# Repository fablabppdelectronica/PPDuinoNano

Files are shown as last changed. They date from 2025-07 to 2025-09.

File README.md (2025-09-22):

# MÓDULO EDUCATIVO: PPDuino Nano
## Presentación
Los módulos educativos son una herramienta invaluable para los estudiantes, que les permite aprender de forma tangible y efectiva los conocimientos de cada Unidad Didáctica.

El presente proyecto es una iniciativa innovadora que busca desarrollar un **módulo educativo de codigo abierto** que permitirá realizar los laboratorios de multiples unidades d

idáctica, que lo puedan fabricar los docentes o estudiantes y que permita trabajar con:
- Electrónica Analógica
- Electrónica Digital
- Electrónica Potencia
- Programación Embebida
- Redes
- Telecomunicaciones, entre otras.

El proyecto esta desarrollado por los docentes y estudiantes del Programa de Electronica Industrial.
## Proyecto PPDuino
Para esta primera etapa e inspirados por dispositivos PLCs como el S7-1200 y Logo de Siemens, el objetivo es disenar y fabricar un módulo educativo tipo PLC.

Se trabajara en 3 areas:
- Diseño Electronico.
- Diseño 2D y 3D.
- Programación.

Mostramos el bosquejo proyectado. 
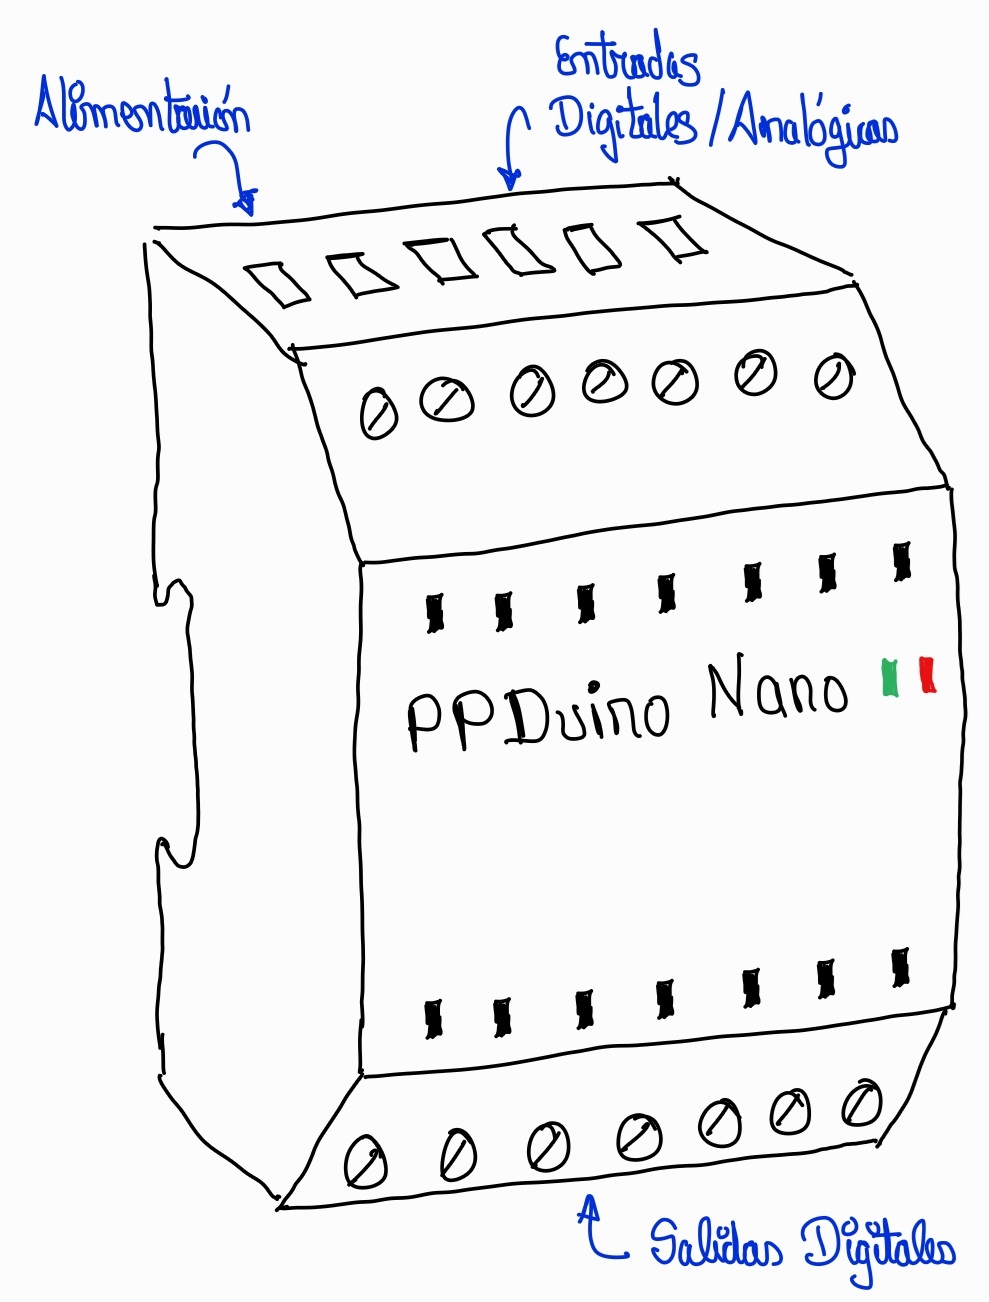
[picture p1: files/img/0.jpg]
<div></div>
Para conseguir el Producto Mínimo Viable, se siguieron la secuencia que se muestra en la imagen:
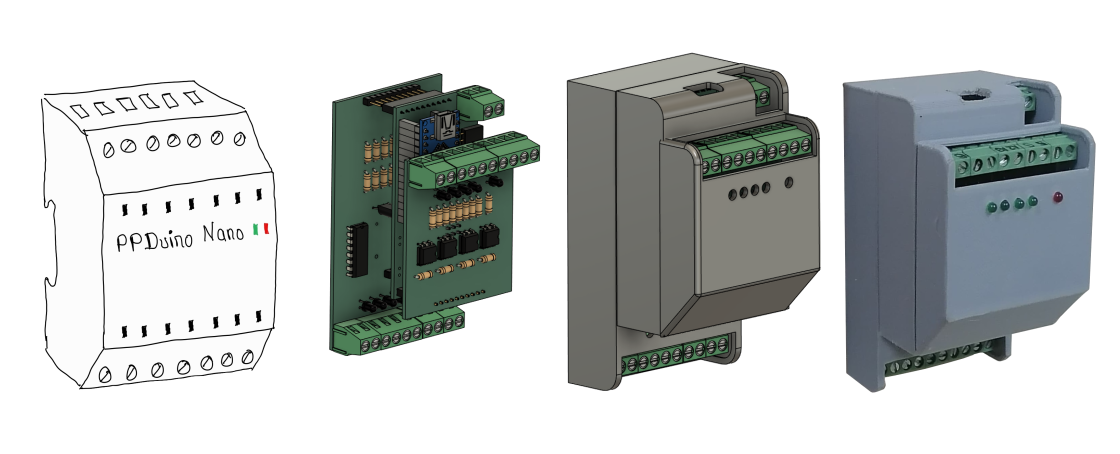
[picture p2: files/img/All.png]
<div></div>

## Diseño Electrónico
### Tarjeta de procesador
Para el desarrollo de la tarjeta del procesador, se trabajo con la tarjeta Arduino Nano por su gran comunidad, facilidad de adquisión local y costo accesible.

#### Lista de componentes
<table><tr><th>Reference</th><td>Value</td><td>Footprint</td><td>Qty</td></tr><tr><th>A1</th><td>Arduino Nano</td><td>Module:Arduino_Nano</td><td>1</td></tr><tr><th>C1</th><td>100uF</td><td>Capacitor_THT:CP_Radial_D5.0mm_P2.50mm</td><td>1</td></tr><tr><th>C2</th><td>10uF</td><td>Capacitor_THT:CP_Radial_D5.0mm_P2.50mm</td><td>1</td></tr><tr><th>J1</th><td>PWR_IN</td><td>Borneras:TerminalBlock_Altech_AK300-2_P5.00mm</td><td>1</td></tr><tr><th>J2</th><td>Conn_01x12</td><td>Connector_PinSocket_2.54mm:PinSocket_1x12_P2.54mm_Horizontal</td><td>1</td></tr><tr><th>J11</th><td>INPUTS</td><td>Connector_PinSocket_2.54mm:PinSocket_1x10_P2.54mm_Vertical</td><td>1</td></tr><tr><th>J12</th><td>OUTPUTS</td><td>Connector_PinHeader_2.54mm:PinHeader_1x10_P2.54mm_Vertical</td><td>1</td></tr><tr><th>U1</th><td>L7805</td><td>Package_TO_SOT_THT:TO-220-3_Horizontal_TabDown</td><td>1</td></tr><tr><th>U6</th><td>+5V</td><td>Codigo_lib:Mini 560 Pro</td><td>1</td></tr></table>

#### Esquematico de procesador
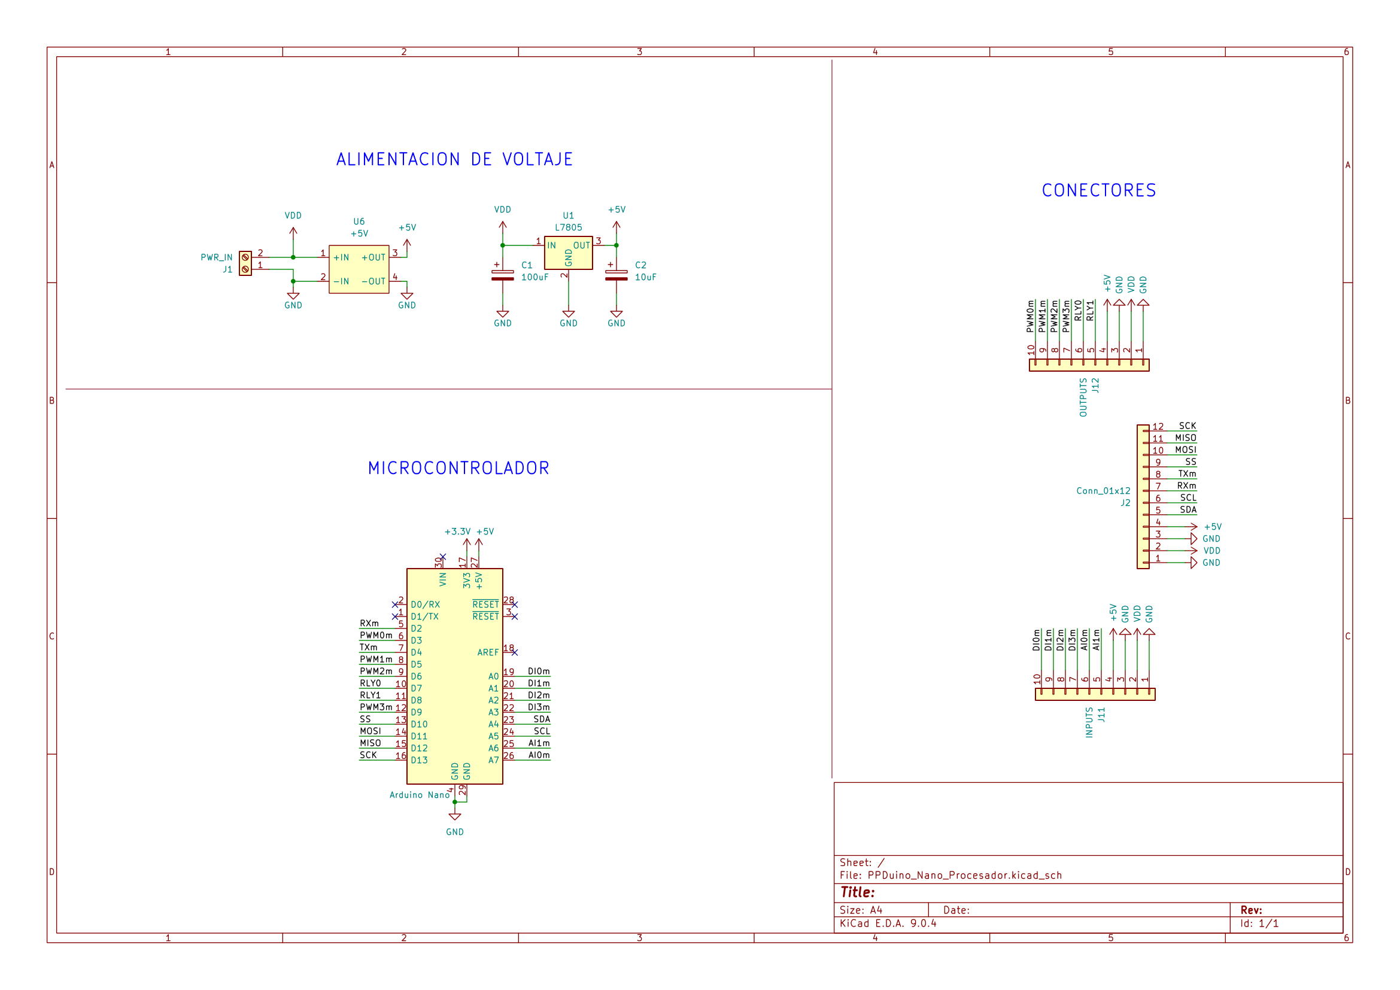
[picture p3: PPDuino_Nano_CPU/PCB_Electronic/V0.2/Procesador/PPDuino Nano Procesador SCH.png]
<div></div>

### Entradas
### Tarjeta de entradas
Para el desarrollo de la tarjeta de entradas se diseño para proporcionar:
* 4 entradas digitales desde +5V a +24V (dependera del voltaje de alimentación)
* 2 entradas analogicas de 0V a +5V epcon la tarjeta Arduino Nano por su gran comunidad, facilidad de adquisión local y costo accesible.

#### Lista de componentes
<table><tr><th>Reference</th><td>Value</td><td>Footprint</td><td>Qty</td></tr><tr><th>D1</th><td>DI0</td><td>LED_THT:LED_D3.0mm_IRBlack</td><td>1</td></tr><tr><th>D2</th><td>DI1</td><td>LED_THT:LED_D3.0mm_IRBlack</td><td>1</td></tr><tr><th>D3</th><td>DI2</td><td>LED_THT:LED_D3.0mm_IRBlack</td><td>1</td></tr><tr><th>D4,D5</th><td>DI3</td><td>LED_THT:LED_D3.0mm_IRBlack</td><td>2</td></tr><tr><th>D6,D7</th><td>Z5.1V</td><td>Diode_THT:D_DO-35_SOD27_P7.62mm_Horizontal</td><td>2</td></tr><tr><th>J2</th><td>DI</td><td>Borneras:TerminalBlock_Altech_AK300-4_P5.00mm</td><td>1</td></tr><tr><th>J3</th><td>AI</td><td>Borneras:TerminalBlock_Altech_AK300-4_P5.00mm</td><td>1</td></tr><tr><th>J10</th><td>PWR_OUT</td><td>Borneras:TerminalBlock_Altech_AK300-2_P5.00mm</td><td>1</td></tr><tr><th>J11</th><td>INPUTS</td><td>Connector_PinHeader_2.54mm:PinHeader_1x10_P2.54mm_Vertical</td><td>1</td></tr><tr><th>Q1,Q2,Q3,Q4</th><td>BC548</td><td>Package_TO_SOT_THT:TO-92L_Inline_Wide</td><td>4</td></tr><tr><th>R1,R2,R3,R4,R5,<br>R6,R7,R8,R9,R10,<br>R11,R12,R14,<br>R15,R16,R17</th><td>2.2k</td><td>Resistor_THT:R_Axial_DIN0207_L6.3mm_D2.5mm_P7.62mm_Horizontal</td><td>16</td></tr><tr><th>R13</th><td>1k</td><td>Resistor_THT:R_Axial_DIN0207_L6.3mm_D2.5mm_P7.62mm_Horizontal</td><td>1</td></tr></table>

#### Esquematico de entradas
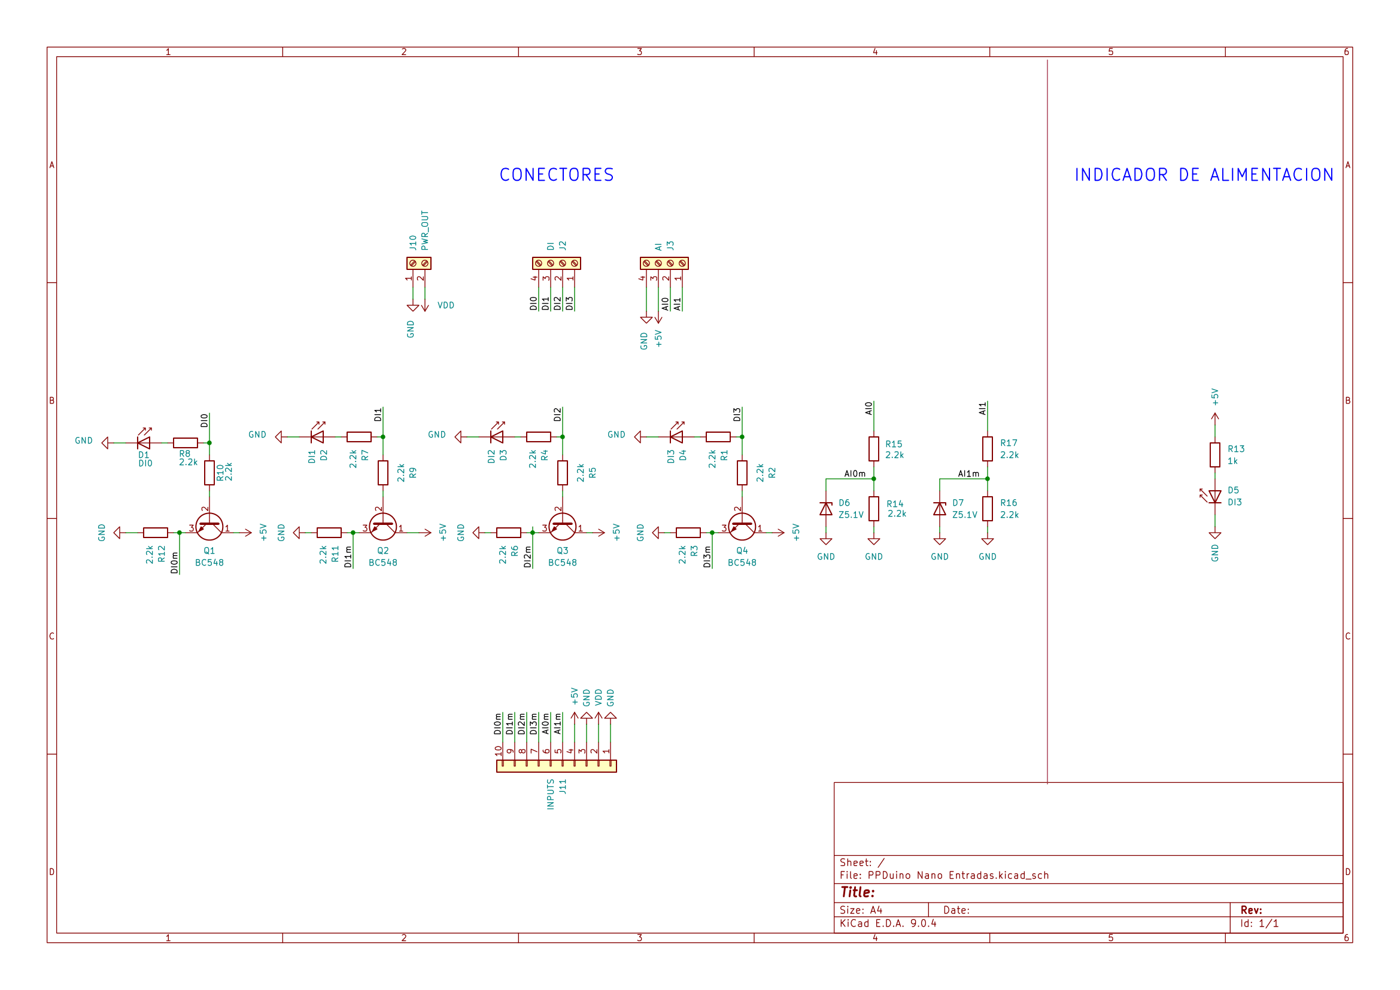
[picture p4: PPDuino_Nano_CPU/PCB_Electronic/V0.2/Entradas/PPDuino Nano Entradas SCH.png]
<div></div>

### Salidas
### Tarjeta de salidas
Para el desarrollo de la tarjeta del procesador, se tabajo con la tarjeta Arduino Nano por su gran comunidad, facilidad de adquisión local y costo accesible.

#### Lista de componentes
<table><tr><th>Reference</th><td>Value</td><td>Footprint</td><td>Qty</td></tr><tr><th>D5,J14</th><td>RLY0</td><td>Borneras:TerminalBlock_Altech_AK300-2_P5.00mm,LED_THT:LED_D3.0mm_IRBlack</td><td>2</td></tr><tr><th>D6,D8</th><td>1N4148</td><td>Diode_THT:D_DO-35_SOD27_P7.62mm_Horizontal</td><td>2</td></tr><tr><th>D7,J7</th><td>RLY1</td><td>Borneras:TerminalBlock_Altech_AK300-2_P5.00mm,LED_THT:LED_D3.0mm_IRBlack</td><td>2</td></tr><tr><th>D9</th><td>DI3</td><td>LED_THT:LED_D3.0mm_IRBlack</td><td>1</td></tr><tr><th>D10</th><td>DI2</td><td>LED_THT:LED_D3.0mm_IRBlack</td><td>1</td></tr><tr><th>D11</th><td>DI1</td><td>LED_THT:LED_D3.0mm_IRBlack</td><td>1</td></tr><tr><th>D12</th><td>DI0</td><td>LED_THT:LED_D3.0mm_IRBlack</td><td>1</td></tr><tr><th>J6</th><td>SEL0</td><td>Connector_PinHeader_2.54mm:PinHeader_1x03_P2.54mm_Vertical</td><td>1</td></tr><tr><th>J8</th><td>PWM</td><td>Borneras:TerminalBlock_Altech_AK300-4_P5.00mm</td><td>1</td></tr><tr><th>J9</th><td>PWR_OUT</td><td>Borneras:TerminalBlock_Altech_AK300-2_P5.00mm</td><td>1</td></tr><tr><th>J12</th><td>OUTPUTS</td><td>Connector_PinHeader_2.54mm:PinHeader_1x10_P2.54mm_Vertical</td><td>1</td></tr><tr><th>J13</th><td>SEL1</td><td>Connector_PinHeader_2.54mm:PinHeader_1x03_P2.54mm_Vertical</td><td>1</td></tr><tr><th>K1,K2</th><td>~</td><td>Codigo_lib:Relay</td><td>2</td></tr><tr><th>Q1,Q2</th><td>BC548</td><td>Package_TO_SOT_THT:TO-92L_Inline_Wide</td><td>2</td></tr><tr><th>R13,R14,R15,<br>R16,R17,R18,<br>R19,R20</th><td>330</td><td>Resistor_THT:R_Axial_DIN0207_L6.3mm_D2.5mm_P7.62mm_Horizontal</td><td>8</td></tr><tr><th>U5</th><td>L293D</td><td>Package_DIP:DIP-16_W7.62mm_LongPads</td><td>1</td></tr></table>

#### Esquematico de salidas
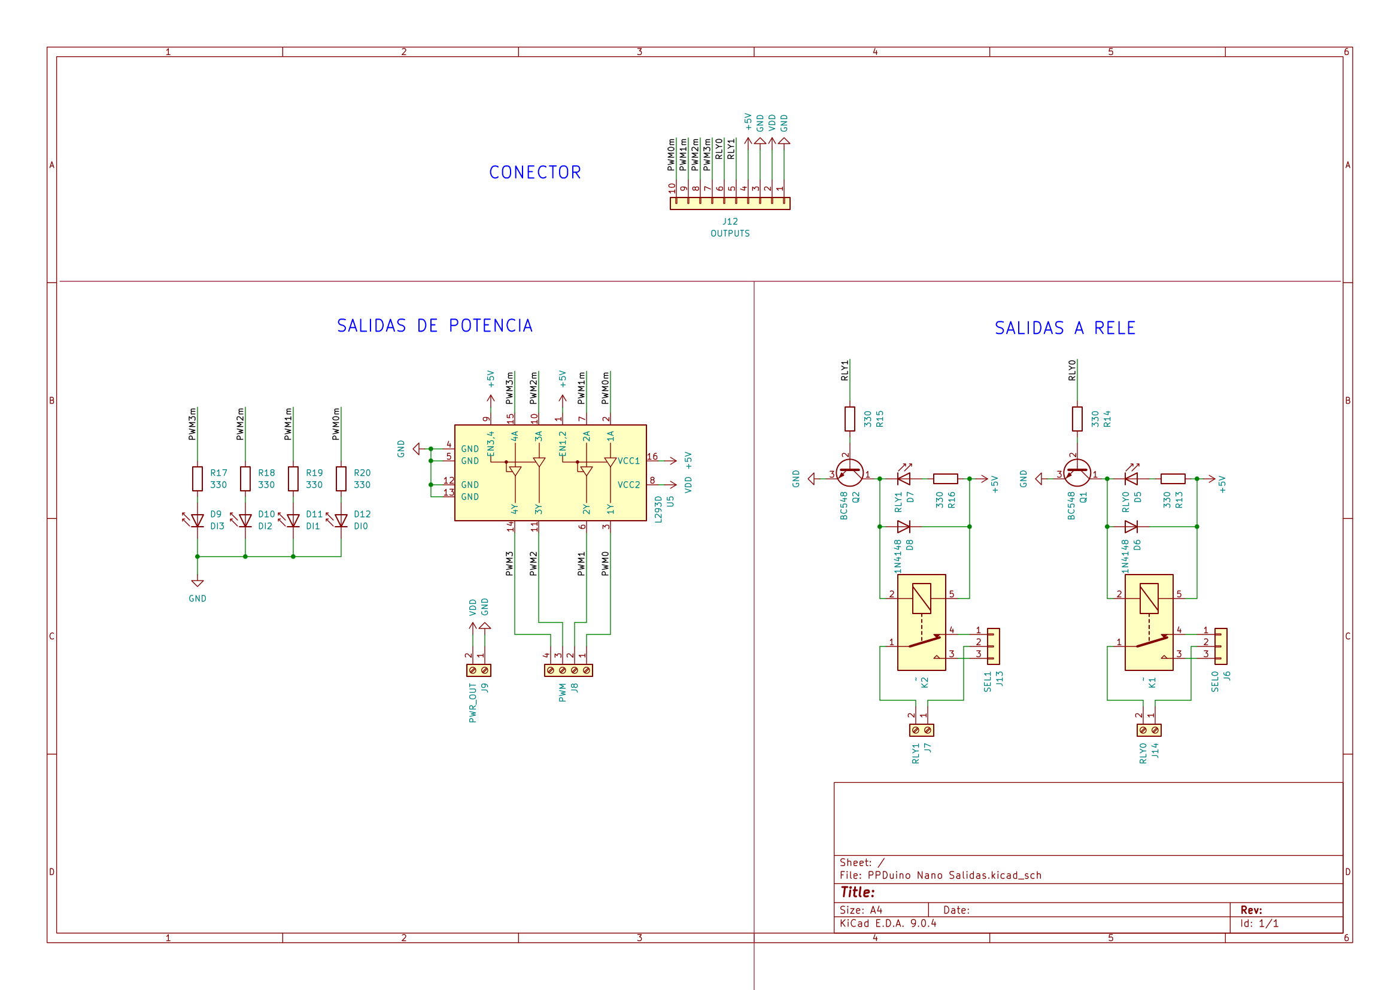
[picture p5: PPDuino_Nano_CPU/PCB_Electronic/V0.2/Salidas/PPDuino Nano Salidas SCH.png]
<div></div>

## Fabricacion
### Impresión 3D
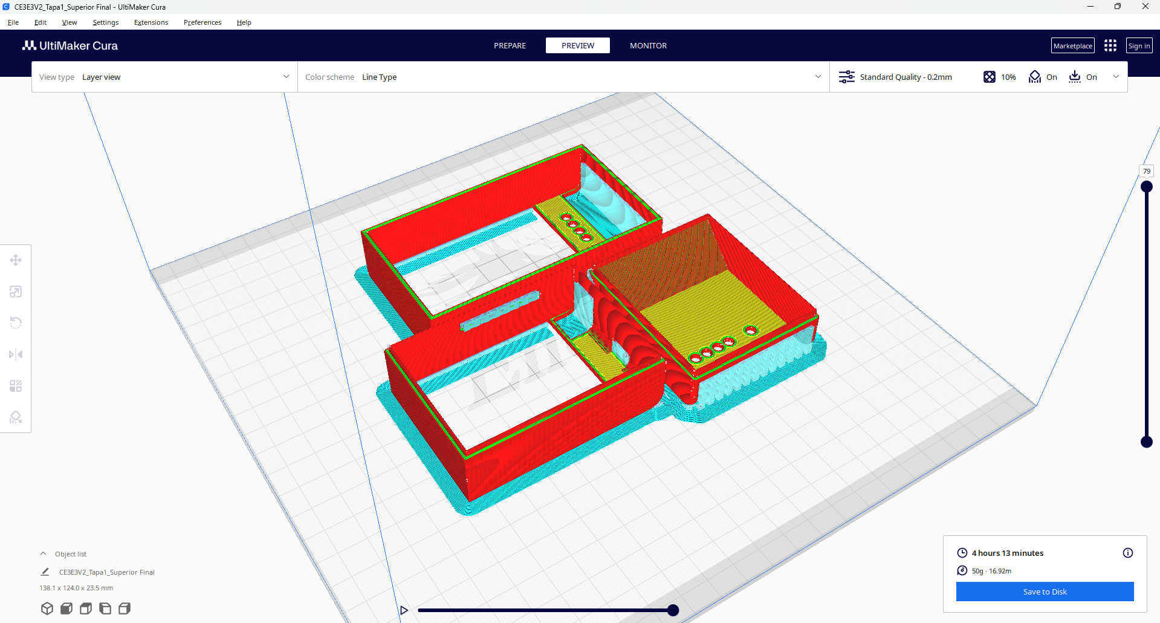
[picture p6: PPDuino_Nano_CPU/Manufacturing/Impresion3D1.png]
<div></div>

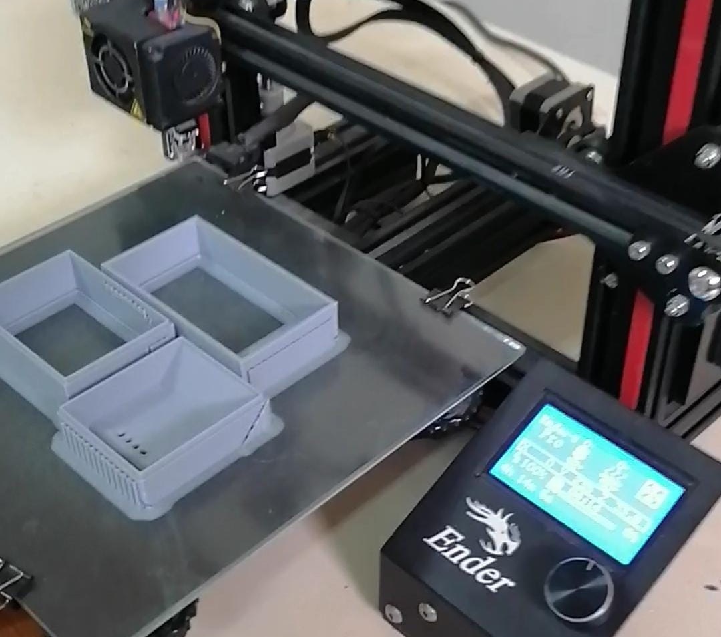
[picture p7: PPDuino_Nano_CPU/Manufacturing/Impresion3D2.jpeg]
<div></div>

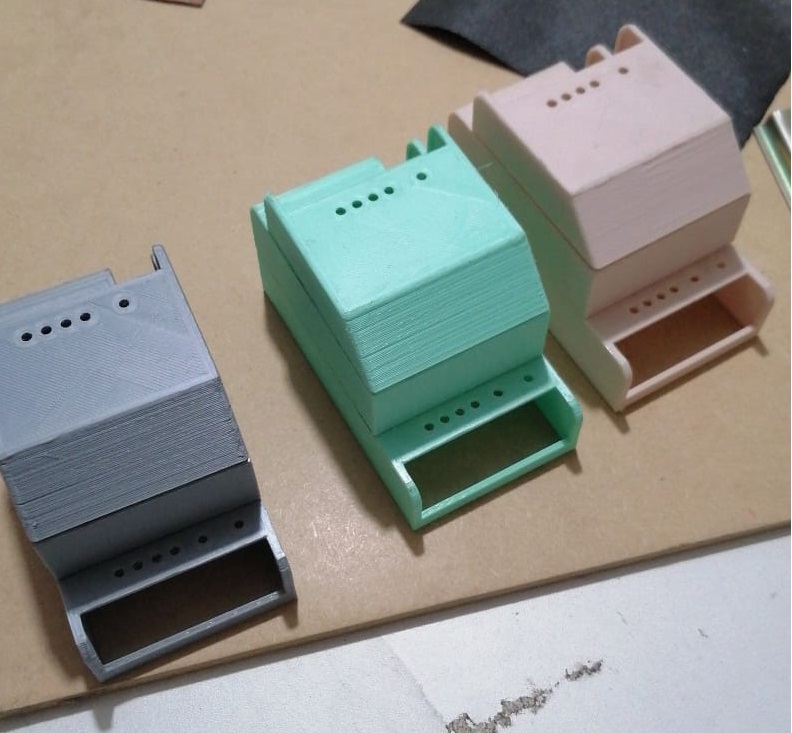
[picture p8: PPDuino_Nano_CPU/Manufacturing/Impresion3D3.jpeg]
<div></div>

### Fabricacion de PCB

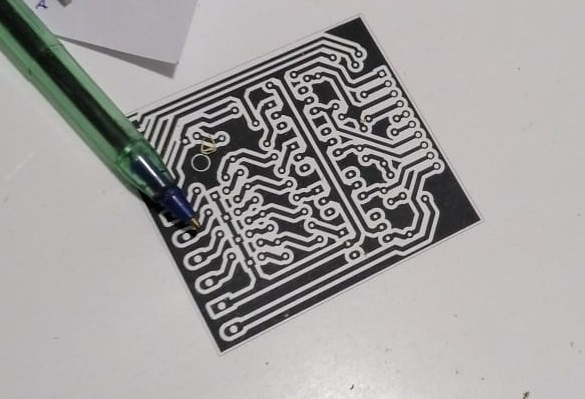
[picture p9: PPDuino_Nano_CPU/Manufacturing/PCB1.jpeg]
<div></div>

## Programación
### Programación con Arduino IDE (C++)

Descarguemos el software para programar el Arduino Nano en [Descargar Arduino IDE](https://www.arduino.cc/en/software/)

Reconoscamos las herramientas de Arduino IDE
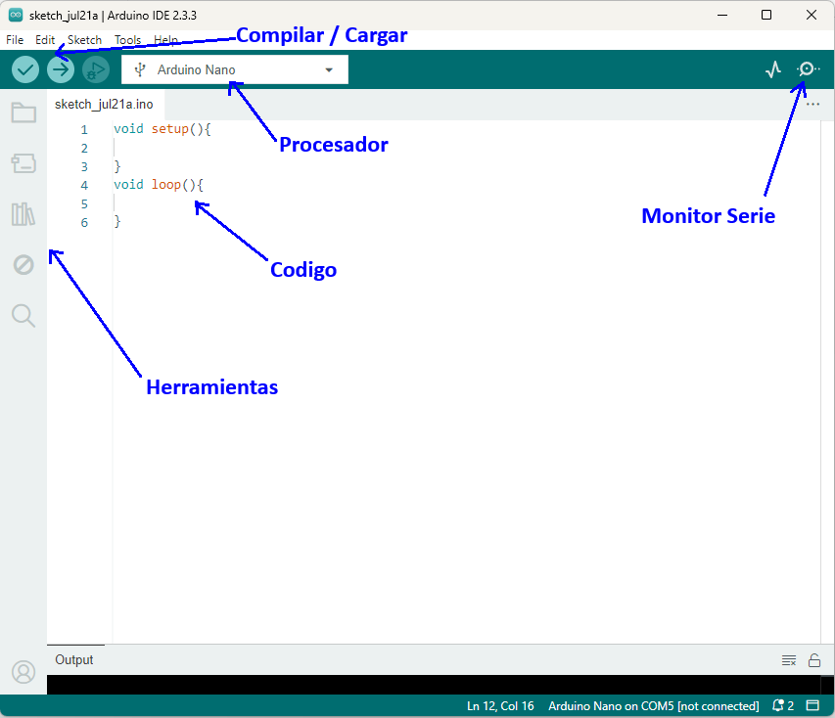
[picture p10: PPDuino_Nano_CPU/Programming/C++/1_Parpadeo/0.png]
<div></div>

Seleccionar en BOARDS: Arduino Nano
Seleccionar en PORTS: COMx (Dependera del puerto asignado desde su computadora)
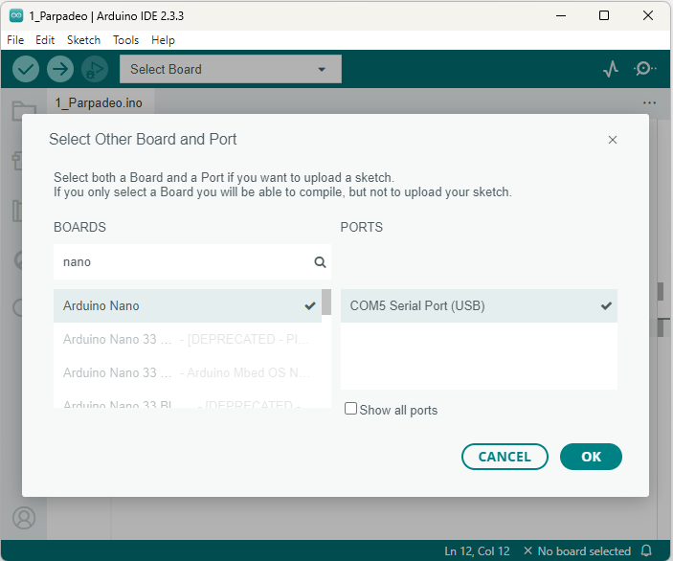
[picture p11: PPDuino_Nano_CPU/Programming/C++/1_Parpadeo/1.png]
<div></div>

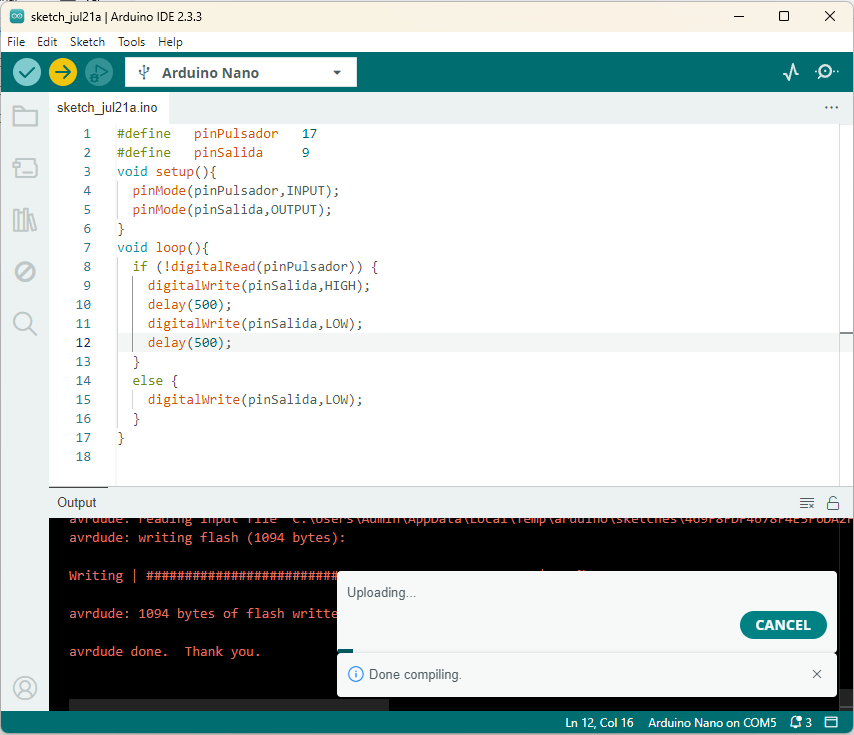
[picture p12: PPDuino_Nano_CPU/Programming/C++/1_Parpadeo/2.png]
<div></div>

### Programación con OpenPLC IDE (Ladder)

Descarguemos el software OpenPLC para programar el Arduino Nano en [Descargar OpenPLC](https://autonomylogic.com/)

Reconoscamos las herramientas de OpenPLC
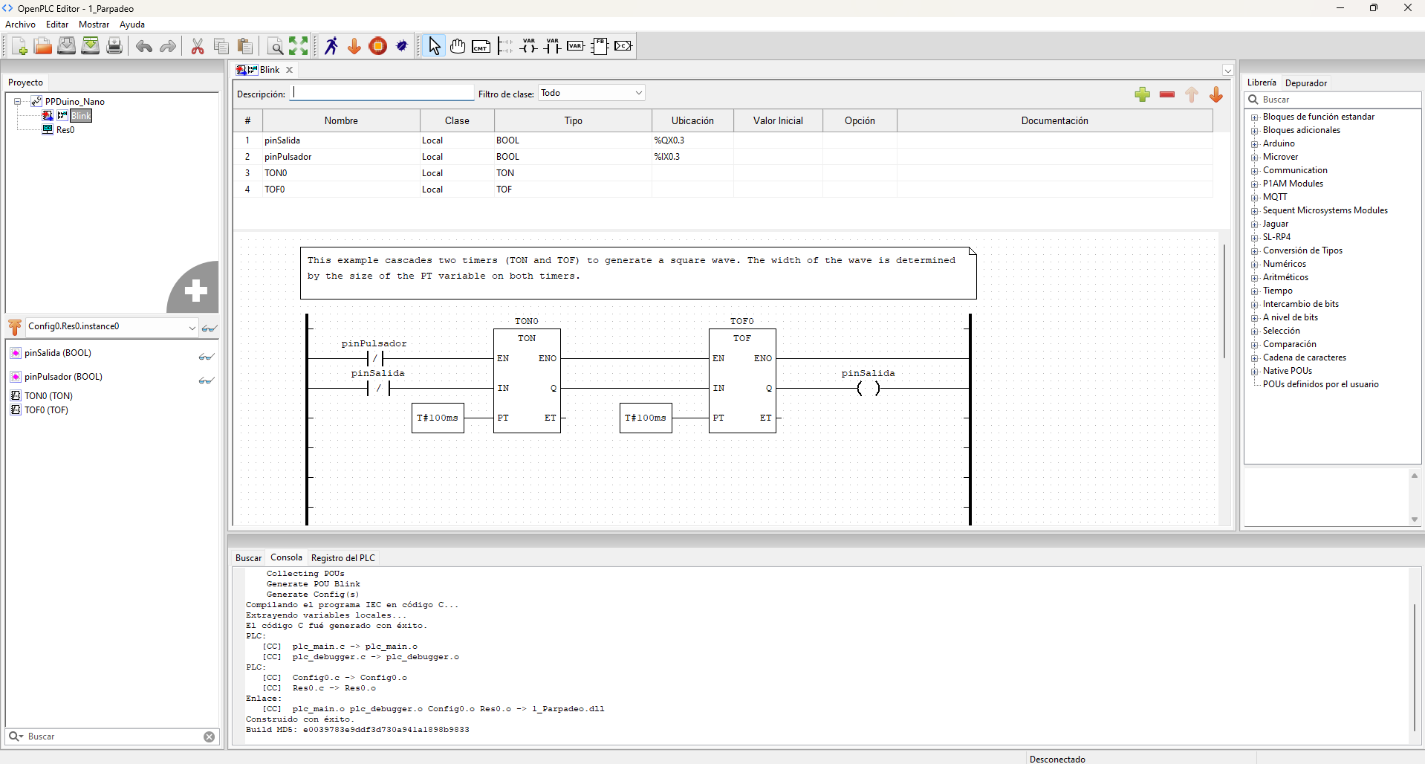
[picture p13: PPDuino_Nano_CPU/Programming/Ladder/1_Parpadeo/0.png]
<div></div>

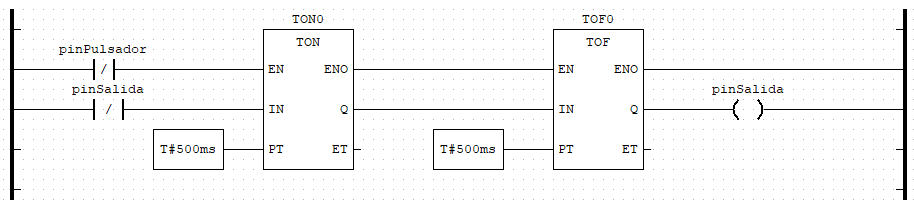
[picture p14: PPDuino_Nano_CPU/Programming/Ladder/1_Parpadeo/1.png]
<div></div>

<div><p style = 'text-align:center;'>JuveYell</p></div>

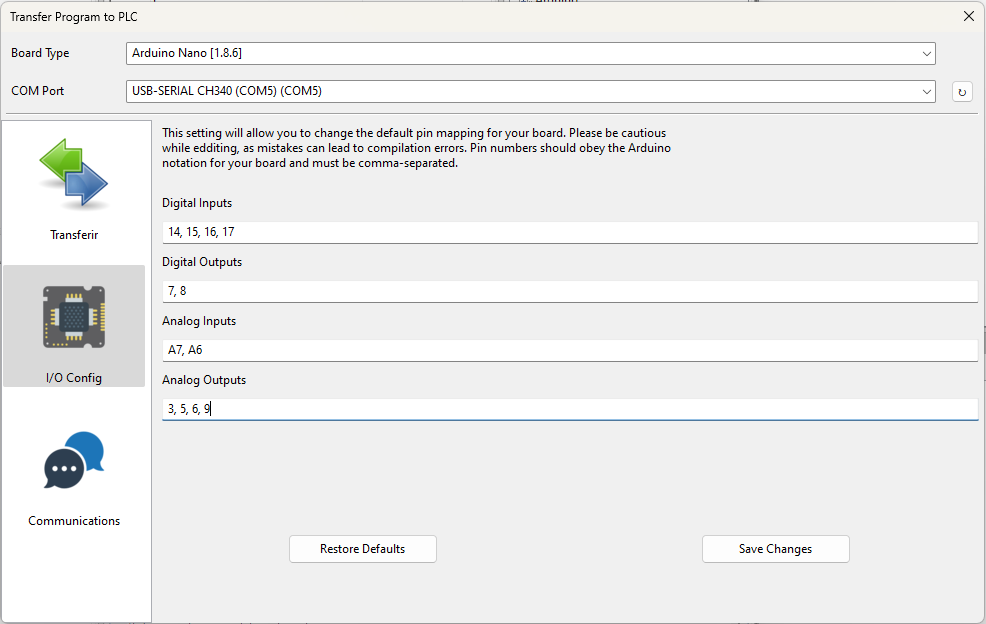
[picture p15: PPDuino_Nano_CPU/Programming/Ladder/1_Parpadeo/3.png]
<div></div>

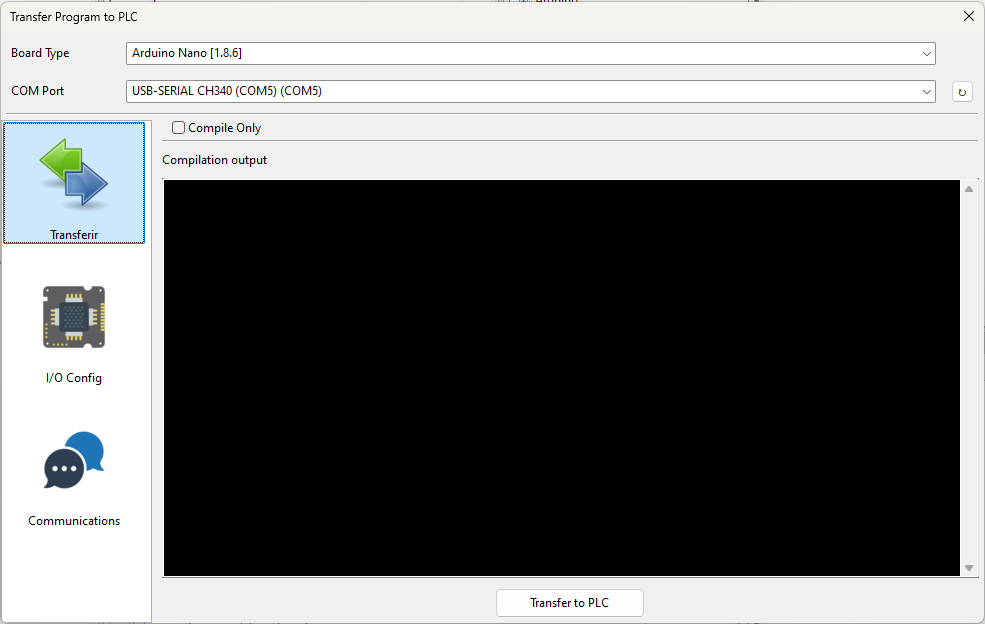
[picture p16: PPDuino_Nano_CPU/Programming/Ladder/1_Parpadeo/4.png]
<div></div>

### Programación con Fab Blocks (Bloques)

Descarguemos el software Fab Blocks IDE para programar el Arduino Nano en [Descargar Fab Blocks IDE](https://github.com/codigospace/Fab-Blocks-IDE/releases)

Reconoscamos las herramientas de Fab Blocks IDE
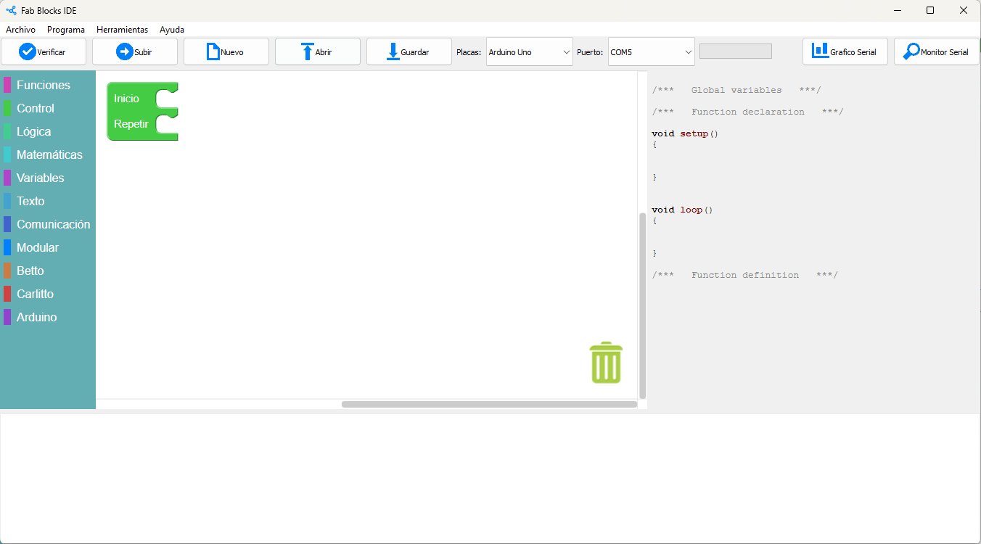
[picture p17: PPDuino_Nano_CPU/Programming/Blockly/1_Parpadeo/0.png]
<div></div>

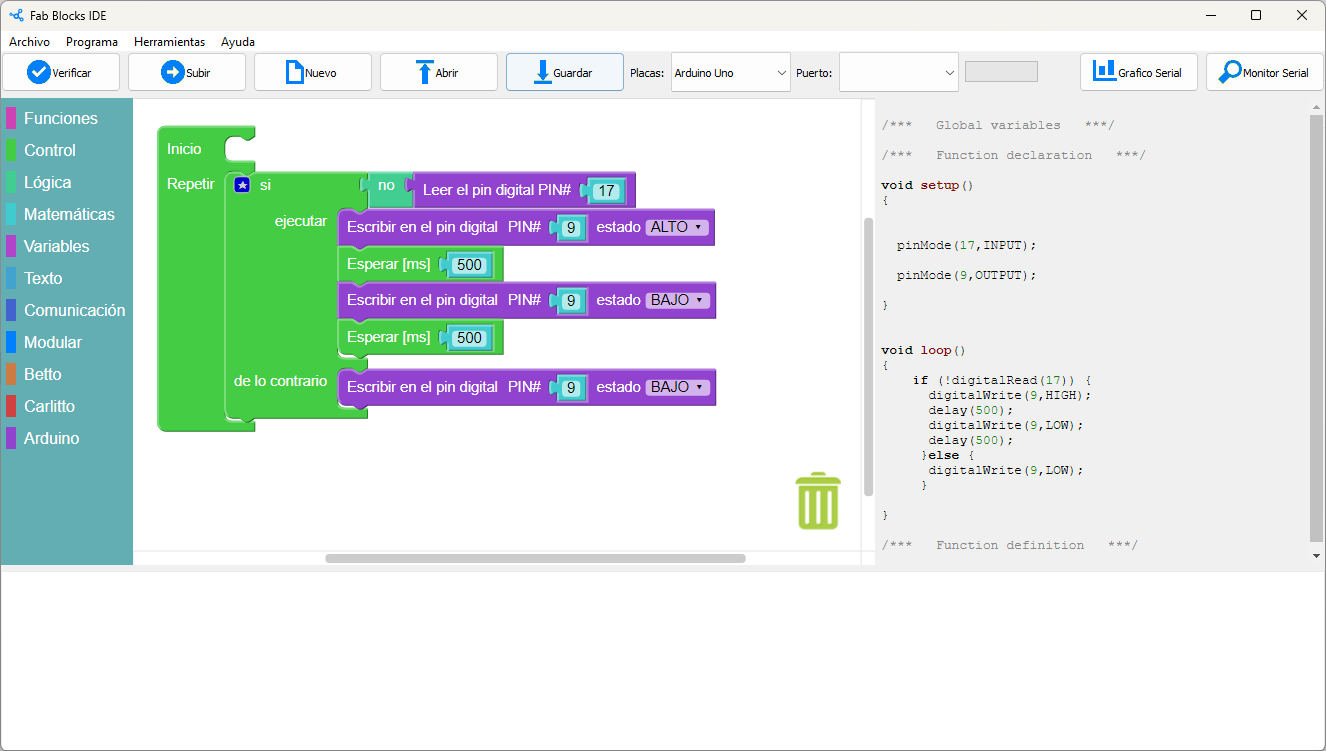
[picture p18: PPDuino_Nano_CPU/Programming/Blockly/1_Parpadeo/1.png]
<div></div>

<div><p style = 'text-align:center;'>JuveYell</p></div>

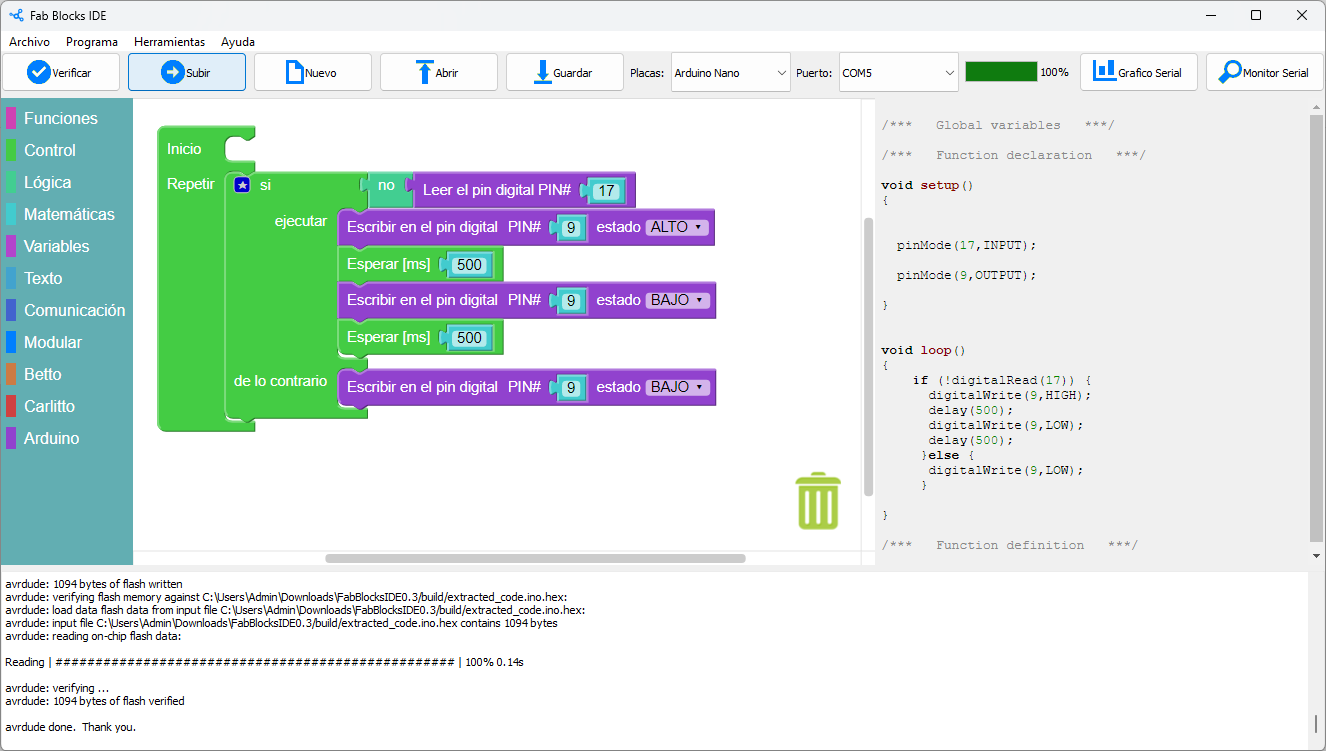
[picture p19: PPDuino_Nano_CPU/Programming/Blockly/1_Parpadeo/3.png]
<div></div>

# NOSOTROS
## IESTP Pedro P. Díaz
Somos el Instituto Superior Pedro P. Díaz de la cuidad de Arequipa en Perú, formamos profesionales que aportan desarrollo a la comunidad, región y pais.
Estamos ubicados en Arequipa, una cuidad cálida, rodeada de 3 volcanes, con una zona céntrica de arquitectura barroca construida de sillar, una piedra volcánica blanca, razon para denominarla "La Cuidad Blanca".
La instalación del instituto esta ubicada en Av. Pizarro 130 de Jose Luis Bustamante y Rivero.
## Programa de Electrónica Industrial
Somos el Programa de Electrónica Industrial del IESTP Pedro P. Diaz.
## Fab Lab PPD Electronica
Somos el laboratorio de fabricación digital del programa de Electrónica Industrial, que empodera a la comunidad educativa con capacitaciones y equipamiento para que fabriquen casi cualquier cosas.

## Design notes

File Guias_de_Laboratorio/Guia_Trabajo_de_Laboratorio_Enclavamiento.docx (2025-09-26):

# Guía de Trabajo de Laboratorio

Tema: Enclavamiento y Desenclavamiento con PPDuino Nano

# 🎯 Objetivos

• Comprender el concepto de enclavamiento electrónico mediante el uso de un pulsador y un LED.

• Aplicar un algoritmo de control en el módulo educativo PPDuino Nano.

• Reconocer la importancia del anti-rebote en sistemas digitales.

• Relacionar el uso del pulsador externo como dispositivo de entrada con el control de salidas.

# 📦 Materiales requeridos

• 1 módulo educativo PPDuino Nano

• 1 pulsador externo

• 1 resistencia de 10 kΩ (solo si no se usa la resistencia interna de pull-up)

• Cables de conexión (jumpers)

• Computadora con Arduino IDE instalado

• Cable USB para conexión al PPDuino Nano

# 📖 Conceptos previos

• Enclavamiento: un sistema que mantiene su estado (encendido/apagado) hasta que reciba una nueva orden.

• Toggle: cada pulsación del pulsador alterna el estado de la salida.

• Anti-rebote: evita lecturas falsas cuando se presiona un botón mecánico.

• PPDuino Nano: módulo educativo con componentes integrados (LEDs, resistencias, salidas), donde el estudiante se enfoca en el algoritmo.

# ⚙️ Circuito a implementar

- LED integrado en el pin 9 del PPDuino Nano (no requiere montaje externo).
- Pulsador externo conectado entre el pin 17 y GND.
- El programa usará la resistencia de pull-up interna del microcontrolador.

# 💻 Programa en Arduino IDE

const int pinPulsador = 17; // Pulsador externo
const int pinSalida = 9; // LED integrado en el PPDuino Nano

unsigned long lastDebounceTime = 0;
const unsigned long debounceDelay = 50; // Tiempo de anti-rebote (ms)

int lastButtonState = HIGH;
int buttonState = HIGH;
bool salidaLatched = false; // Estado actual del LED

void setup() {
pinMode(pinPulsador, INPUT_PULLUP);
pinMode(pinSalida, OUTPUT);
digitalWrite(pinSalida, LOW);
}

void loop() {
int reading = digitalRead(pinPulsador);

if (reading != lastButtonState) {
lastDebounceTime = millis();
}

if ((millis() - lastDebounceTime) > debounceDelay) {
if (reading != buttonState) {
buttonState = reading;
if (buttonState == LOW) {
salidaLatched = !salidaLatched;
digitalWrite(pinSalida, salidaLatched ? HIGH : LOW);
}
}
}

lastButtonState = reading;
}

# 🧪 Procedimiento

• Conectar el pulsador externo entre el pin 17 del PPDuino Nano y GND.

• Conectar la placa al computador mediante el cable USB.

• Abrir Arduino IDE y copiar el código del programa.

• Compilar y cargar el programa en el PPDuino Nano.

• Presionar el pulsador y observar el comportamiento del LED en el pin 9: Una pulsación lo enciende, la siguiente lo apaga, y así sucesivamente.

# 📚 Actividades de análisis

• Dibujar el diagrama lógico del sistema (entrada: pulsador, salida: LED).

• Identificar en el código la línea que genera el enclavamiento (salidaLatched = !salidaLatched;).

• Explicar por qué se usa la instrucción INPUT_PULLUP en el pulsador.

• Analizar qué pasaría si no se aplicara anti-rebote.

• Investigar cómo se implementa el enclavamiento en circuitos eléctricos industriales (ej. contactores con botones de marcha y paro).

• Proponer una modificación al código para incluir un segundo pulsador de RESET que apague el LED.

# 📝 Conclusiones

1. ________________________________________________

2. ________________________________________________

3. ________________________________________________

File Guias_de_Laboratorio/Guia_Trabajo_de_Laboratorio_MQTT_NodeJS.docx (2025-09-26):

# Guía de Laboratorio: Control y Monitoreo con Node.js, MQTT y Gráficos en Tiempo Real

# 🎯 Objetivos

- Configurar un servidor con Node.js y Express.
- Integrar el paquete MQTT para publicar y suscribirse a tópicos.
- Crear un frontend responsivo en HTML con botones que publiquen mensajes MQTT.
- Visualizar datos recibidos de un tópico MQTT en un gráfico en tiempo real estilo osciloscopio.

# 🛠️ Materiales

- PC con Node.js instalado (v14 o superior).
- Editor de código (Visual Studio Code recomendado).
- Paquetes npm: express, mqtt, socket.io.
- Navegador web.
- Un broker MQTT local o en la nube (ej. Mosquitto, HiveMQ, EMQX, etc.).

# 📌 Desarrollo

## 1. Inicializar proyecto Node.js

mkdir lab-mqtt
cd lab-mqtt
npm init -y
npm install express mqtt socket.io

## 2. Crear servidor con Express y MQTT

Archivo server.js:
- Configura un servidor Express que sirva un archivo index.html.
- Conecta al broker MQTT.
- Expone rutas /on y /off para que el frontend publique al tópico codigo/relay.
- Se suscribe al tópico codigo/sensor y reenvía datos al navegador con Socket.io.

## 3. Crear carpeta public con index.html

Este archivo contiene:
- Dos botones (ON y OFF) que hacen fetch al servidor.
- Un campo <div> para mostrar el valor recibido del sensor.
- Un gráfico con Chart.js en tiempo real que recibe los datos desde Socket.io.
- Estilos CSS para hacerlo responsivo y con diseño moderno.

## 4. Integrar Chart.js

Se carga desde CDN:
<script src="https://cdn.jsdelivr.net/npm/chart.js"></script>
- Se configura un gráfico de tipo line.
- Se fija el eje Y entre 0 y 1030.
- Se limita a mostrar solo los últimos 20 puntos.

## 5. Responsividad y estilo

- Los botones tienen colores verde/rojo.
- El gráfico ocupa el 90% de la pantalla vertical.
- La interfaz se adapta en móviles y pantallas pequeñas.

# ▶️ Ejecución

1. Levantar el servidor:
node server.js

2. Abrir navegador en:
http://localhost:3000

3. Probar los botones ON y OFF → Se publican mensajes en el tópico codigo/relay.
4. Publicar mensajes en el broker en el tópico codigo/sensor → Se visualizan en el gráfico en tiempo real.

# 📚 Resultados esperados

- Al presionar los botones se envían mensajes MQTT.
- En el navegador se observa el valor actual del sensor en texto y en un gráfico de línea.
- El gráfico se comporta como un osciloscopio simple, avanzando en el tiempo.

# 📝 Tarea para el estudiante

👉 Modificar el proyecto para que soporte:
1. Cuatro botones, que publiquen en el mismo tópico codigo/relay con los siguientes valores:
- ON1, OFF1, ON2, OFF2.
2. Dos gráficos independientes en la misma página, mostrando valores de:
- codigo/sensor1
- codigo/sensor2.

💡 Reto adicional:
- Hacer que cada gráfico tenga un color distinto (ej. azul y rojo).
- Organizar los botones en una cuadrícula responsiva.

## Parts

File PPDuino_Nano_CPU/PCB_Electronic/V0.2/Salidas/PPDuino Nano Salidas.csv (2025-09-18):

Reference | Value | Datasheet | Footprint | Qty | DNP
D5,J14 | RLY0 | http://www.everlight.com/file/ProductFile/IR204-A.pdf,~ | Borneras:TerminalBlock_Altech_AK300-2_P5.00mm,LED_THT:LED_D3.0mm_IRBlack | 2
D6,D8 | 1N4148 | https://assets.nexperia.com/documents/data-sheet/1N4148_1N4448.pdf | Diode_THT:D_DO-35_SOD27_P7.62mm_Horizontal | 2
D7,J7 | RLY1 | http://www.everlight.com/file/ProductFile/IR204-A.pdf,~ | Borneras:TerminalBlock_Altech_AK300-2_P5.00mm,LED_THT:LED_D3.0mm_IRBlack | 2
D9 | DI3 | http://www.everlight.com/file/ProductFile/IR204-A.pdf | LED_THT:LED_D3.0mm_IRBlack | 1
D10 | DI2 | http://www.everlight.com/file/ProductFile/IR204-A.pdf | LED_THT:LED_D3.0mm_IRBlack | 1
D11 | DI1 | http://www.everlight.com/file/ProductFile/IR204-A.pdf | LED_THT:LED_D3.0mm_IRBlack | 1
D12 | DI0 | http://www.everlight.com/file/ProductFile/IR204-A.pdf | LED_THT:LED_D3.0mm_IRBlack | 1
J6 | SEL0 | ~ | Connector_PinHeader_2.54mm:PinHeader_1x03_P2.54mm_Vertical | 1
J8 | PWM | ~ | Borneras:TerminalBlock_Altech_AK300-4_P5.00mm | 1
J9 | PWR_OUT | ~ | Borneras:TerminalBlock_Altech_AK300-2_P5.00mm | 1
J12 | OUTPUTS | ~ | Connector_PinHeader_2.54mm:PinHeader_1x10_P2.54mm_Vertical | 1
J13 | SEL1 | ~ | Connector_PinHeader_2.54mm:PinHeader_1x03_P2.54mm_Vertical | 1
K1,K2 | ~ |  | Codigo_lib:Relay | 2
Q1,Q2 | BC548 | https://www.onsemi.com/pub/Collateral/BC550-D.pdf | Package_TO_SOT_THT:TO-92L_Inline_Wide | 2
R13,R14,R15,R16,R17,R18,R19,R20 | 330 | ~ | Resistor_THT:R_Axial_DIN0207_L6.3mm_D2.5mm_P7.62mm_Horizontal | 8
U5 | L293D | http://www.ti.com/lit/ds/symlink/l293.pdf | Package_DIP:DIP-16_W7.62mm_LongPads | 1

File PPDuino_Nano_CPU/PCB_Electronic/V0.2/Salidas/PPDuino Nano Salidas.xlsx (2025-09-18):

Reference | Value | Footprint | Qty
D5,J14 | RLY0 | Borneras:TerminalBlock_Altech_AK300-2_P5.00mm,LED_THT:LED_D3.0mm_IRBlack | 2
D6,D8 | 1N4148 | Diode_THT:D_DO-35_SOD27_P7.62mm_Horizontal | 2
D7,J7 | RLY1 | Borneras:TerminalBlock_Altech_AK300-2_P5.00mm,LED_THT:LED_D3.0mm_IRBlack | 2
D9 | DI3 | LED_THT:LED_D3.0mm_IRBlack | 1
D10 | DI2 | LED_THT:LED_D3.0mm_IRBlack | 1
D11 | DI1 | LED_THT:LED_D3.0mm_IRBlack | 1
D12 | DI0 | LED_THT:LED_D3.0mm_IRBlack | 1
J6 | SEL0 | Connector_PinHeader_2.54mm:PinHeader_1x03_P2.54mm_Vertical | 1
J8 | PWM | Borneras:TerminalBlock_Altech_AK300-4_P5.00mm | 1
J9 | PWR_OUT | Borneras:TerminalBlock_Altech_AK300-2_P5.00mm | 1
J12 | OUTPUTS | Connector_PinHeader_2.54mm:PinHeader_1x10_P2.54mm_Vertical | 1
J13 | SEL1 | Connector_PinHeader_2.54mm:PinHeader_1x03_P2.54mm_Vertical | 1
K1,K2 | ~ | Codigo_lib:Relay | 2
Q1,Q2 | BC548 | Package_TO_SOT_THT:TO-92L_Inline_Wide | 2
R13,R14,R15, R16,R17,R18, R19,R20 | 330 | Resistor_THT:R_Axial_DIN0207_L6.3mm_D2.5mm_P7.62mm_Horizontal | 8
U5 | L293D | Package_DIP:DIP-16_W7.62mm_LongPads | 1

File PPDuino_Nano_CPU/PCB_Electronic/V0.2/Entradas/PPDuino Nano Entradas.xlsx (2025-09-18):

Reference | Value | Footprint | Qty
D1 | DI0 | LED_THT:LED_D3.0mm_IRBlack | 1
D2 | DI1 | LED_THT:LED_D3.0mm_IRBlack | 1
D3 | DI2 | LED_THT:LED_D3.0mm_IRBlack | 1
D4,D5 | DI3 | LED_THT:LED_D3.0mm_IRBlack | 2
D6,D7 | Z5.1V | Diode_THT:D_DO-35_SOD27_P7.62mm_Horizontal | 2
J2 | DI | Borneras:TerminalBlock_Altech_AK300-4_P5.00mm | 1
J3 | AI | Borneras:TerminalBlock_Altech_AK300-4_P5.00mm | 1
J10 | PWR_OUT | Borneras:TerminalBlock_Altech_AK300-2_P5.00mm | 1
J11 | INPUTS | Connector_PinHeader_2.54mm:PinHeader_1x10_P2.54mm_Vertical | 1
Q1,Q2,Q3,Q4 | BC548 | Package_TO_SOT_THT:TO-92L_Inline_Wide | 4
R1,R2,R3,R4,R5, R6,R7,R8,R9,R10, R11,R12,R14, R15,R16,R17 | 2.2k | Resistor_THT:R_Axial_DIN0207_L6.3mm_D2.5mm_P7.62mm_Horizontal | 16
R13 | 1k | Resistor_THT:R_Axial_DIN0207_L6.3mm_D2.5mm_P7.62mm_Horizontal | 1

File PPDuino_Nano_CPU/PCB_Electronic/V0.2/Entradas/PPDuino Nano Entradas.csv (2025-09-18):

Reference | Value | Datasheet | Footprint | Qty | DNP
D1 | DI0 | http://www.everlight.com/file/ProductFile/IR204-A.pdf | LED_THT:LED_D3.0mm_IRBlack | 1
D2 | DI1 | http://www.everlight.com/file/ProductFile/IR204-A.pdf | LED_THT:LED_D3.0mm_IRBlack | 1
D3 | DI2 | http://www.everlight.com/file/ProductFile/IR204-A.pdf | LED_THT:LED_D3.0mm_IRBlack | 1
D4,D5 | DI3 | http://www.everlight.com/file/ProductFile/IR204-A.pdf | LED_THT:LED_D3.0mm_IRBlack | 2
D6,D7 | Z5.1V | ~ | Diode_THT:D_DO-35_SOD27_P7.62mm_Horizontal | 2
J2 | DI | ~ | Borneras:TerminalBlock_Altech_AK300-4_P5.00mm | 1
J3 | AI | ~ | Borneras:TerminalBlock_Altech_AK300-4_P5.00mm | 1
J10 | PWR_OUT | ~ | Borneras:TerminalBlock_Altech_AK300-2_P5.00mm | 1
J11 | INPUTS | ~ | Connector_PinHeader_2.54mm:PinHeader_1x10_P2.54mm_Vertical | 1
Q1,Q2,Q3,Q4 | BC548 | https://www.onsemi.com/pub/Collateral/BC550-D.pdf | Package_TO_SOT_THT:TO-92L_Inline_Wide | 4
R1,R2,R3,R4,R5,R6,R7,R8,R9,R10,R11,R12,R14,R15,R16,R17 | 2.2k | ~ | Resistor_THT:R_Axial_DIN0207_L6.3mm_D2.5mm_P7.62mm_Horizontal | 16
R13 | 1k | ~ | Resistor_THT:R_Axial_DIN0207_L6.3mm_D2.5mm_P7.62mm_Horizontal | 1

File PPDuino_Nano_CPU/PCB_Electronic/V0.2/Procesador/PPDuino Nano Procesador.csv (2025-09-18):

Reference | Value | Footprint | Qty | DNP
A1 | Arduino Nano | Module:Arduino_Nano | 1
C1 | 100uF | Capacitor_THT:CP_Radial_D5.0mm_P2.50mm | 1
C2 | 10uF | Capacitor_THT:CP_Radial_D5.0mm_P2.50mm | 1
J1 | PWR_IN | Borneras:TerminalBlock_Altech_AK300-2_P5.00mm | 1
J2 | Conn_01x12 | Connector_PinSocket_2.54mm:PinSocket_1x12_P2.54mm_Horizontal | 1
J11 | INPUTS | Connector_PinSocket_2.54mm:PinSocket_1x10_P2.54mm_Vertical | 1
J12 | OUTPUTS | Connector_PinHeader_2.54mm:PinHeader_1x10_P2.54mm_Vertical | 1
U1 | L7805 | Package_TO_SOT_THT:TO-220-3_Horizontal_TabDown | 1
U6 | +5V | Codigo_lib:Mini 560 Pro | 1

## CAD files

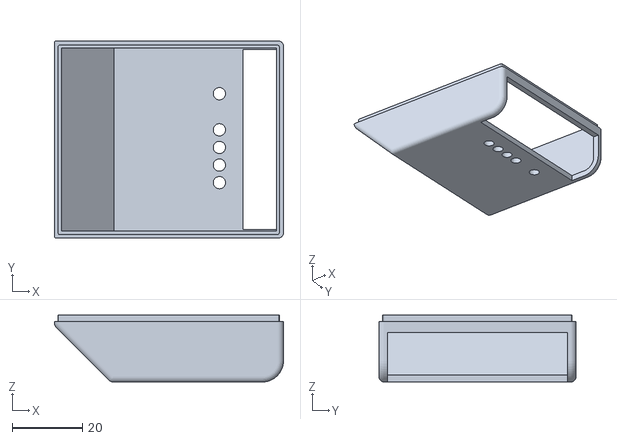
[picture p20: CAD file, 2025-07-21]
PPDuino_Nano_CPU/3D_Design/Fusion/Tapa1_Superior Final.stl
65.0 x 56.0 x 19.0

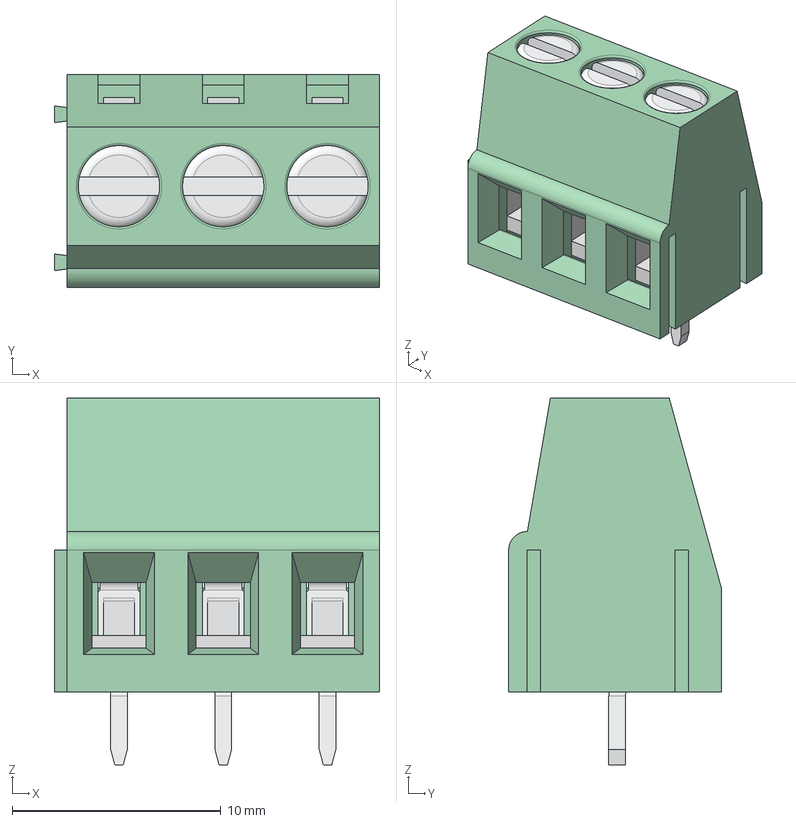
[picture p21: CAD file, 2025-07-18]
PPDuino_Nano_CPU/3D_Design/STP/DG128-5.0-03.stp
15.6 x 10.2 x 17.6 mm

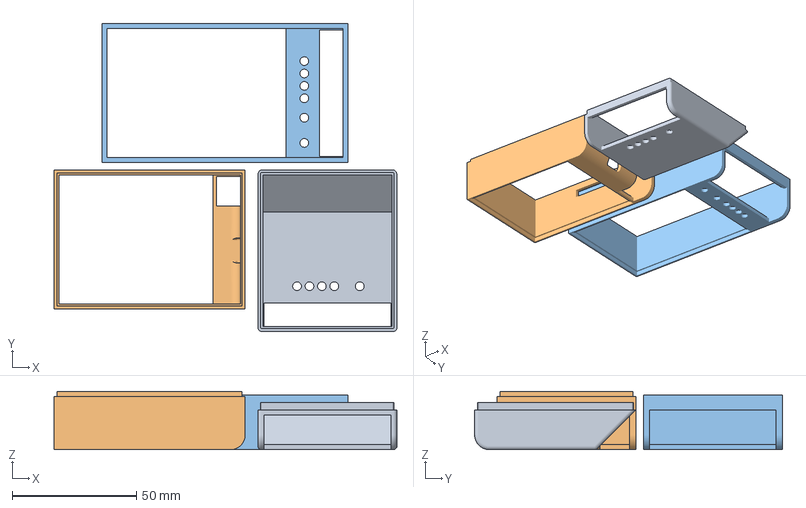
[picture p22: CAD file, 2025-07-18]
PPDuino_Nano_CPU/Manufacturing/CE3E3V2_Tapa1_Superior Final.3mf
138.1 x 124.0 x 23.5 mm
Tapa1_Superior Final.stl
Tapa2_Intermedia Final.stl
Tapa3_Inferior Final.stl

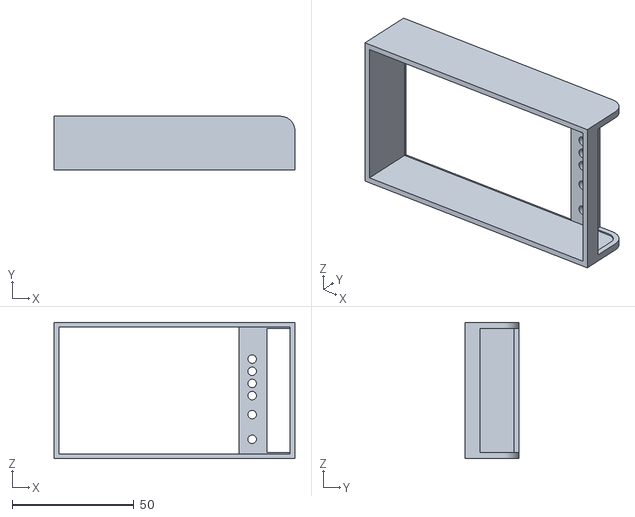
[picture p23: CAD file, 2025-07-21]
PPDuino_Nano_CPU/3D_Design/Fusion/Tapa3_Inferior Final.stl
99.0 x 22.0 x 56.0

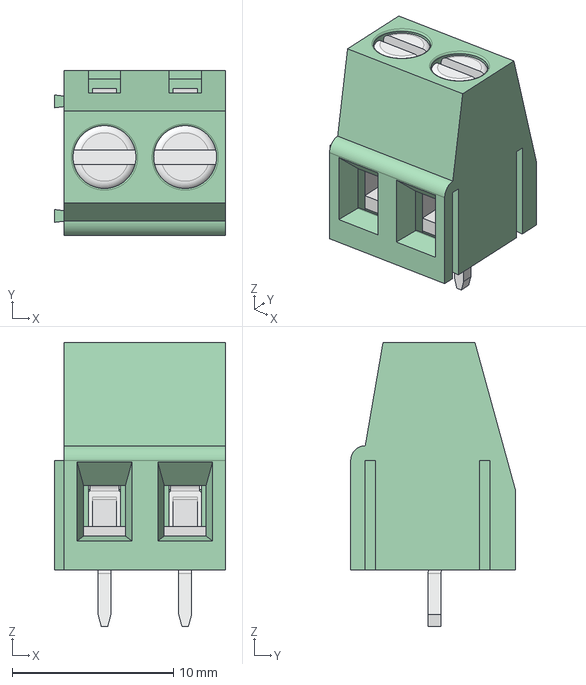
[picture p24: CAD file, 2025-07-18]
PPDuino_Nano_CPU/3D_Design/STP/Borneras DG128-5.0-02.stp
10.6 x 10.2 x 17.6 mm

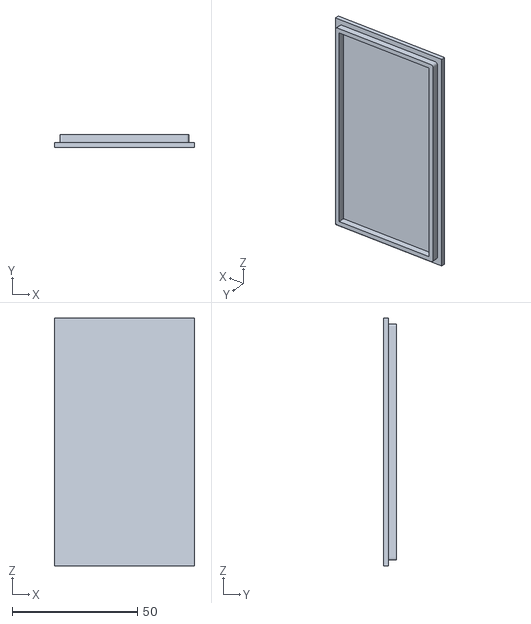
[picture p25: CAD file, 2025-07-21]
PPDuino_Nano_CPU/3D_Design/Fusion/Tapa4_Base Final.stl
56.0 x 5.00 x 99.0

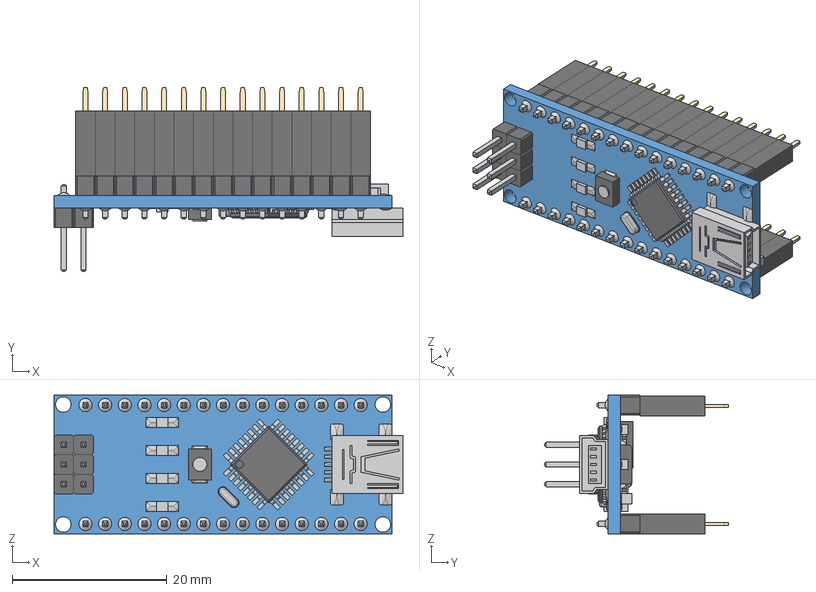
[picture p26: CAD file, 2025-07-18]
PPDuino_Nano_CPU/3D_Design/STP/Arduino NanoV3 + Female Headers.step
45.1 x 23.7 x 17.9 mm
switch
Led x 3
Led (1)
Pin x 21
chip1
USB
Crystal
Pin (1) x 15
Res x 5
cap x 2
Chip
respack x 2
diode
vreg
HF1 x 30

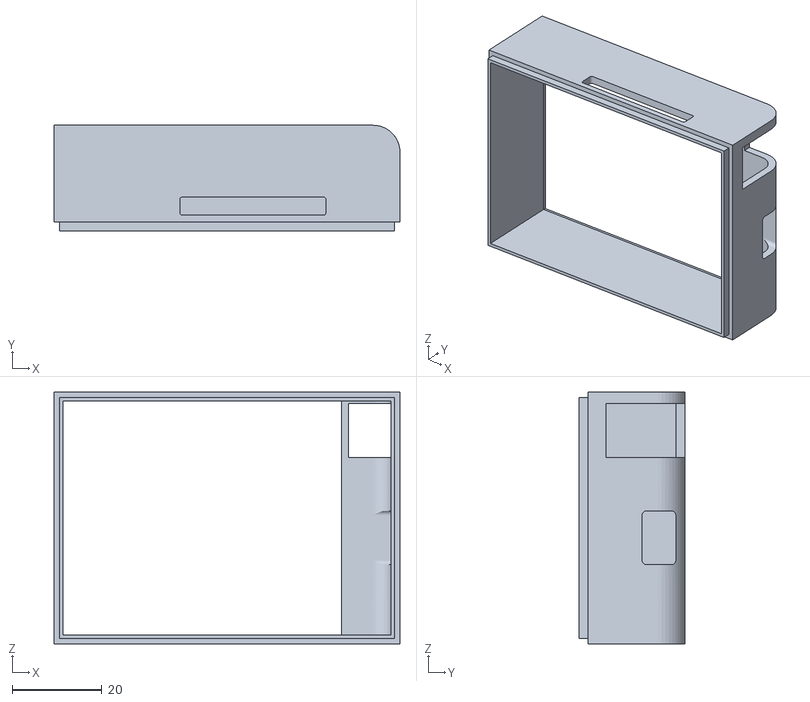
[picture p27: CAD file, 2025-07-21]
PPDuino_Nano_CPU/3D_Design/Fusion/Tapa2_Intermedia Final.stl
77.0 x 23.5 x 56.0

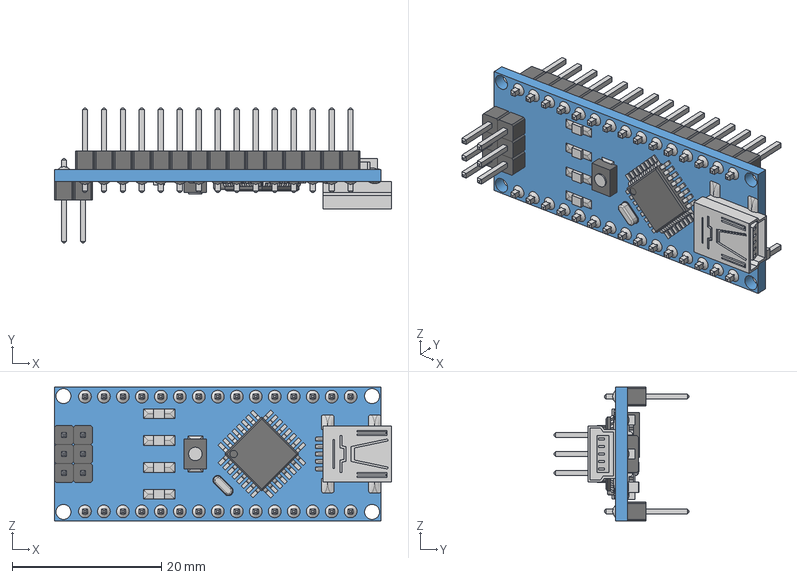
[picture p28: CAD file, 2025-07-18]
PPDuino_Nano_CPU/3D_Design/STP/Arduino Nano V3.step
45.1 x 18.0 x 17.9 mm
switch
Led x 3
Led (1)
Pin x 21
chip1
USB
Crystal
Pin (1) x 15
Res x 5
cap x 2
Chip
respack x 2
diode
vreg

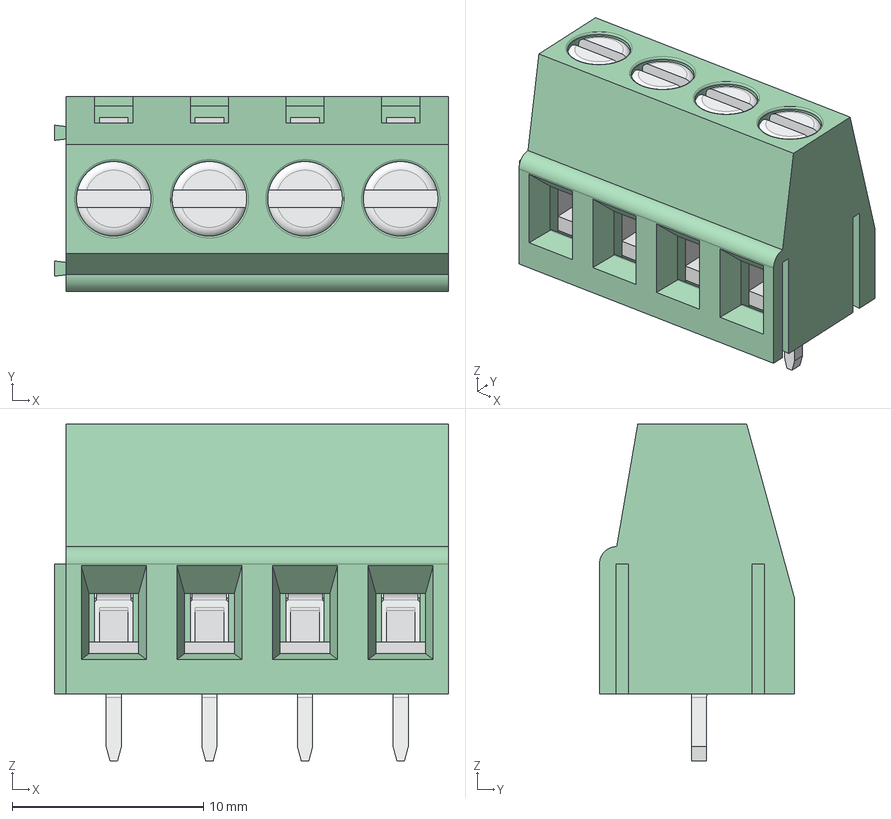
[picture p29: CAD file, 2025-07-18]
PPDuino_Nano_CPU/3D_Design/STP/DG128-5.0-04.stp
20.6 x 10.2 x 17.6 mm

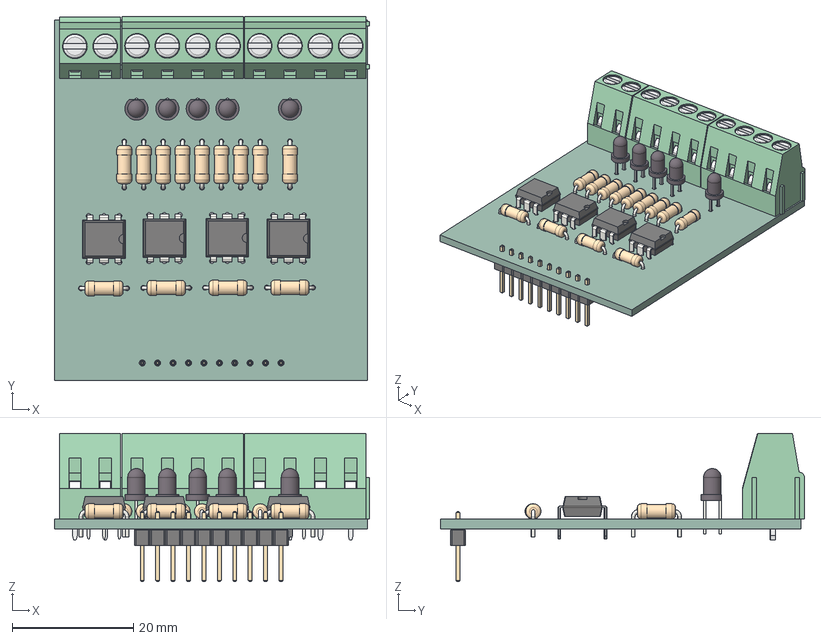
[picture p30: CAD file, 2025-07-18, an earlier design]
PPDuino_Nano_CPU/PCB_Electronic/V0.1/Entradas/PPDuino_Nano Entrada V3.step
51.9 x 60.0 x 24.4 mm
R_Axial_DIN0207_L63mm_D25mm_P762mm_Horizontal x 13
DIP-6_W7.62mm x 4
LED_D3.0mm_IRBlack x 5
DG128-5.0-02
DG128-5.0-04 x 2
PinHeader_1x10_P254mm_Vertical
PPDuino Nano Entradas_PCB

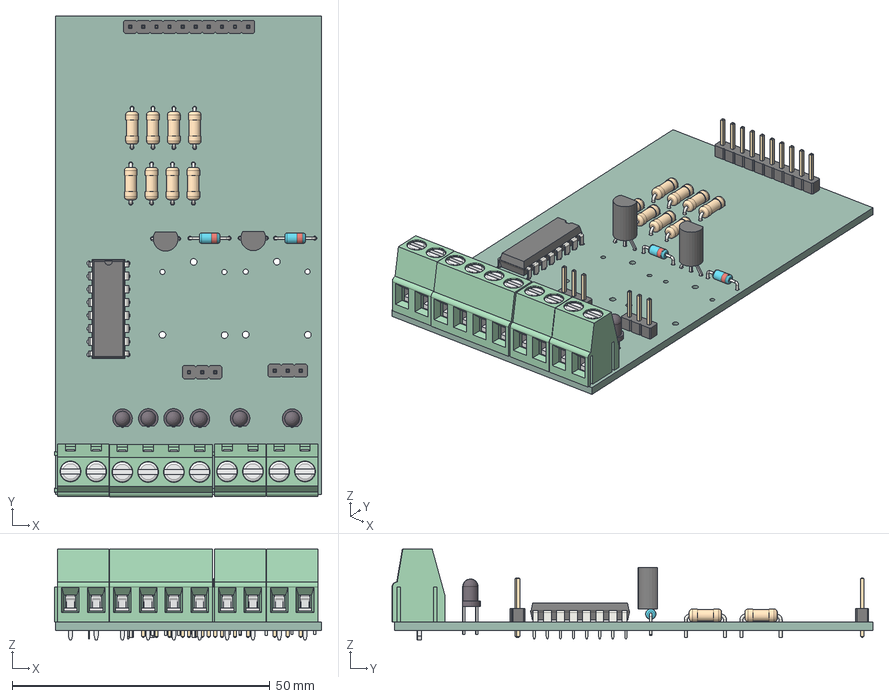
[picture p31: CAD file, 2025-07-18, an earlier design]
PPDuino_Nano_CPU/PCB_Electronic/V0.1/Salidas/PPDuino Nano Salidas V2.step
51.8 x 93.3 x 17.6 mm
R_Axial_DIN0207_L63mm_D25mm_P762mm_Horizontal x 8
D_DO-35_SOD27_P7.62mm_Horizontal x 2
DIP-16_W7.62mm
PinHeader_1x03_P254mm_Vertical x 2
DG128-5.0-04
PinHeader_1x10_P254mm_Vertical
TO-92L_Inline_Wide x 2
DG128-5.0-02 x 3
LED_D3.0mm_IRBlack x 6
PPDuino Nano Salidas_PCB

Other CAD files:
PPDuino_Nano_CPU/3D_Design/Fusion/Tapa1_Superior Final.f3d
PPDuino_Nano_CPU/3D_Design/Fusion/Tapa2_Intermedia Final.f3d
PPDuino_Nano_CPU/3D_Design/Fusion/Tapa3_Inferior Final.f3d
PPDuino_Nano_CPU/3D_Design/Fusion/Tapa4_Base Final.f3d

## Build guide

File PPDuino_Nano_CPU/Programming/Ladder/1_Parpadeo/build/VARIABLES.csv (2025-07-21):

// Programs
0 | CONFIG0.RES0.INSTANCE0 | BLINK
// Variables
0 | FB | CONFIG0.RES0.INSTANCE0 | CONFIG0.RES0.INSTANCE0 | BLINK
1 | OUT | CONFIG0.RES0.INSTANCE0.PINSALIDA | CONFIG0.RES0.INSTANCE0.PINSALIDA | BOOL
2 | IN | CONFIG0.RES0.INSTANCE0.PINPULSADOR | CONFIG0.RES0.INSTANCE0.PINPULSADOR | BOOL
3 | FB | CONFIG0.RES0.INSTANCE0.TON0 | CONFIG0.RES0.INSTANCE0.TON0 | TON
4 | VAR | CONFIG0.RES0.INSTANCE0.TON0.EN | CONFIG0.RES0.INSTANCE0.TON0.EN | BOOL
5 | VAR | CONFIG0.RES0.INSTANCE0.TON0.ENO | CONFIG0.RES0.INSTANCE0.TON0.ENO | BOOL
6 | VAR | CONFIG0.RES0.INSTANCE0.TON0.IN | CONFIG0.RES0.INSTANCE0.TON0.IN | BOOL
7 | VAR | CONFIG0.RES0.INSTANCE0.TON0.PT | CONFIG0.RES0.INSTANCE0.TON0.PT | TIME
8 | VAR | CONFIG0.RES0.INSTANCE0.TON0.Q | CONFIG0.RES0.INSTANCE0.TON0.Q | BOOL
9 | VAR | CONFIG0.RES0.INSTANCE0.TON0.ET | CONFIG0.RES0.INSTANCE0.TON0.ET | TIME
10 | VAR | CONFIG0.RES0.INSTANCE0.TON0.STATE | CONFIG0.RES0.INSTANCE0.TON0.STATE | SINT
11 | VAR | CONFIG0.RES0.INSTANCE0.TON0.PREV_IN | CONFIG0.RES0.INSTANCE0.TON0.PREV_IN | BOOL
12 | VAR | CONFIG0.RES0.INSTANCE0.TON0.CURRENT_TIME | CONFIG0.RES0.INSTANCE0.TON0.CURRENT_TIME | TIME
13 | VAR | CONFIG0.RES0.INSTANCE0.TON0.START_TIME | CONFIG0.RES0.INSTANCE0.TON0.START_TIME | TIME
14 | FB | CONFIG0.RES0.INSTANCE0.TOF0 | CONFIG0.RES0.INSTANCE0.TOF0 | TOF
15 | VAR | CONFIG0.RES0.INSTANCE0.TOF0.EN | CONFIG0.RES0.INSTANCE0.TOF0.EN | BOOL
16 | VAR | CONFIG0.RES0.INSTANCE0.TOF0.ENO | CONFIG0.RES0.INSTANCE0.TOF0.ENO | BOOL
17 | VAR | CONFIG0.RES0.INSTANCE0.TOF0.IN | CONFIG0.RES0.INSTANCE0.TOF0.IN | BOOL
18 | VAR | CONFIG0.RES0.INSTANCE0.TOF0.PT | CONFIG0.RES0.INSTANCE0.TOF0.PT | TIME
19 | VAR | CONFIG0.RES0.INSTANCE0.TOF0.Q | CONFIG0.RES0.INSTANCE0.TOF0.Q | BOOL
20 | VAR | CONFIG0.RES0.INSTANCE0.TOF0.ET | CONFIG0.RES0.INSTANCE0.TOF0.ET | TIME
21 | VAR | CONFIG0.RES0.INSTANCE0.TOF0.STATE | CONFIG0.RES0.INSTANCE0.TOF0.STATE | SINT
22 | VAR | CONFIG0.RES0.INSTANCE0.TOF0.PREV_IN | CONFIG0.RES0.INSTANCE0.TOF0.PREV_IN | BOOL
23 | VAR | CONFIG0.RES0.INSTANCE0.TOF0.CURRENT_TIME | CONFIG0.RES0.INSTANCE0.TOF0.CURRENT_TIME | TIME
24 | VAR | CONFIG0.RES0.INSTANCE0.TOF0.START_TIME | CONFIG0.RES0.INSTANCE0.TOF0.START_TIME | TIME
// Ticktime
20000000

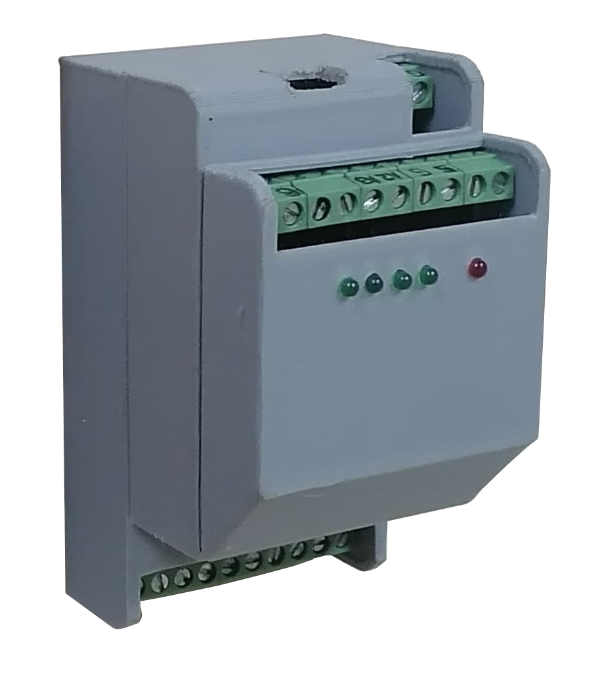
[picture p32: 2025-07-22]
PPDuino_Modulo_Wifi/Manufacturing/4.png

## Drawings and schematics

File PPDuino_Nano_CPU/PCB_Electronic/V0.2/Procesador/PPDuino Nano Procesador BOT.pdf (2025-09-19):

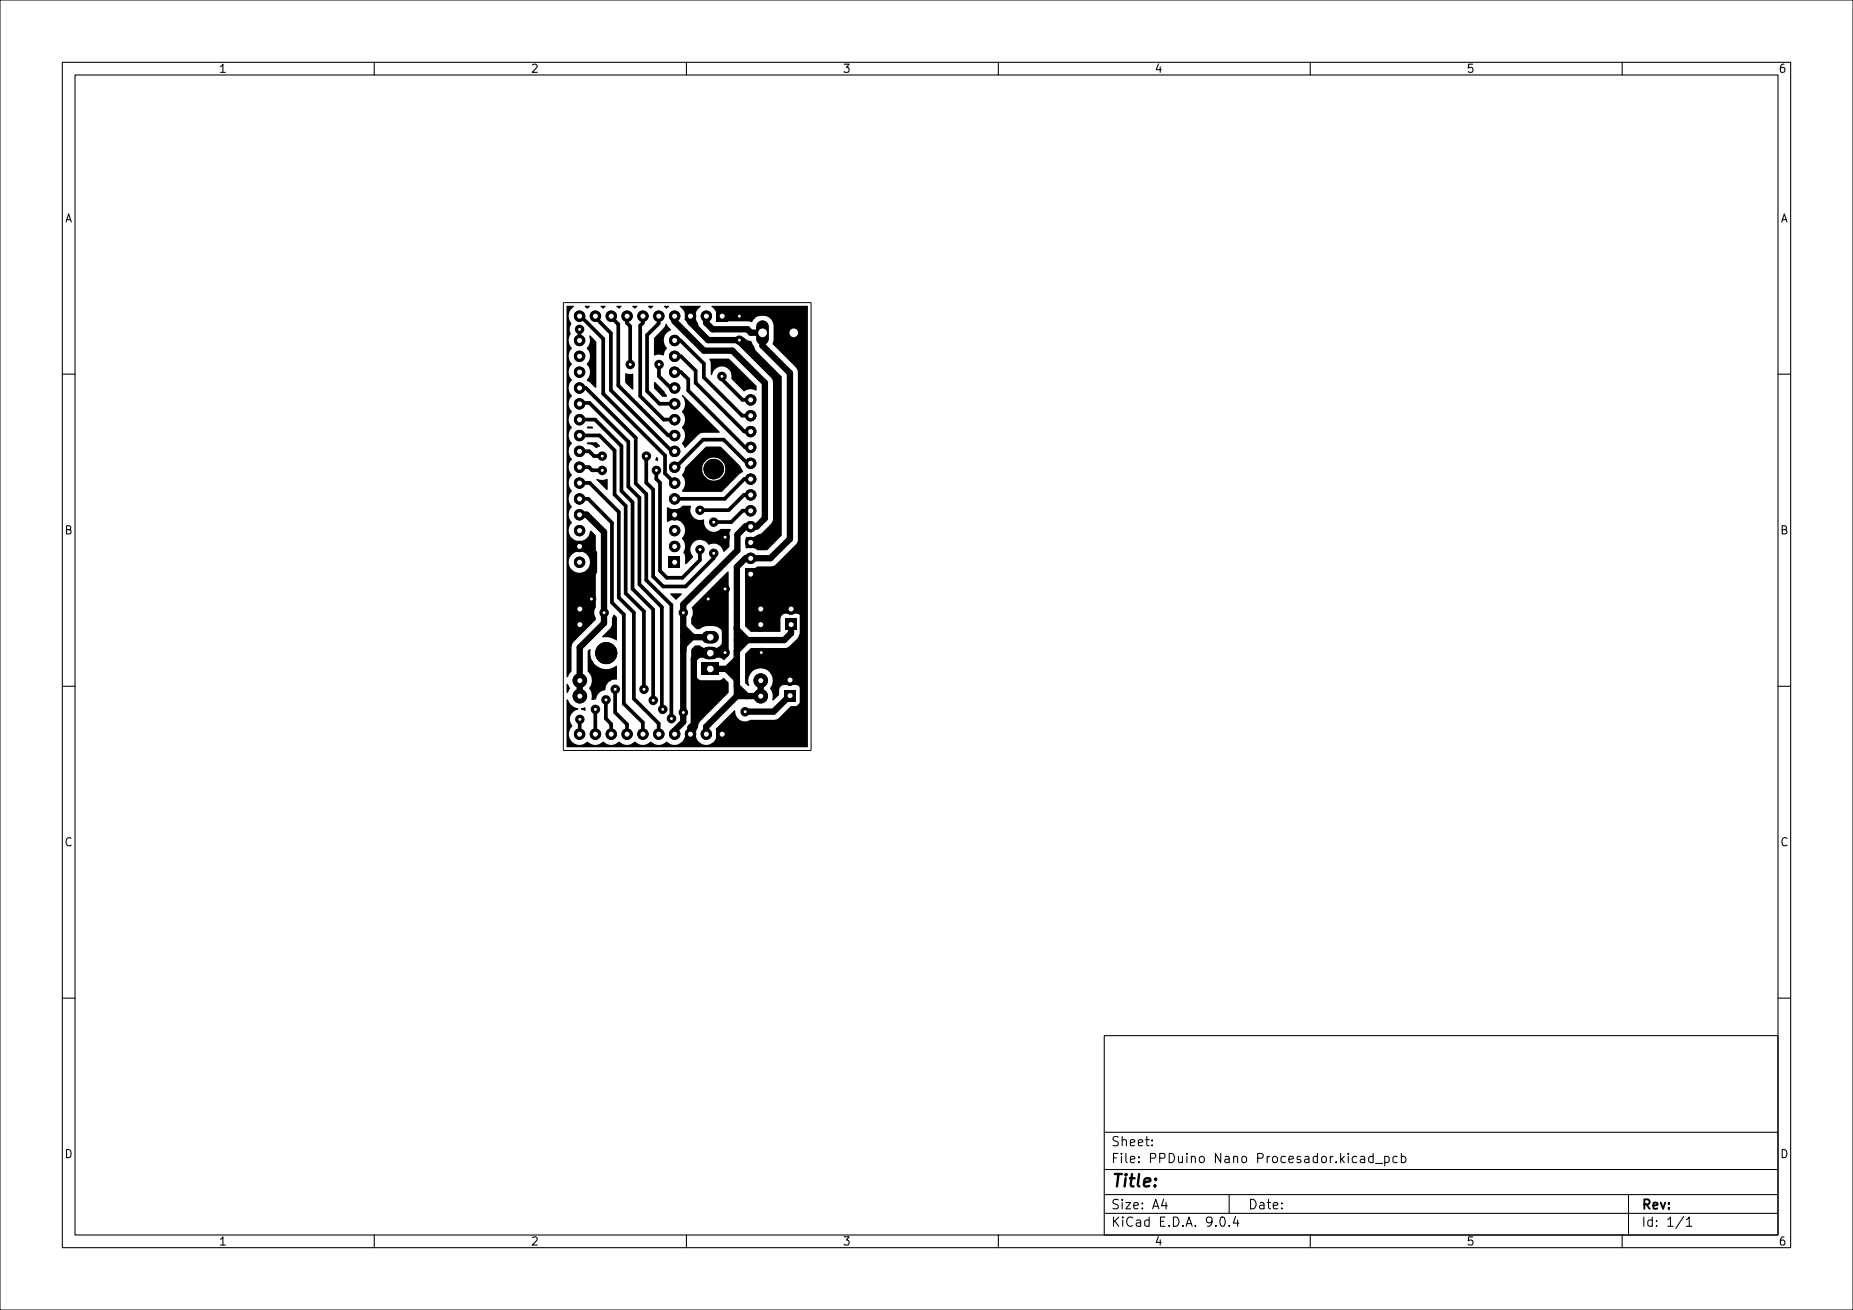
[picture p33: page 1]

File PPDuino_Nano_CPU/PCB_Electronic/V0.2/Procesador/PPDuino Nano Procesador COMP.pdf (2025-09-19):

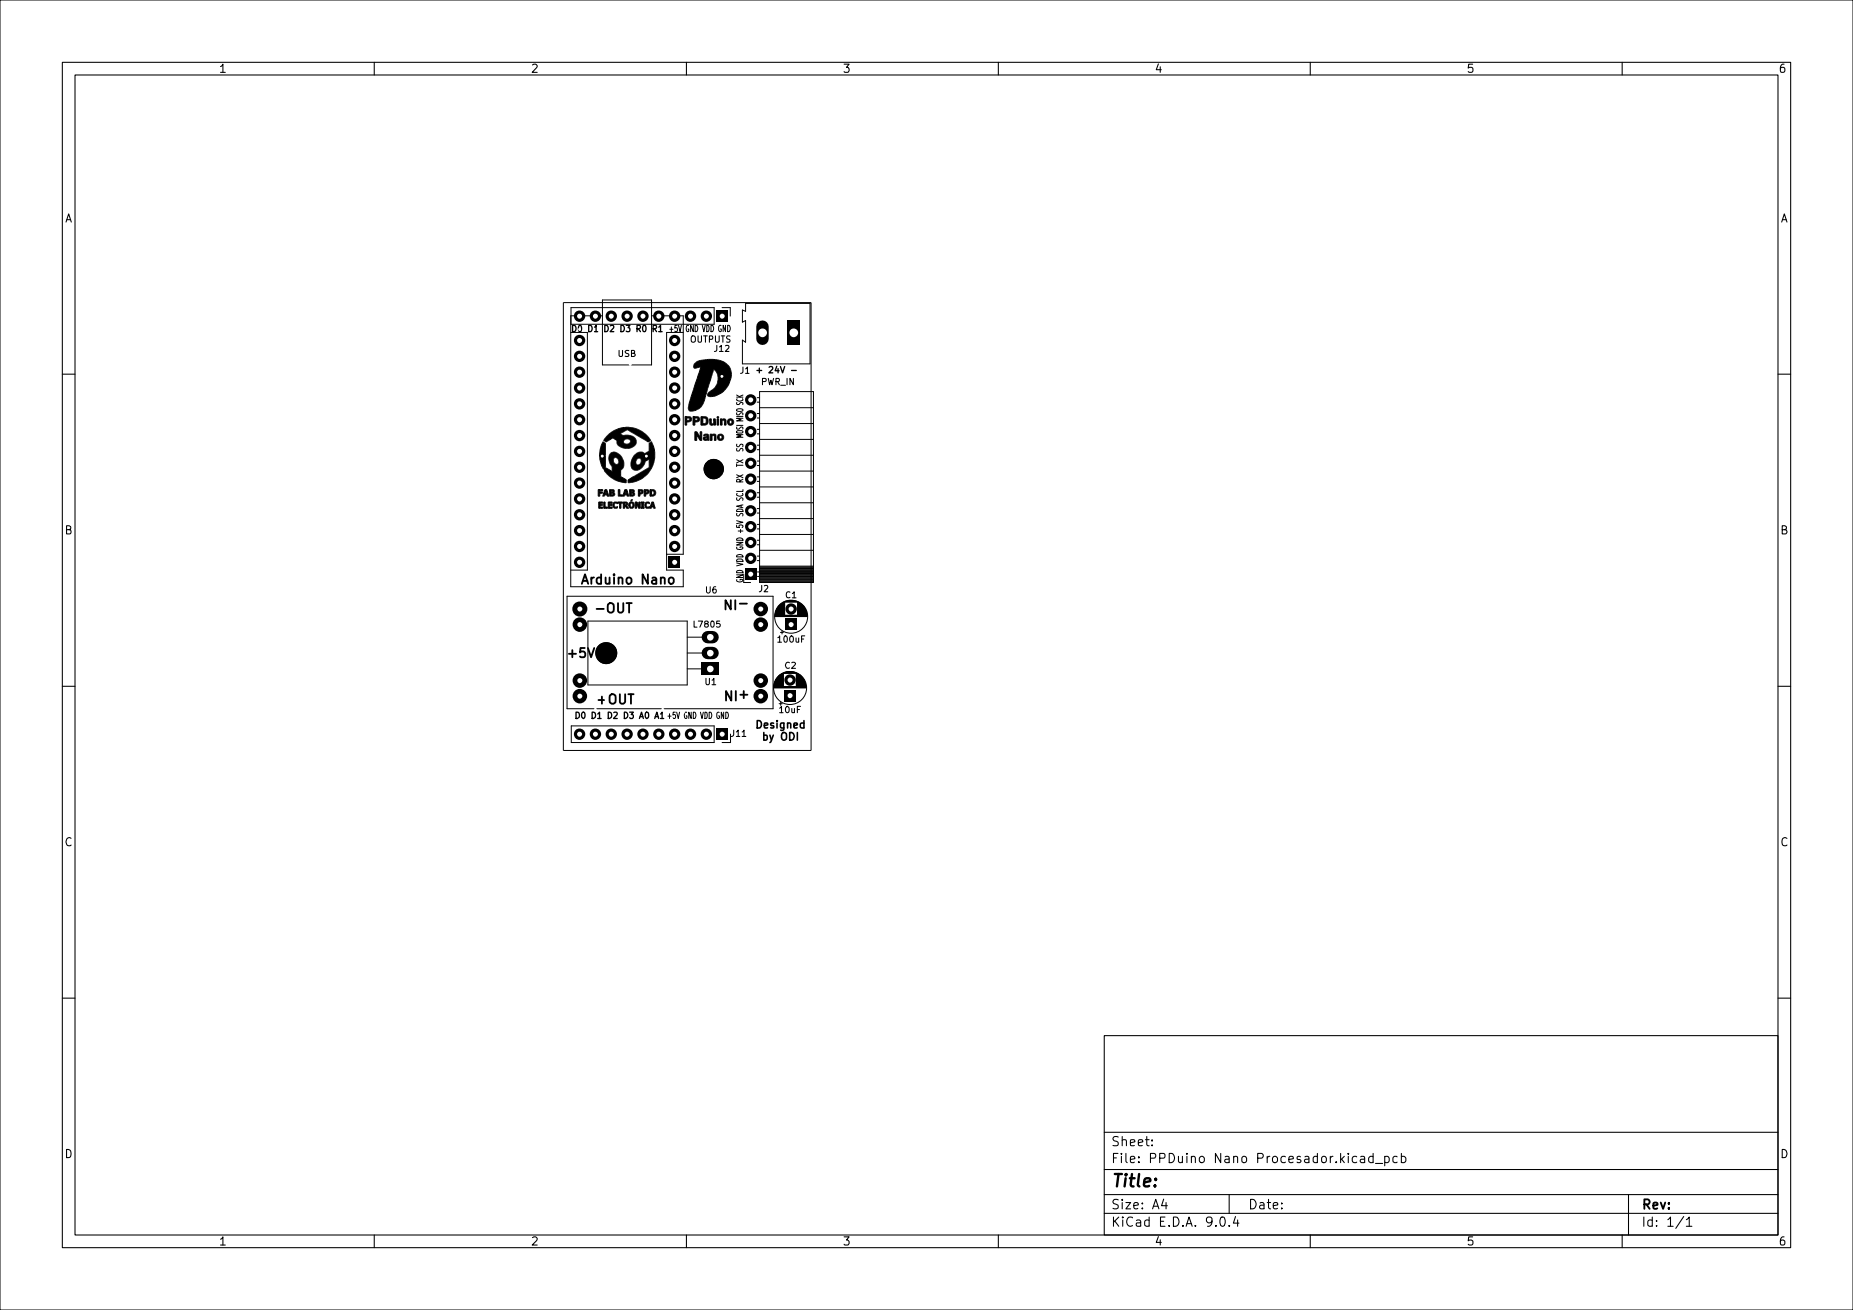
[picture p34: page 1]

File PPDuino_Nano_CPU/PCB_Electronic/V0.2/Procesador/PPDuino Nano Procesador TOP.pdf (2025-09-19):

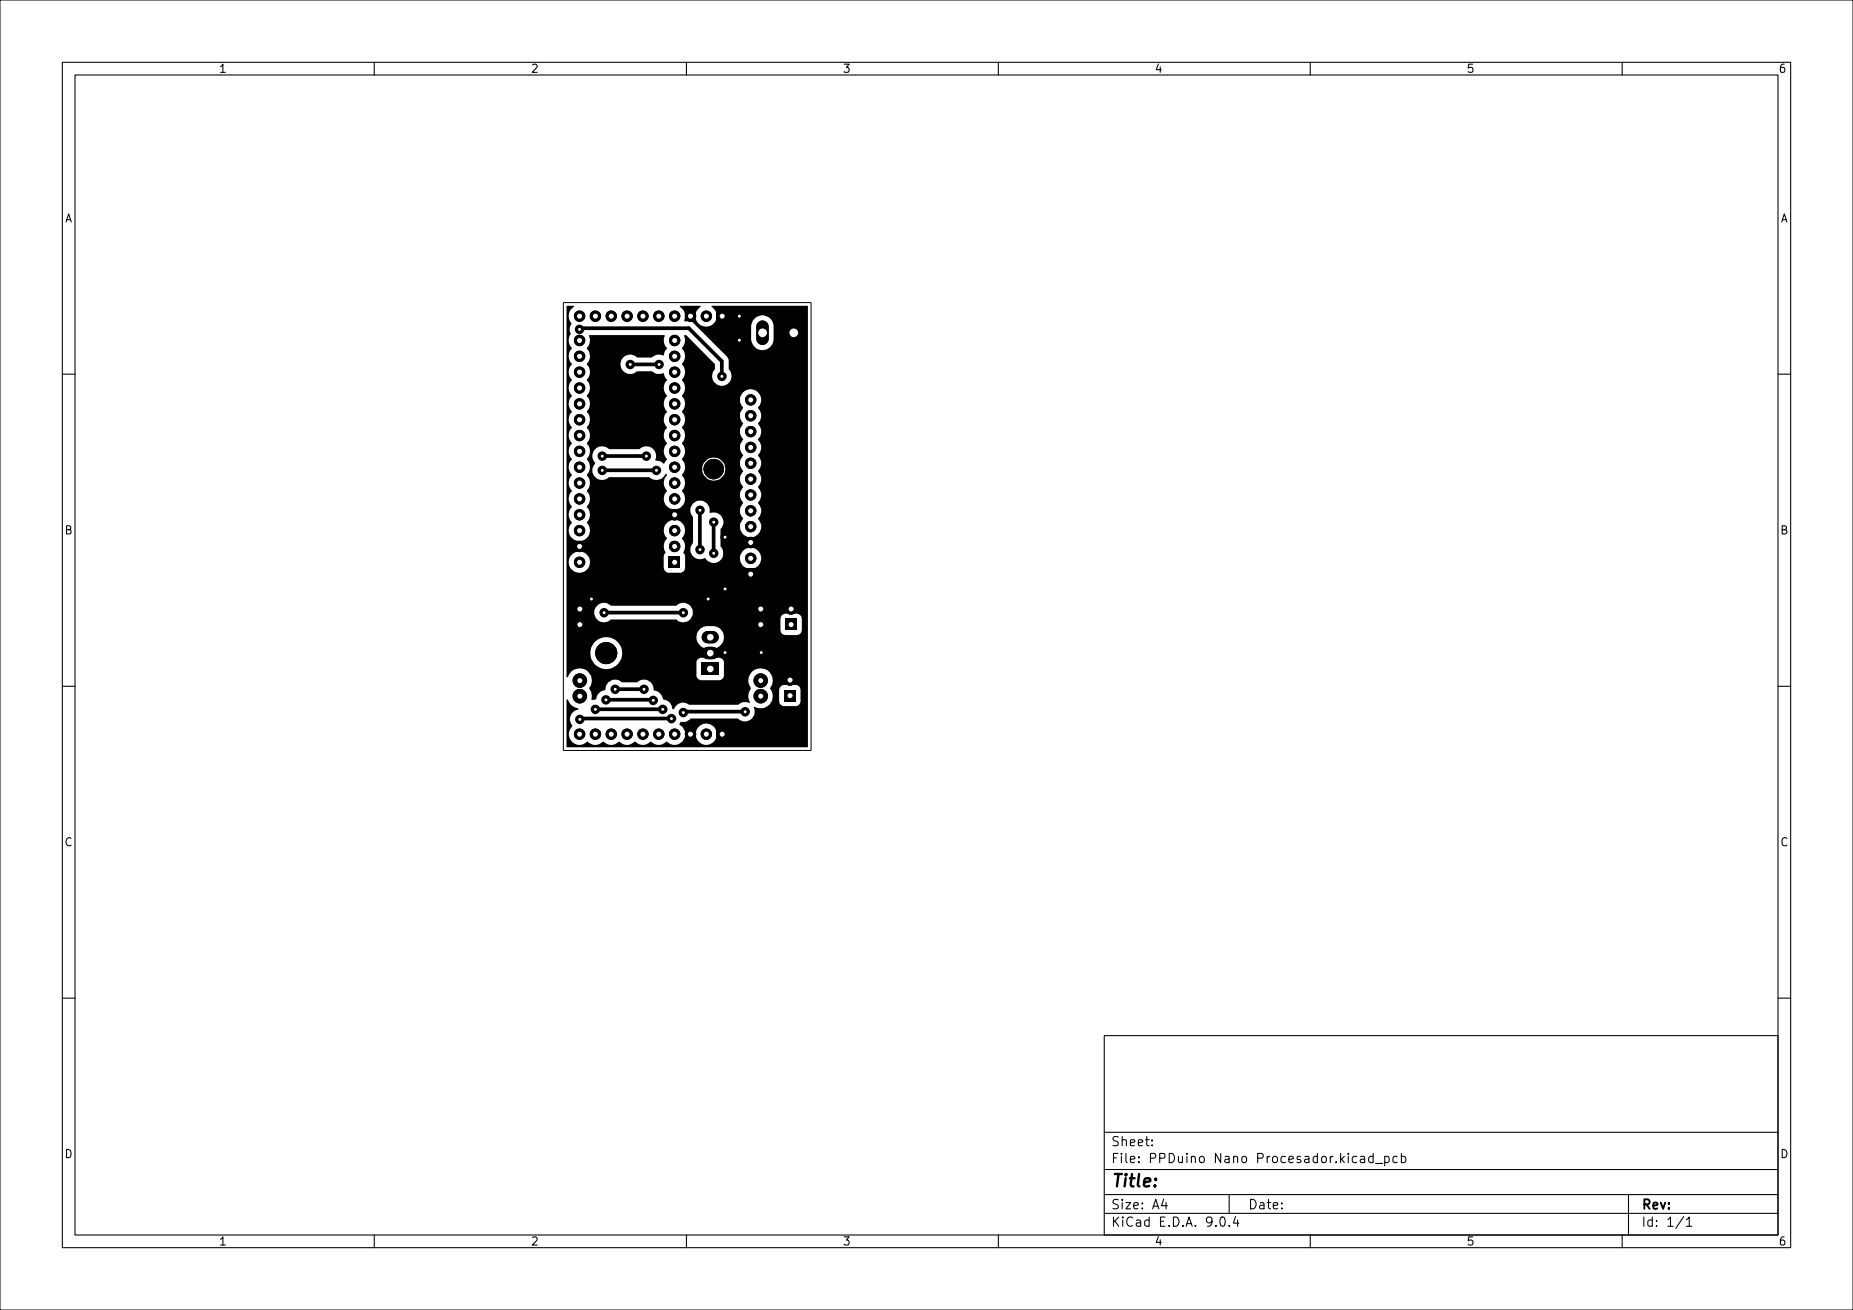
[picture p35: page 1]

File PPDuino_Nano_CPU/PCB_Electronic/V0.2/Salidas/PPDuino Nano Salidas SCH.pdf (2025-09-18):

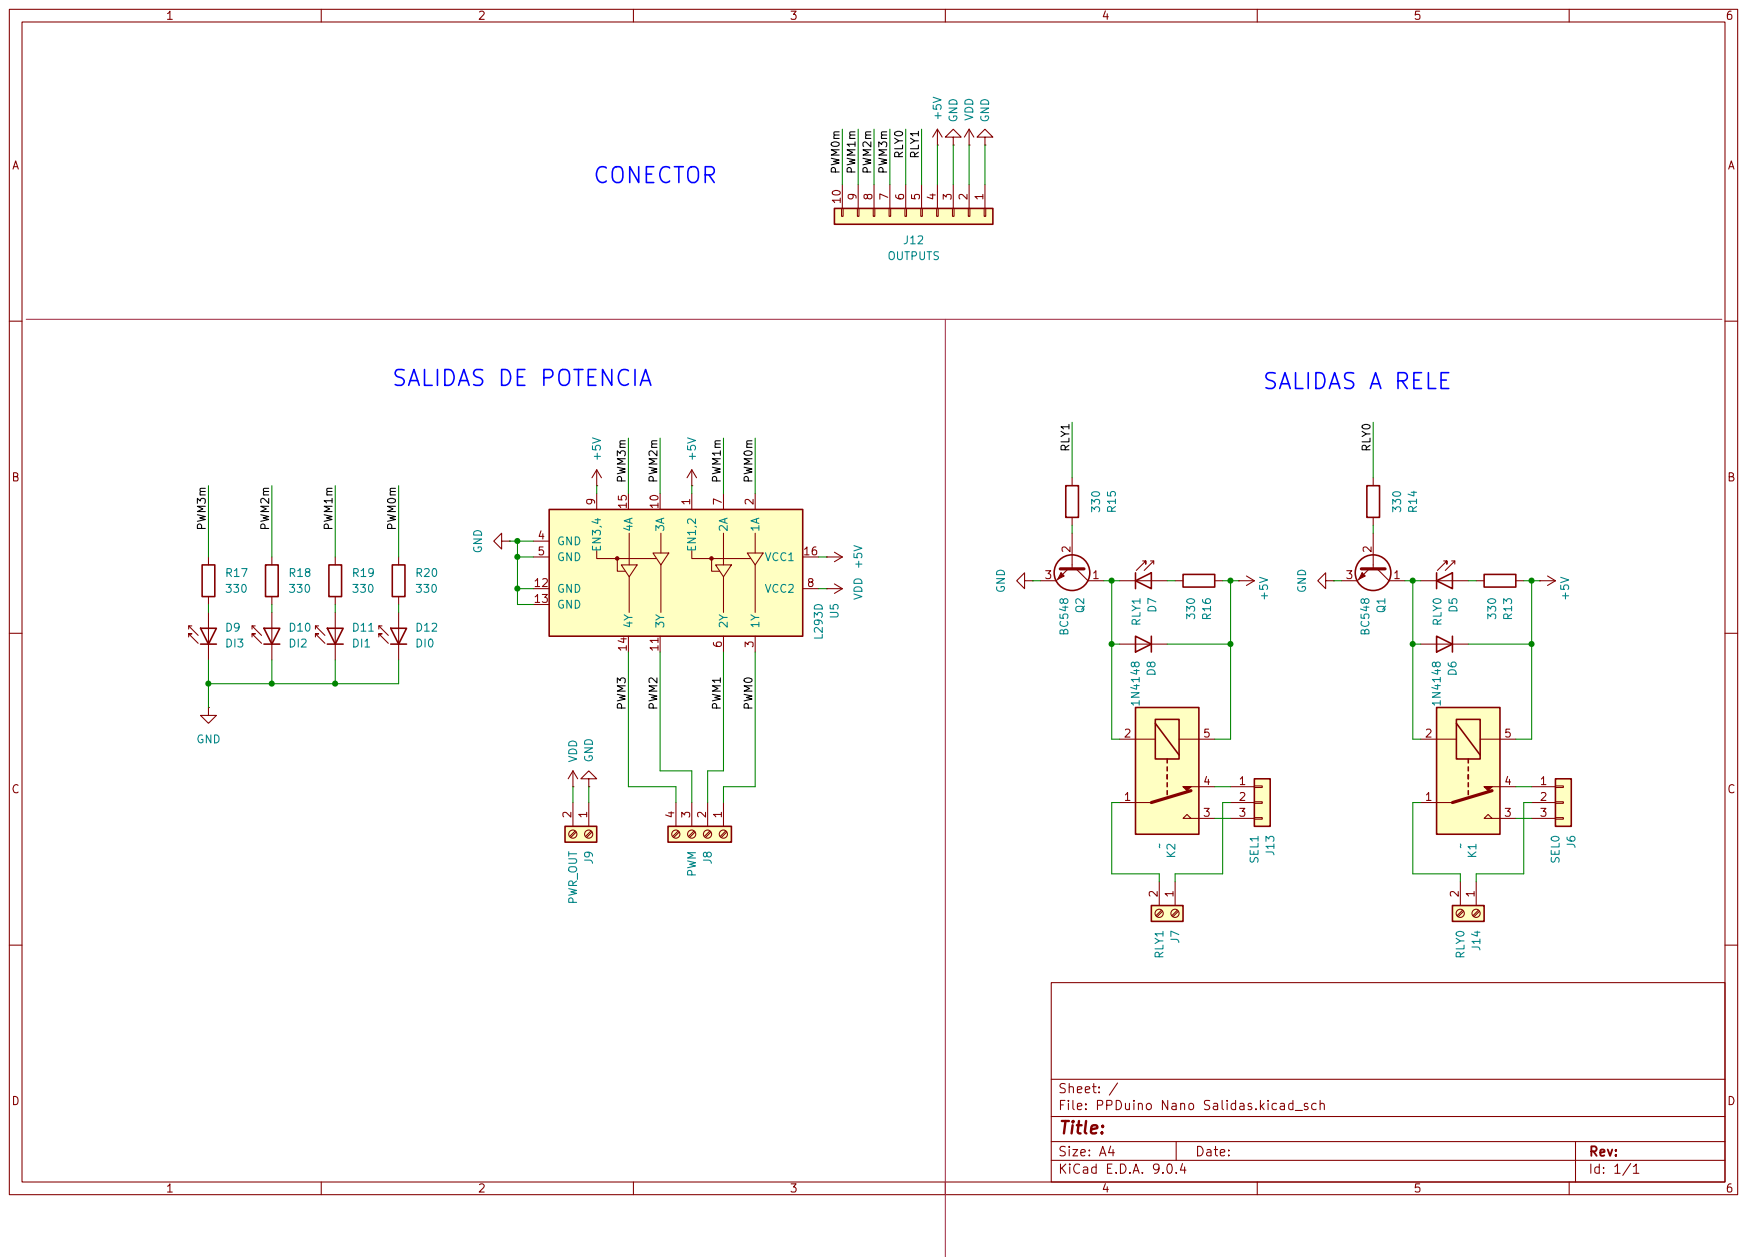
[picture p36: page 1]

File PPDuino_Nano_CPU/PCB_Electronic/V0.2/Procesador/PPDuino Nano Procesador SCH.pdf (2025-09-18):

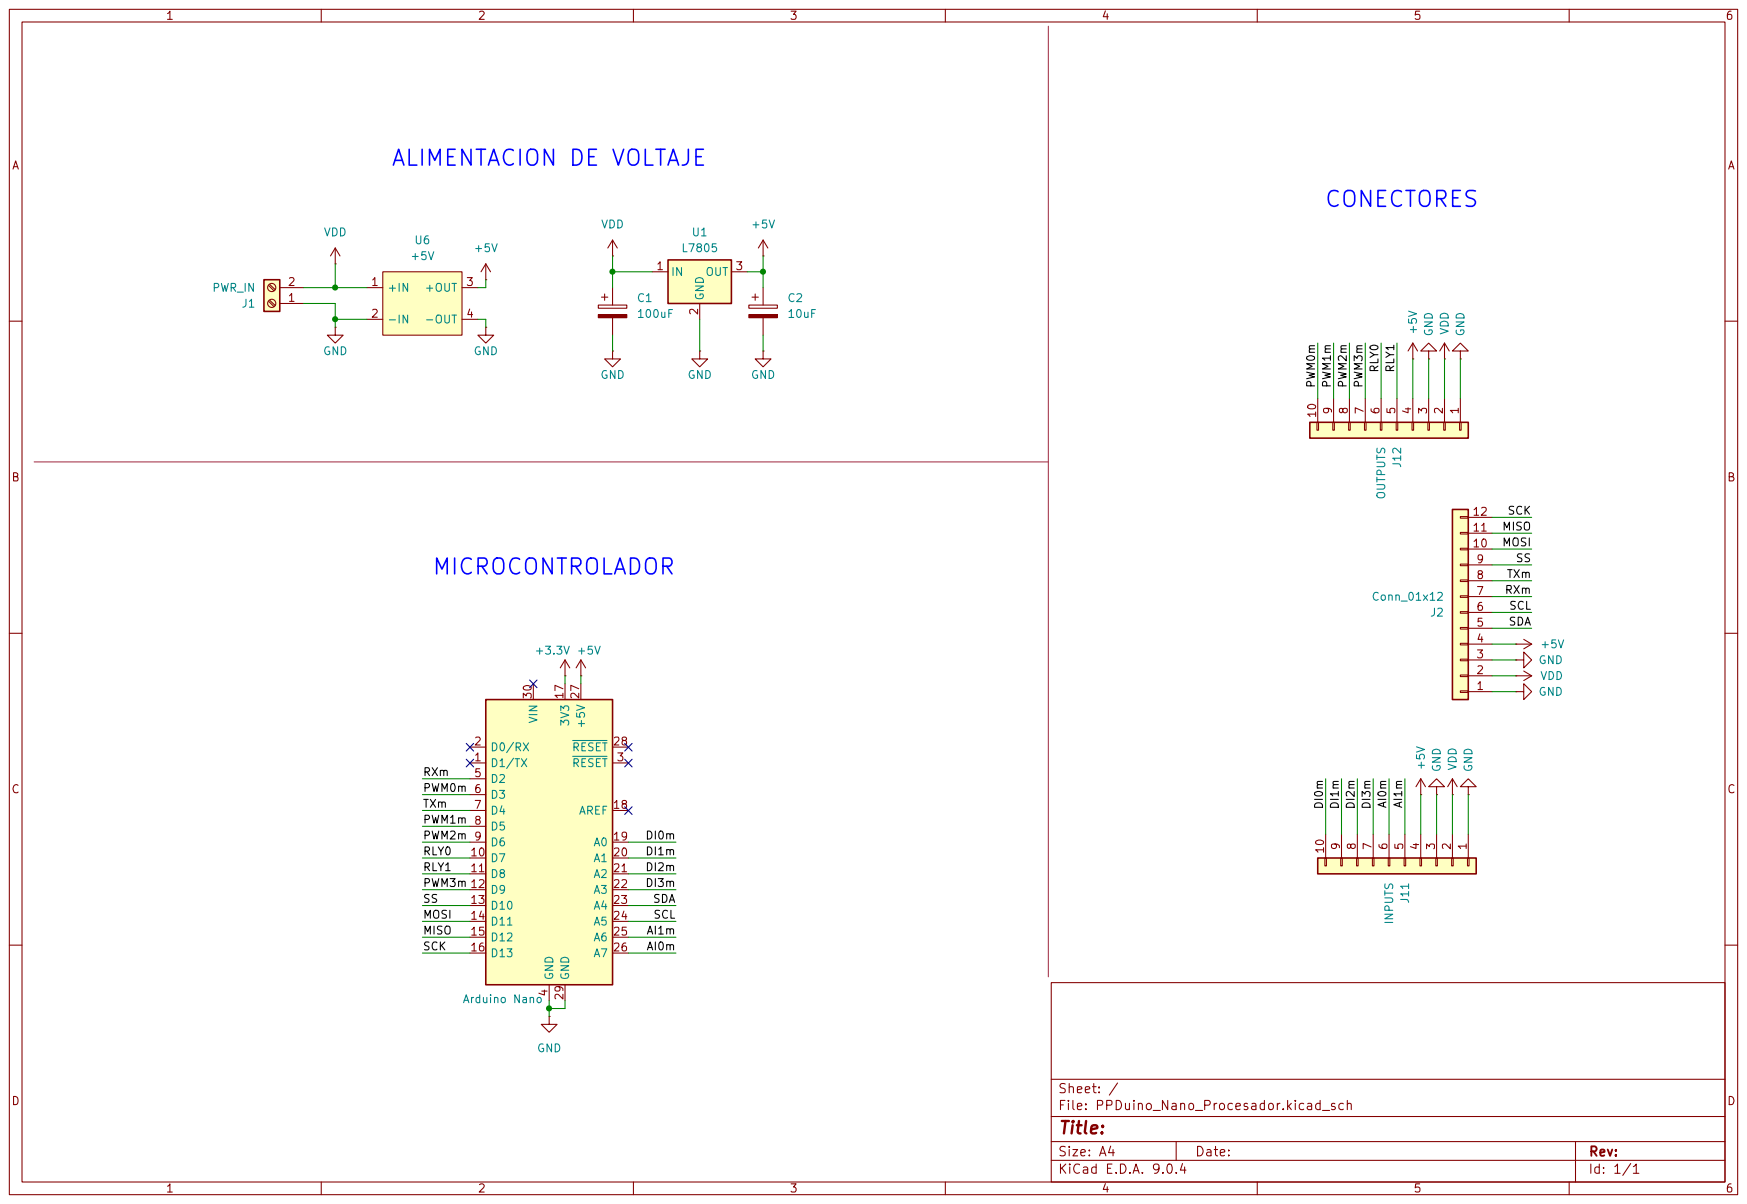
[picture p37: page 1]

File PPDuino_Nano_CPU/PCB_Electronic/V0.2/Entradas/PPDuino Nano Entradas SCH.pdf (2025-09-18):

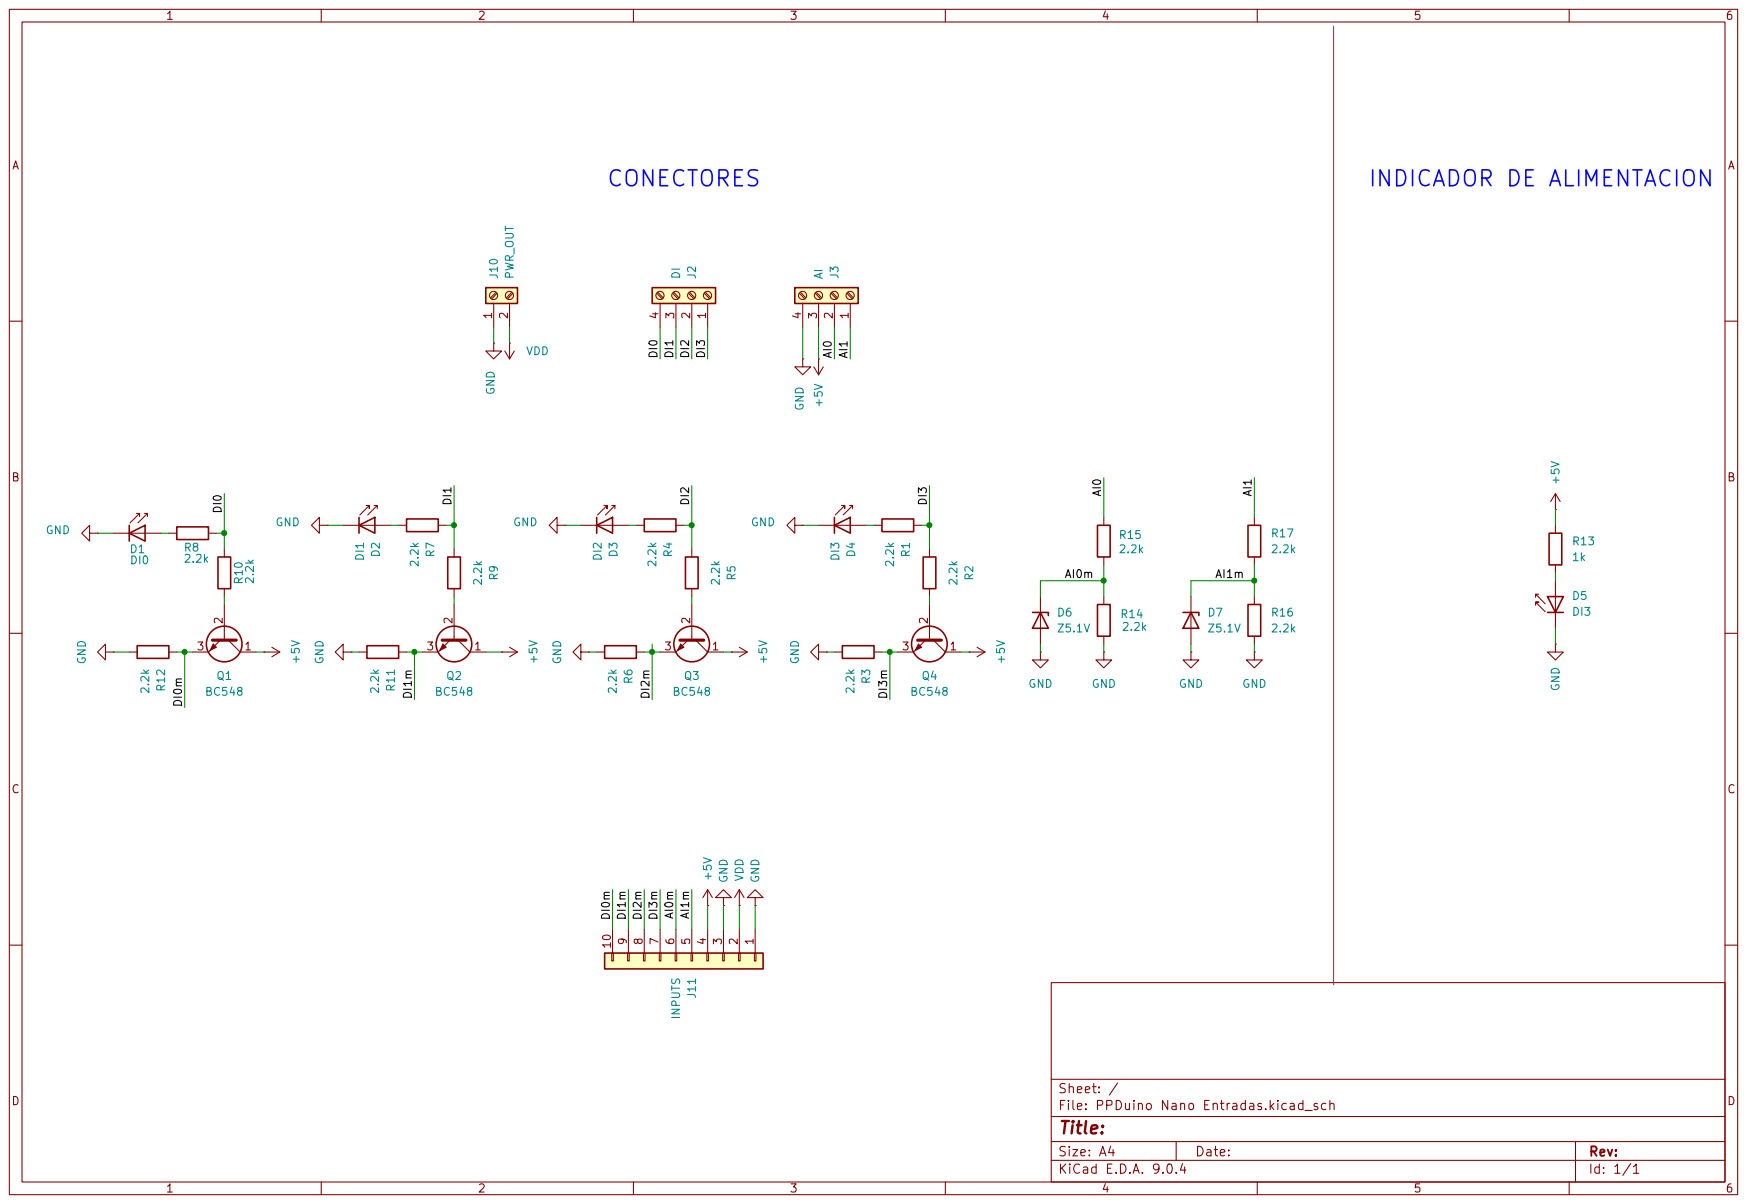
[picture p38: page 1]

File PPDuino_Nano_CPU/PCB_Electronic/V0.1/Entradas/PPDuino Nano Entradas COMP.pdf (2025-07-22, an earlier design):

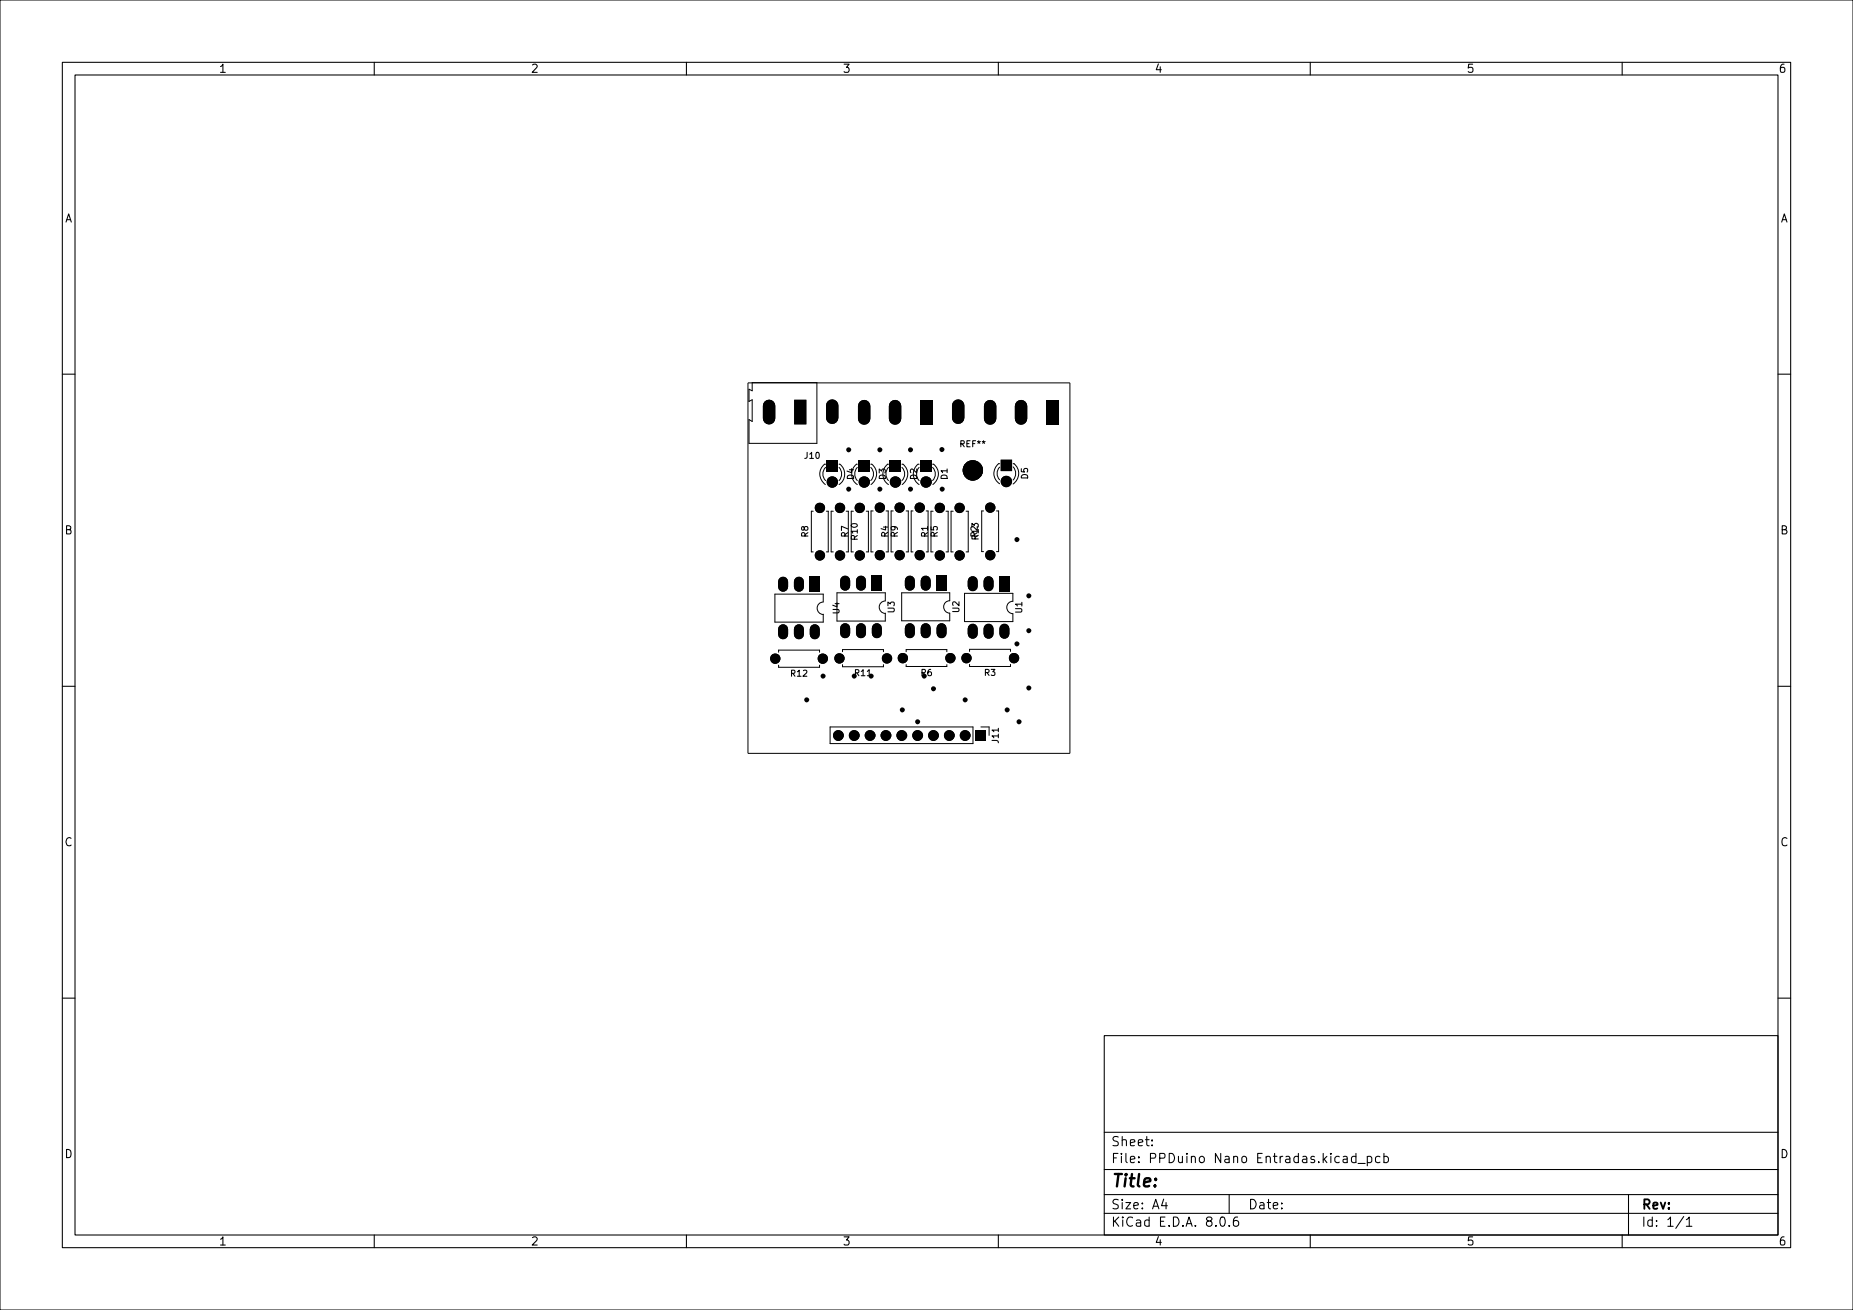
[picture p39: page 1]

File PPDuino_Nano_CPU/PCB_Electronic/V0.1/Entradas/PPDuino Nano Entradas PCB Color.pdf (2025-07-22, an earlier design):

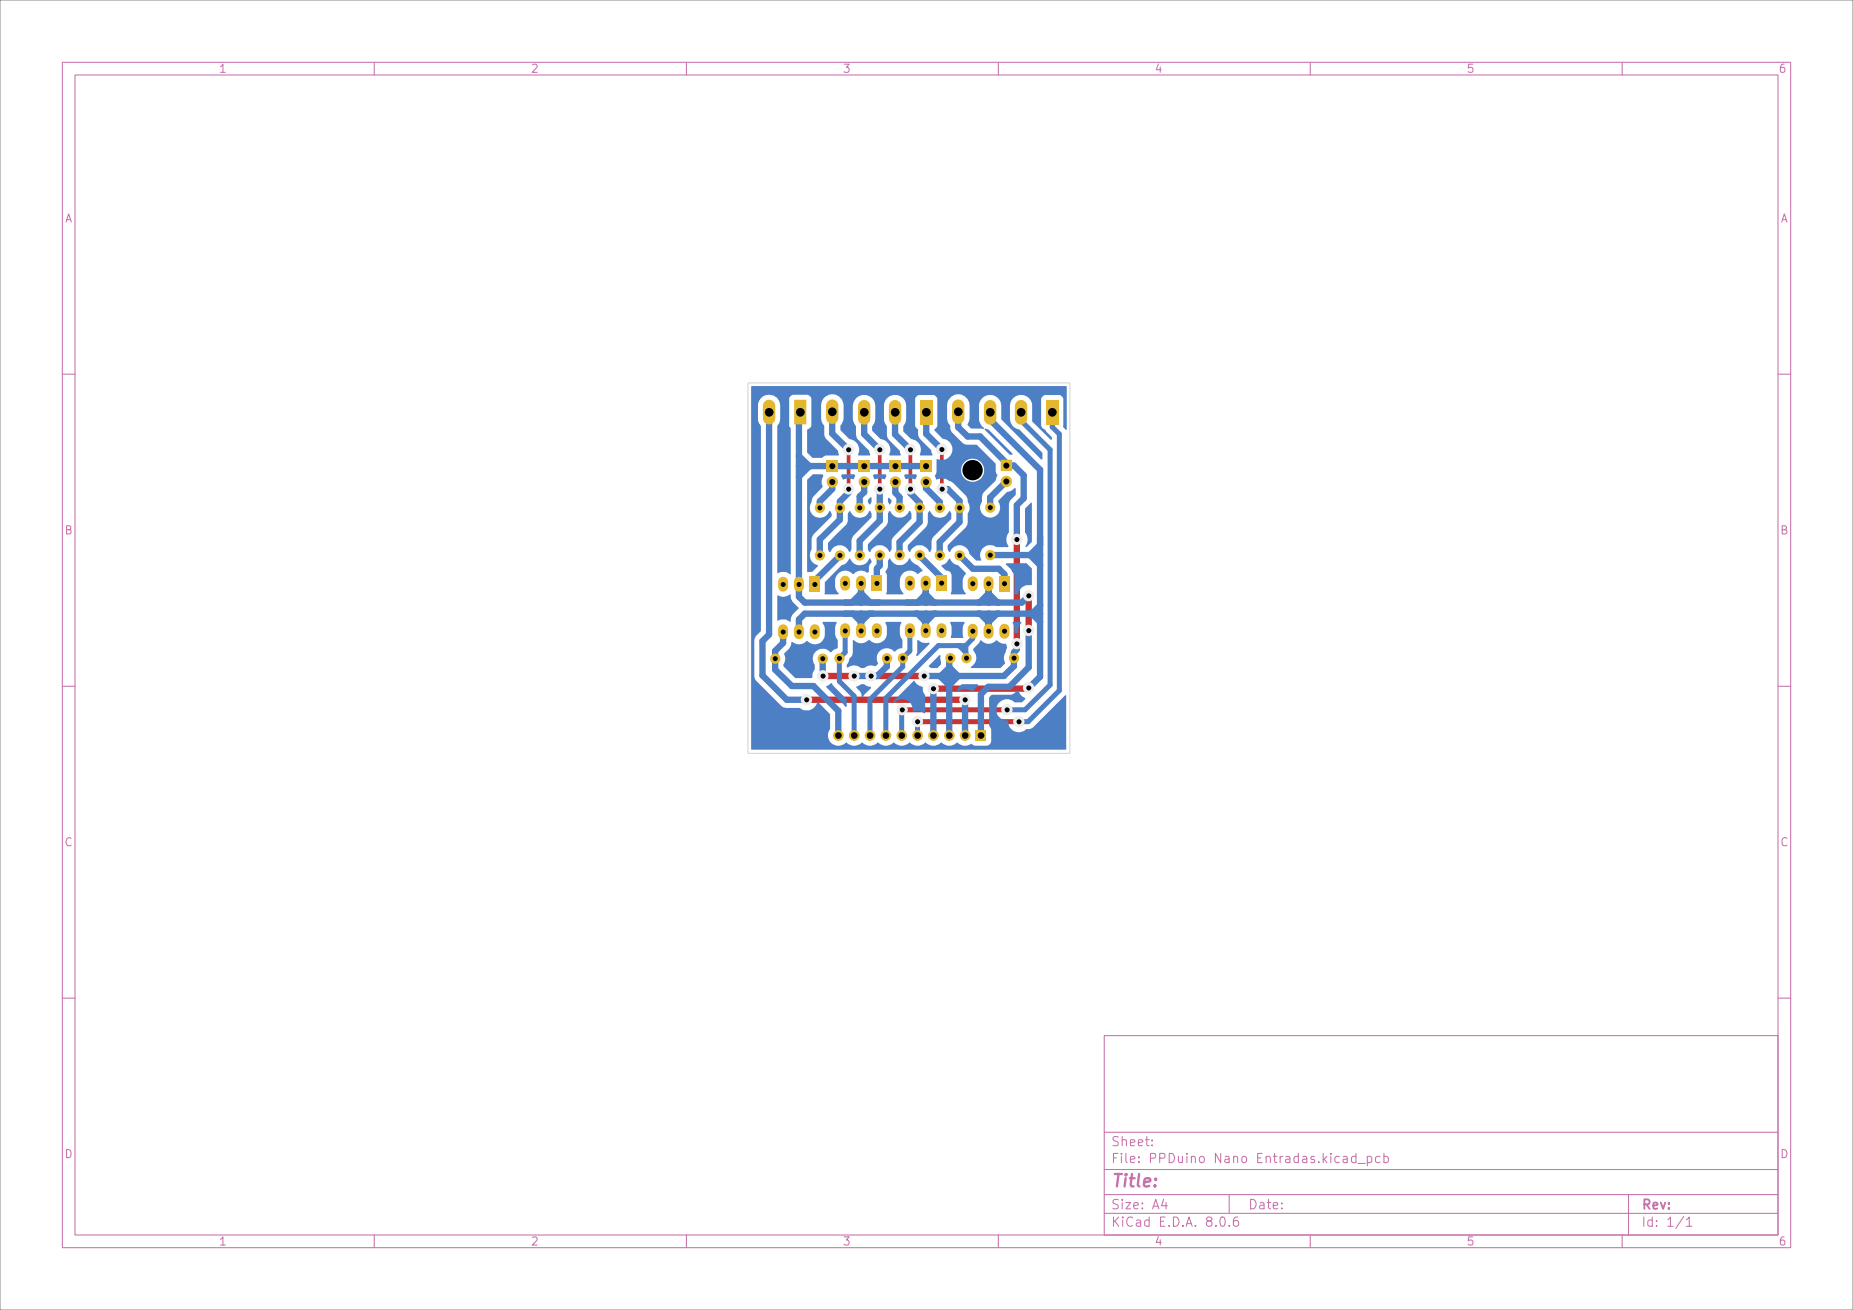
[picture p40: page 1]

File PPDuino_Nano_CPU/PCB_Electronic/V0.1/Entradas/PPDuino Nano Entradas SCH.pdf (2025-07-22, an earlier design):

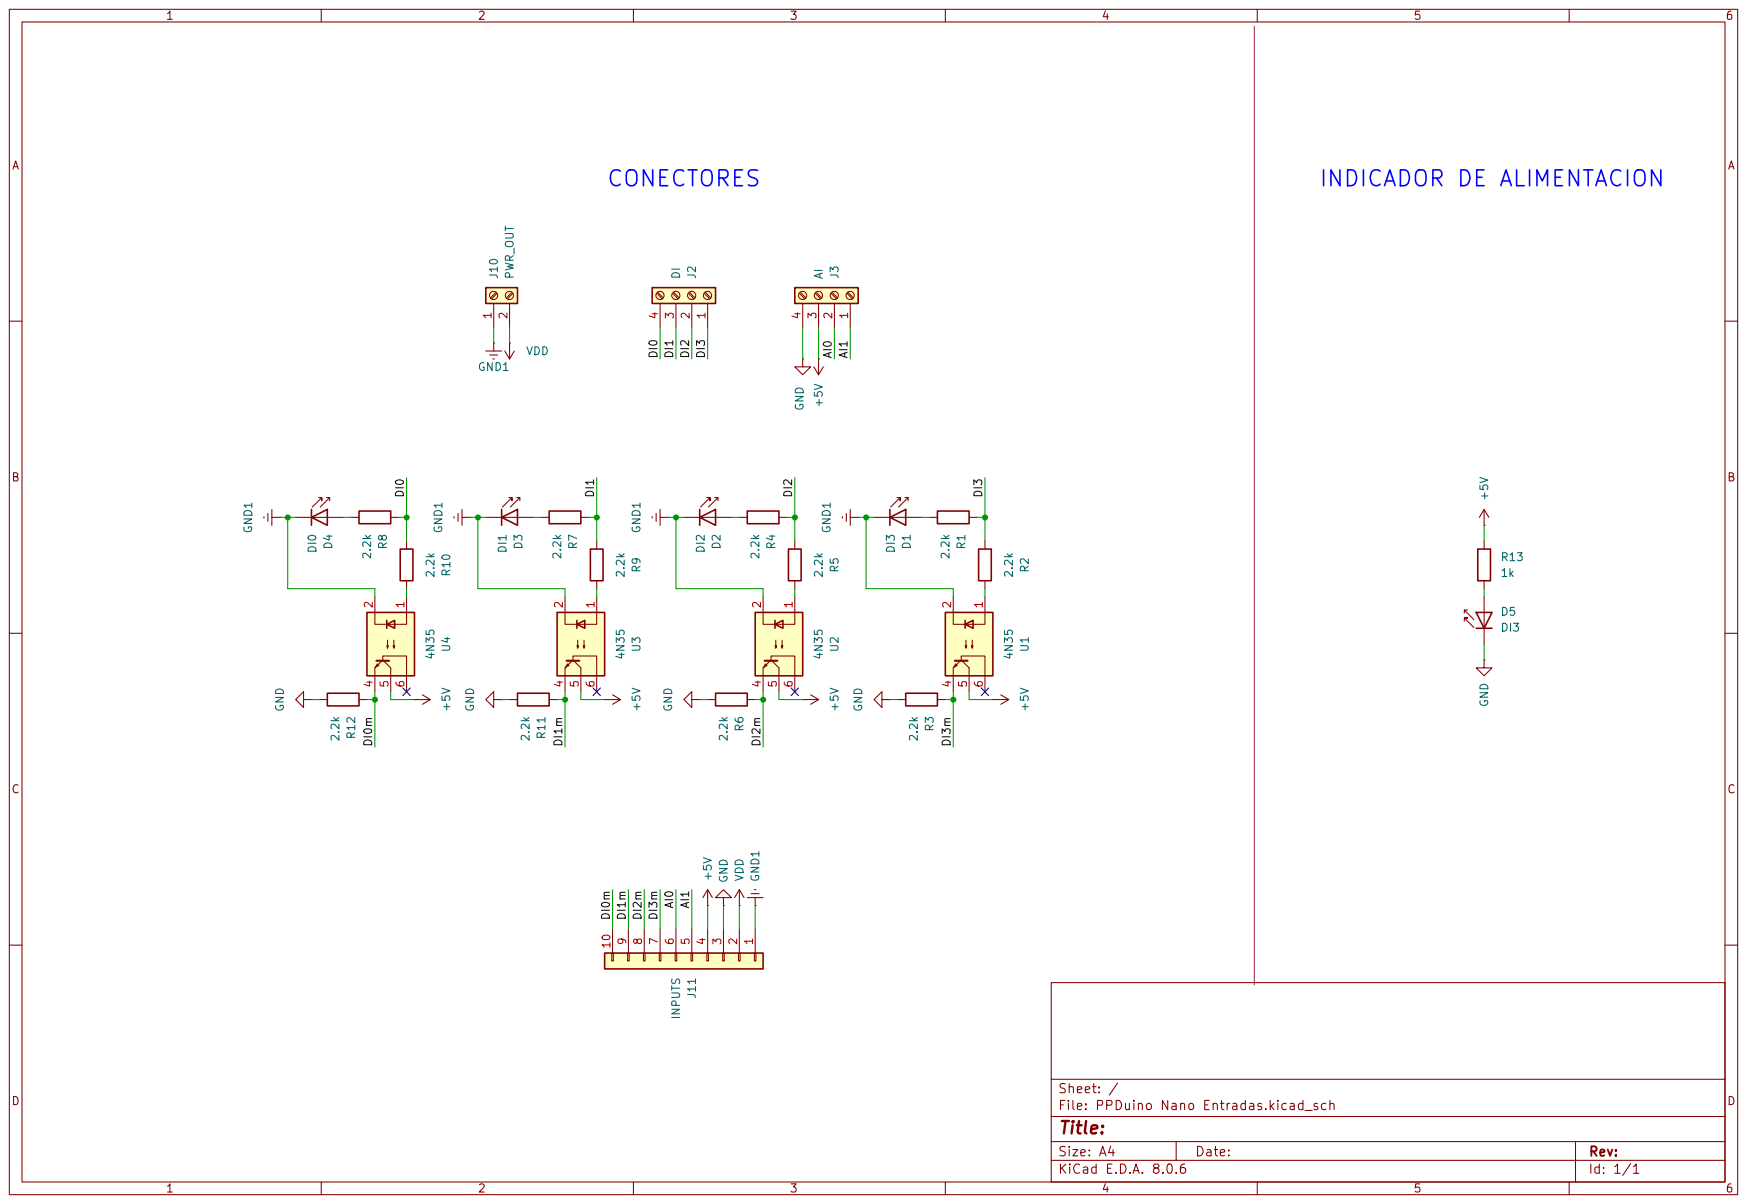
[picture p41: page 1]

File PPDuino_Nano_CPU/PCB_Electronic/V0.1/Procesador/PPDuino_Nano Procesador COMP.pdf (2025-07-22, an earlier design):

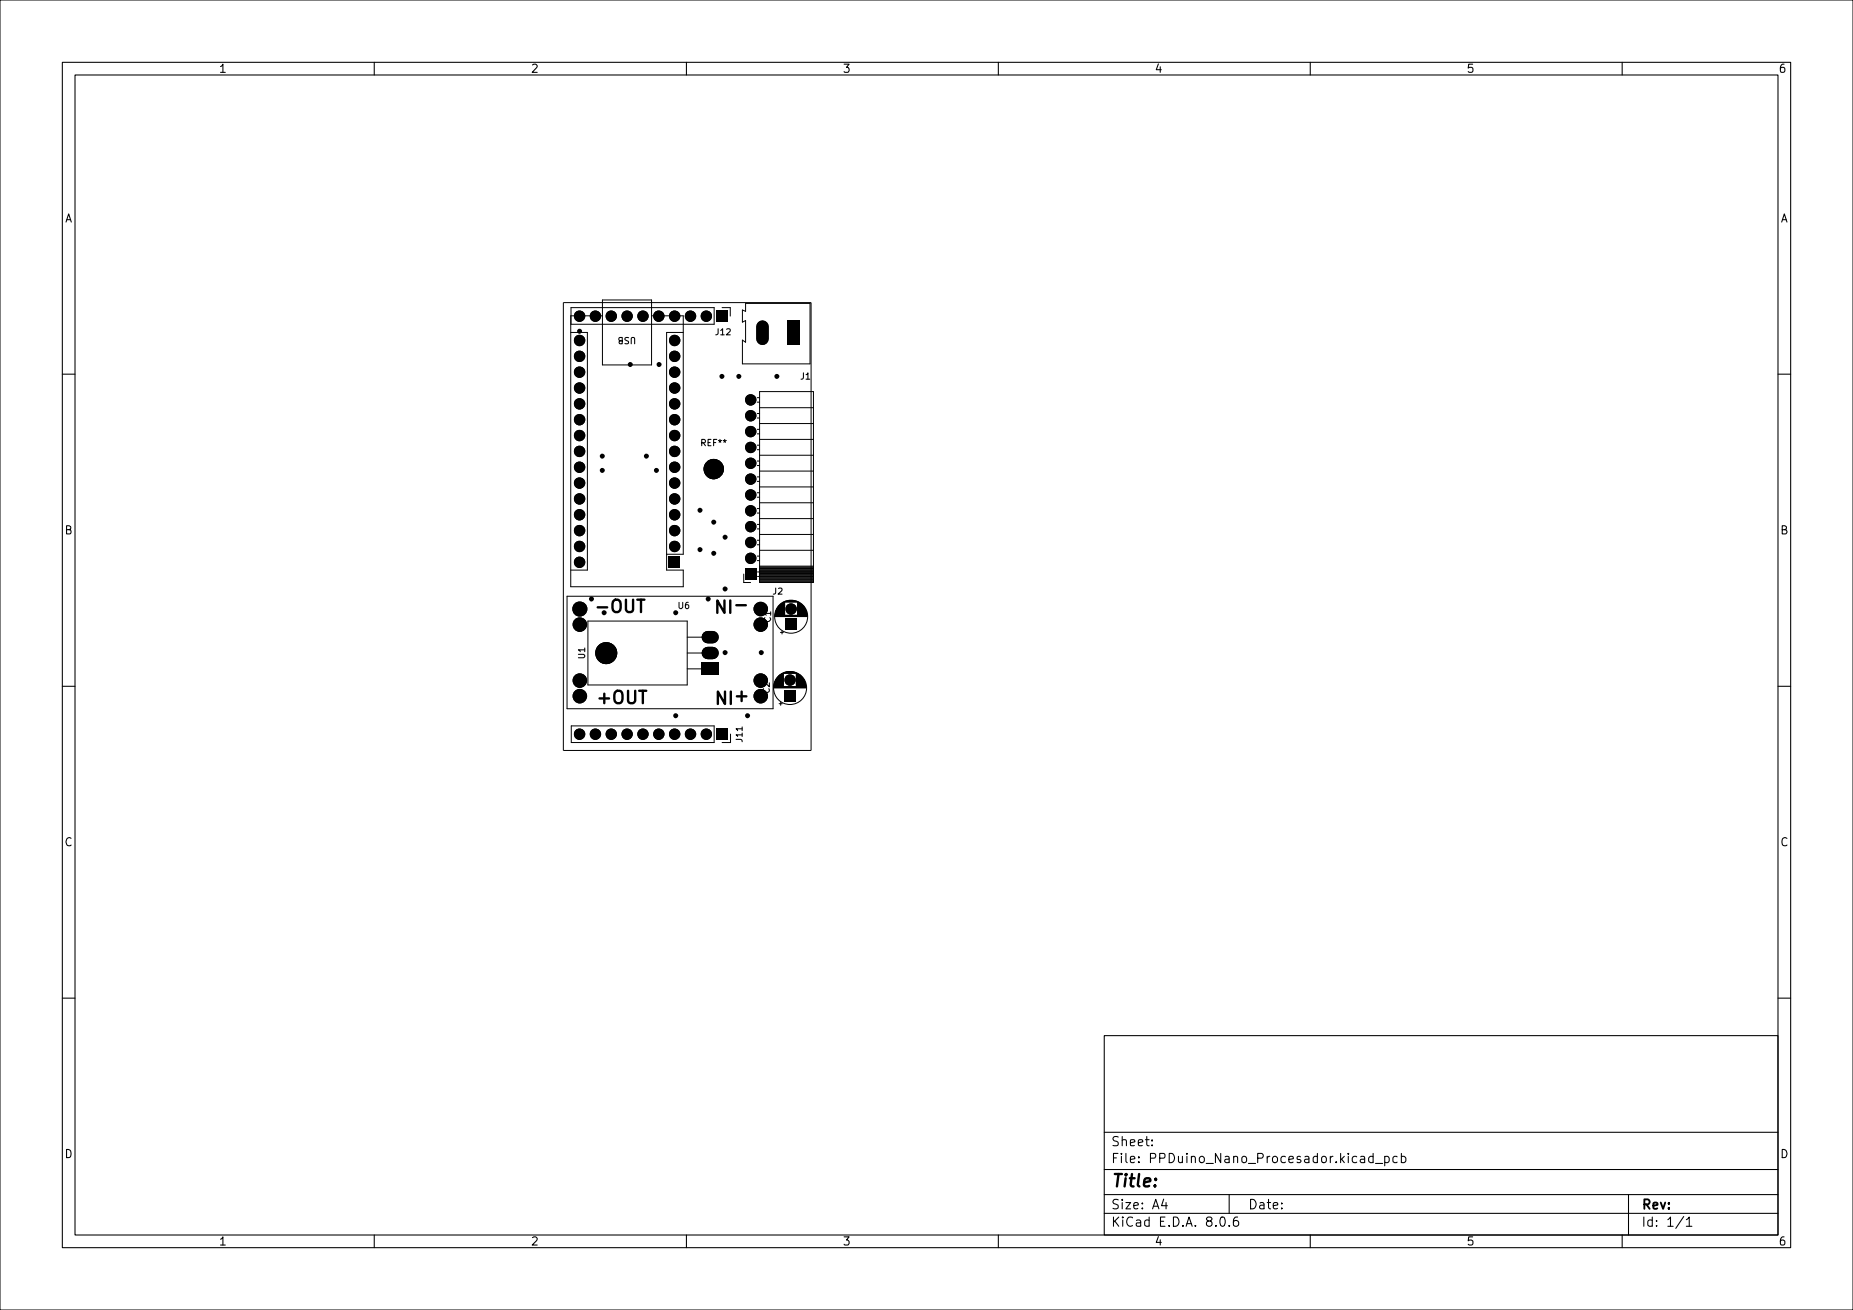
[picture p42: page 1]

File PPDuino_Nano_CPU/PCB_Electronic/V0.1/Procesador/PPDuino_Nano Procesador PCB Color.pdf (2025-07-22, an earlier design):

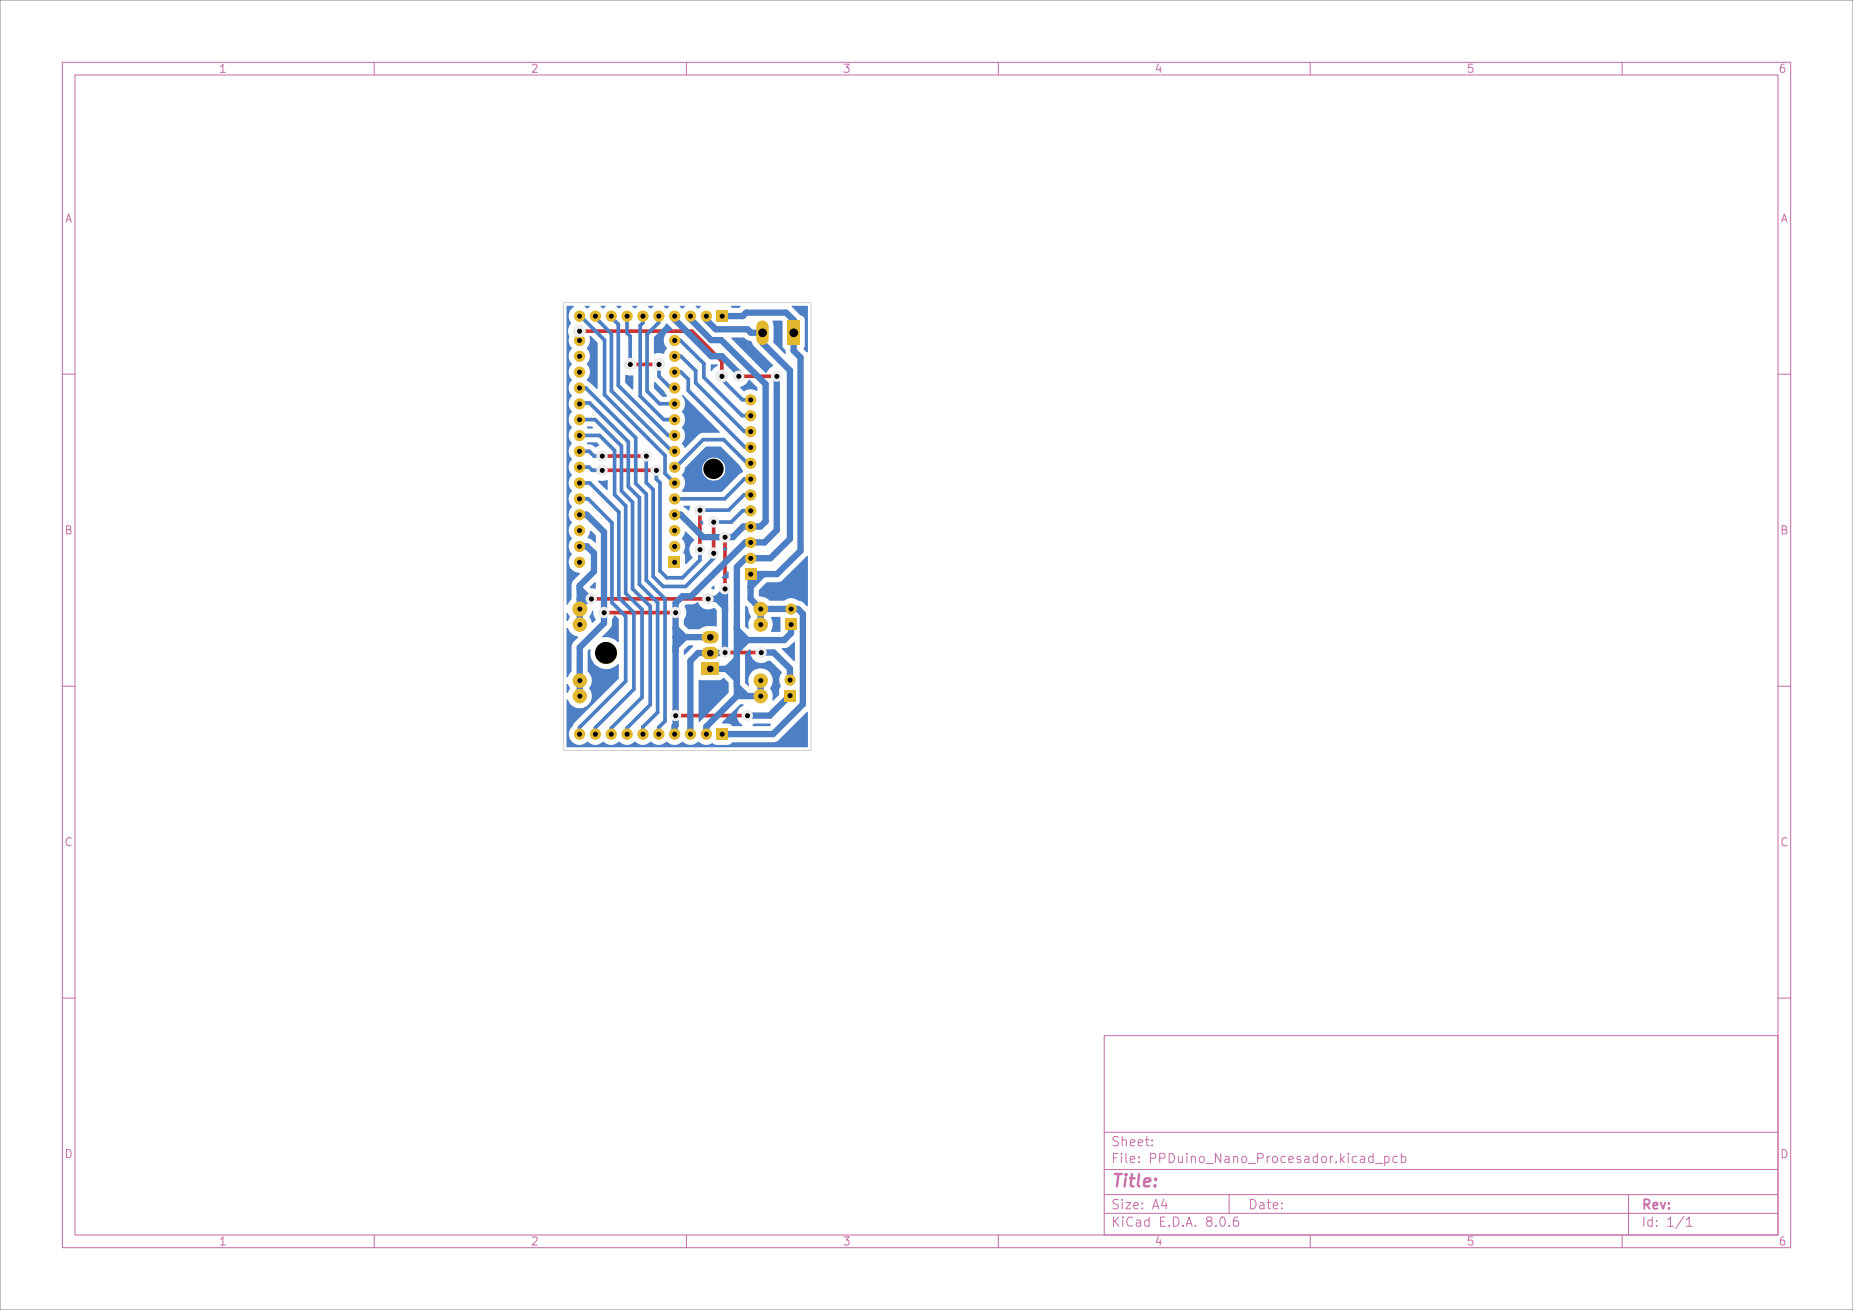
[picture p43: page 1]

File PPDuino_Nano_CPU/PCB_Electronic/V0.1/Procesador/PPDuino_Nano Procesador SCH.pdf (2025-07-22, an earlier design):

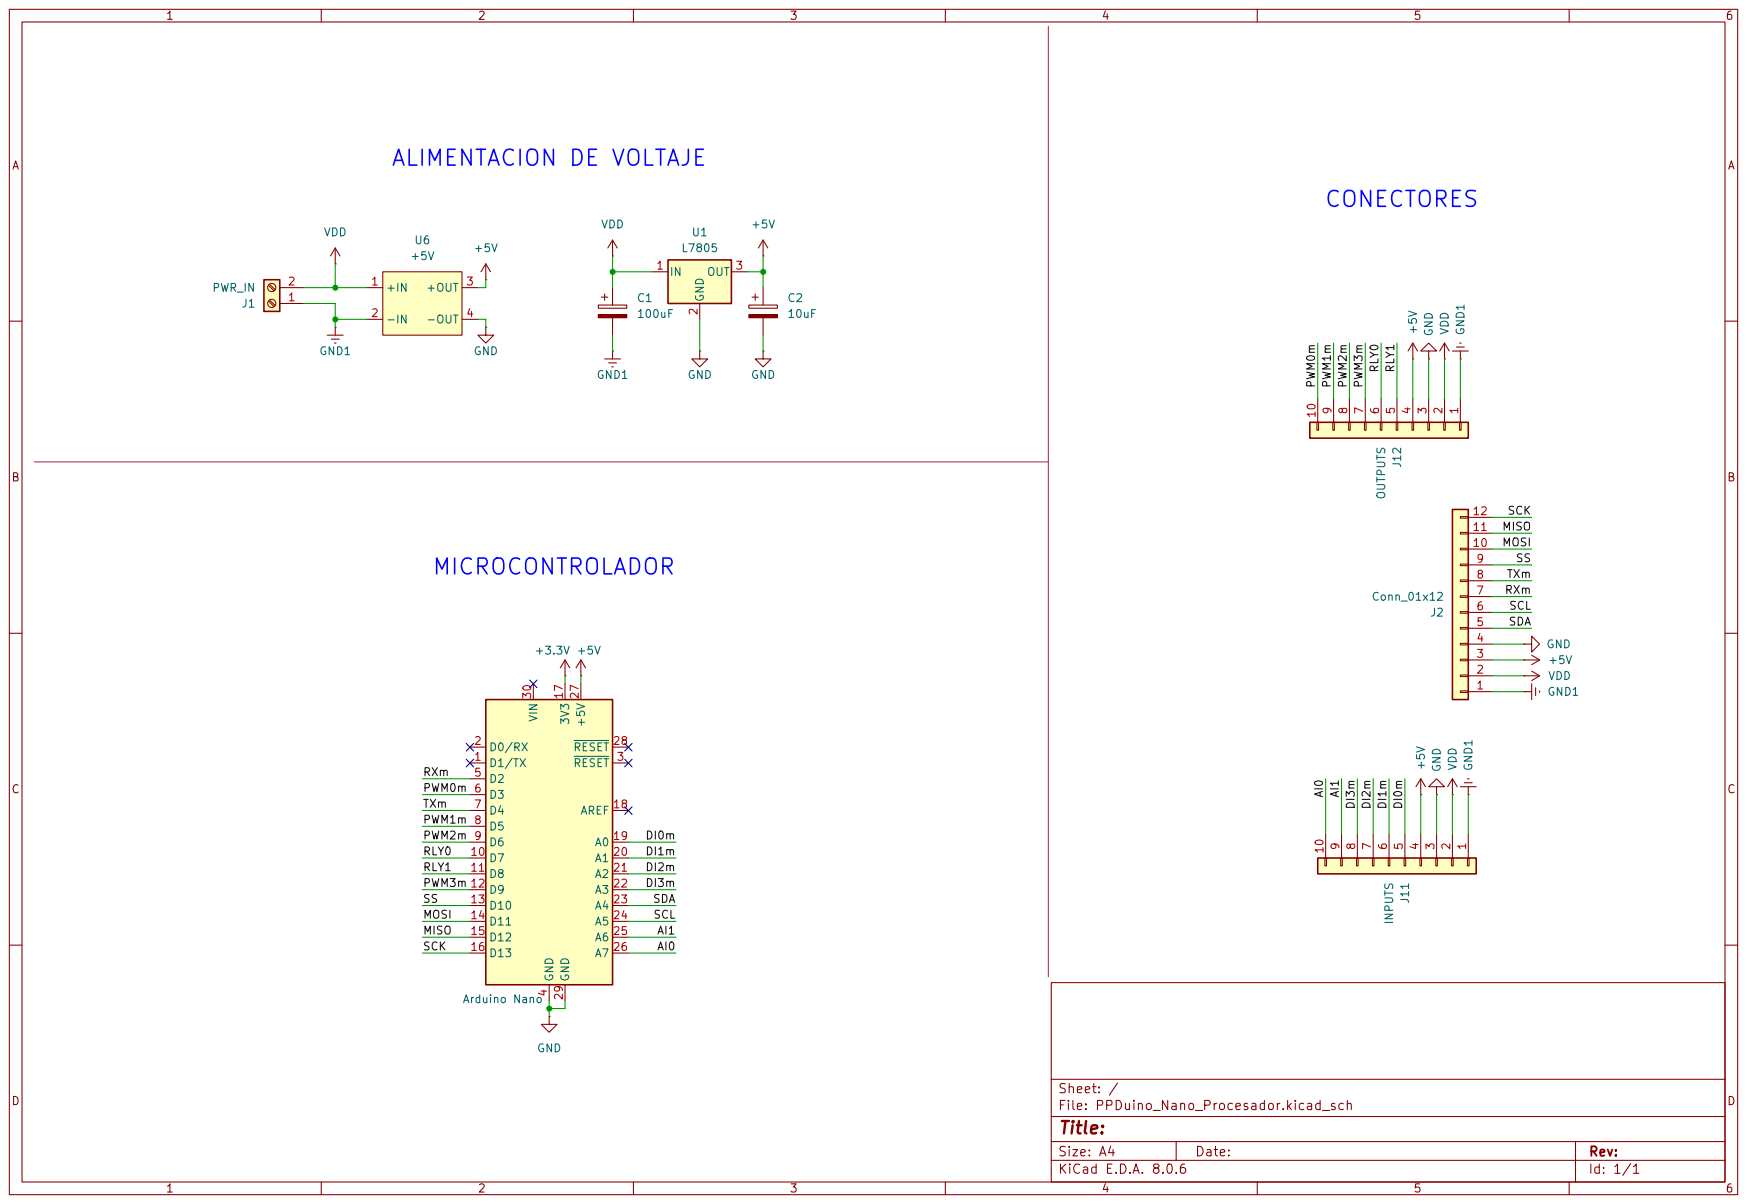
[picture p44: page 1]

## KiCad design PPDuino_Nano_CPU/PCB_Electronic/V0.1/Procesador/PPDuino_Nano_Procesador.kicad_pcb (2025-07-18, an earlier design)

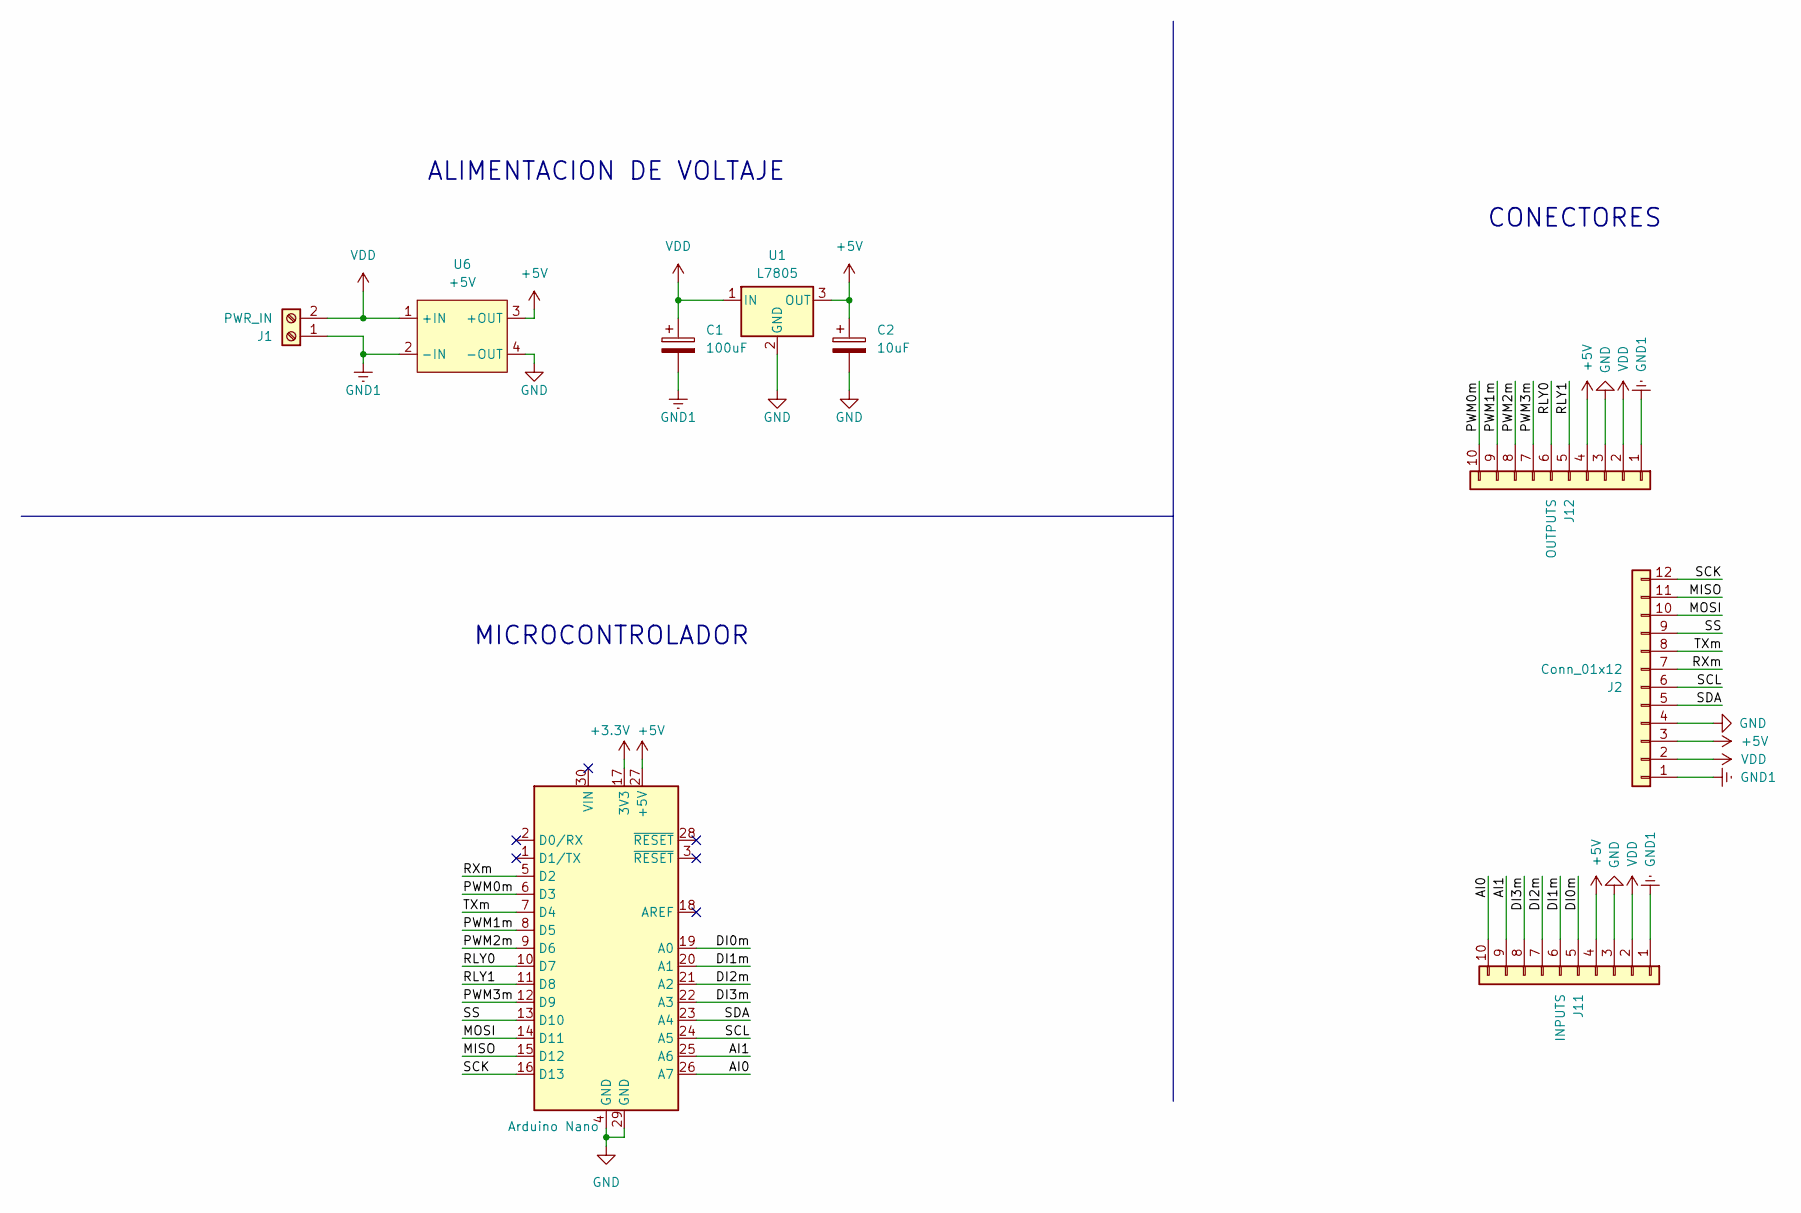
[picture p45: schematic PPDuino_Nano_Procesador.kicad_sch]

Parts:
A1: Arduino Nano; Arduino_Nano
C1: 100uF; CP_Radial_D5.0mm_P2.50mm
C2: 10uF; CP_Radial_D5.0mm_P2.50mm
J1: PWR_IN; TerminalBlock_Altech_AK300-2_P5.00mm
J2: Conn_01x12; PinSocket_1x12_P2.54mm_Horizontal
J11: INPUTS; PinSocket_1x10_P2.54mm_Vertical
J12: OUTPUTS; PinHeader_1x10_P2.54mm_Vertical
U1: L7805; TO-220-3_Horizontal_TabDown
U6: +5V; Mini 560 Pro

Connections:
+3.3V: A1.17 (3V3)
+5V: A1.27 (+5V), C2.1, J2.3, J11.4, J12.4, U1.3 (OUT), U6.3 (+OUT)
/AI0: A1.26 (A7), J11.10
/AI1: A1.25 (A6), J11.9
/DI0m: A1.19 (A0), J11.5
/DI1m: A1.20 (A1), J11.6
/DI2m: A1.21 (A2), J11.7
/DI3m: A1.22 (A3), J11.8
/MISO: A1.15 (D12), J2.11
/MOSI: A1.14 (D11), J2.10
/PWM0m: A1.6 (D3), J12.10
/PWM1m: A1.8 (D5), J12.9
/PWM2m: A1.9 (D6), J12.8
/PWM3m: A1.12 (D9), J12.7
/RLY0: A1.10 (D7), J12.6
/RLY1: A1.11 (D8), J12.5
/RXm: A1.5 (D2), J2.7
/SCK: A1.16 (D13), J2.12
/SCL: A1.24 (A5), J2.6
/SDA: A1.23 (A4), J2.5
/SS: A1.13 (D10), J2.9
/TXm: A1.7 (D4), J2.8
GND: A1.4 (GND), A1.29 (GND), C2.2, J2.4, J11.3, J12.3, U1.2 (GND), U6.4 (-OUT)
GND1: C1.2, J1.1, J2.1, J11.1, J12.1, U6.2 (-IN)
VDD: C1.1, J1.2, J2.2, J11.2, J12.2, U1.1 (IN), U6.1 (+IN)

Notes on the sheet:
CONECTORES
MICROCONTROLADOR
ALIMENTACION DE VOLTAJE

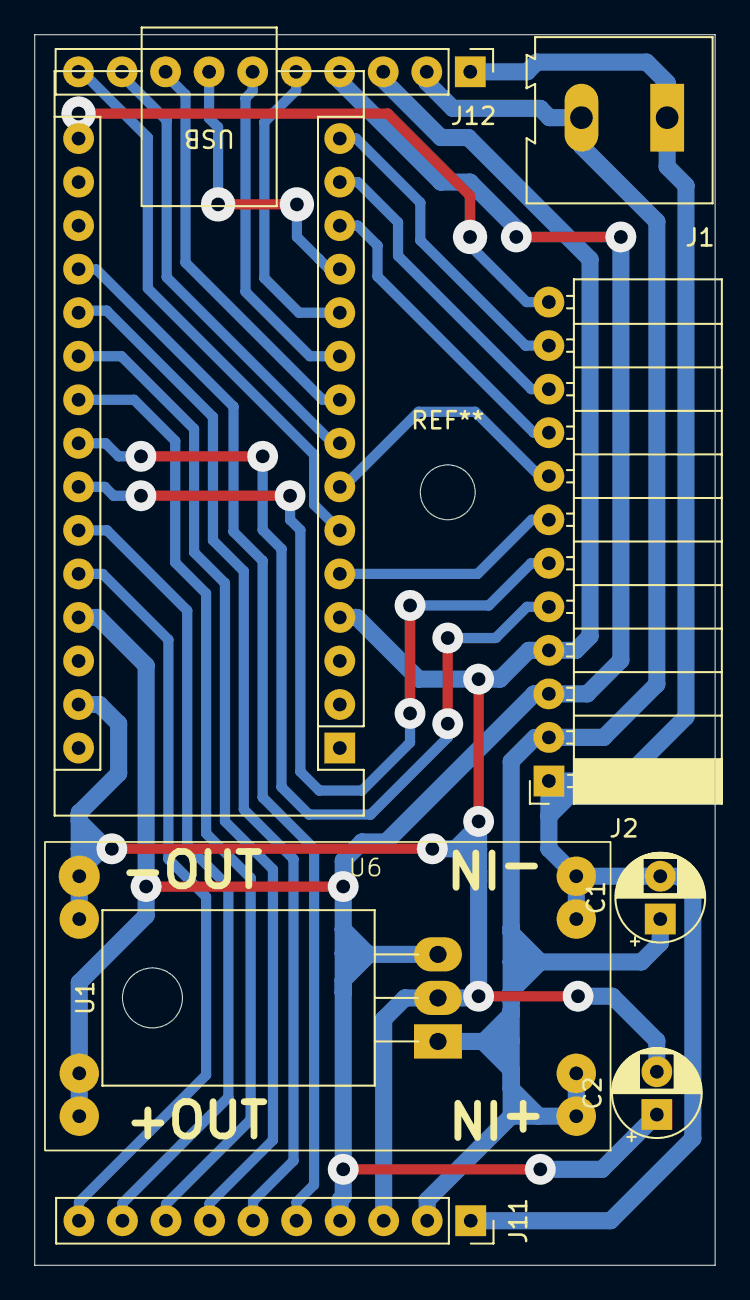
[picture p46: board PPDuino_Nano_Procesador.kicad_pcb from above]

Board: 2 copper layers, 39.7 x 71.8 mm, 9 parts (0 on the bottom side), 24 nets.

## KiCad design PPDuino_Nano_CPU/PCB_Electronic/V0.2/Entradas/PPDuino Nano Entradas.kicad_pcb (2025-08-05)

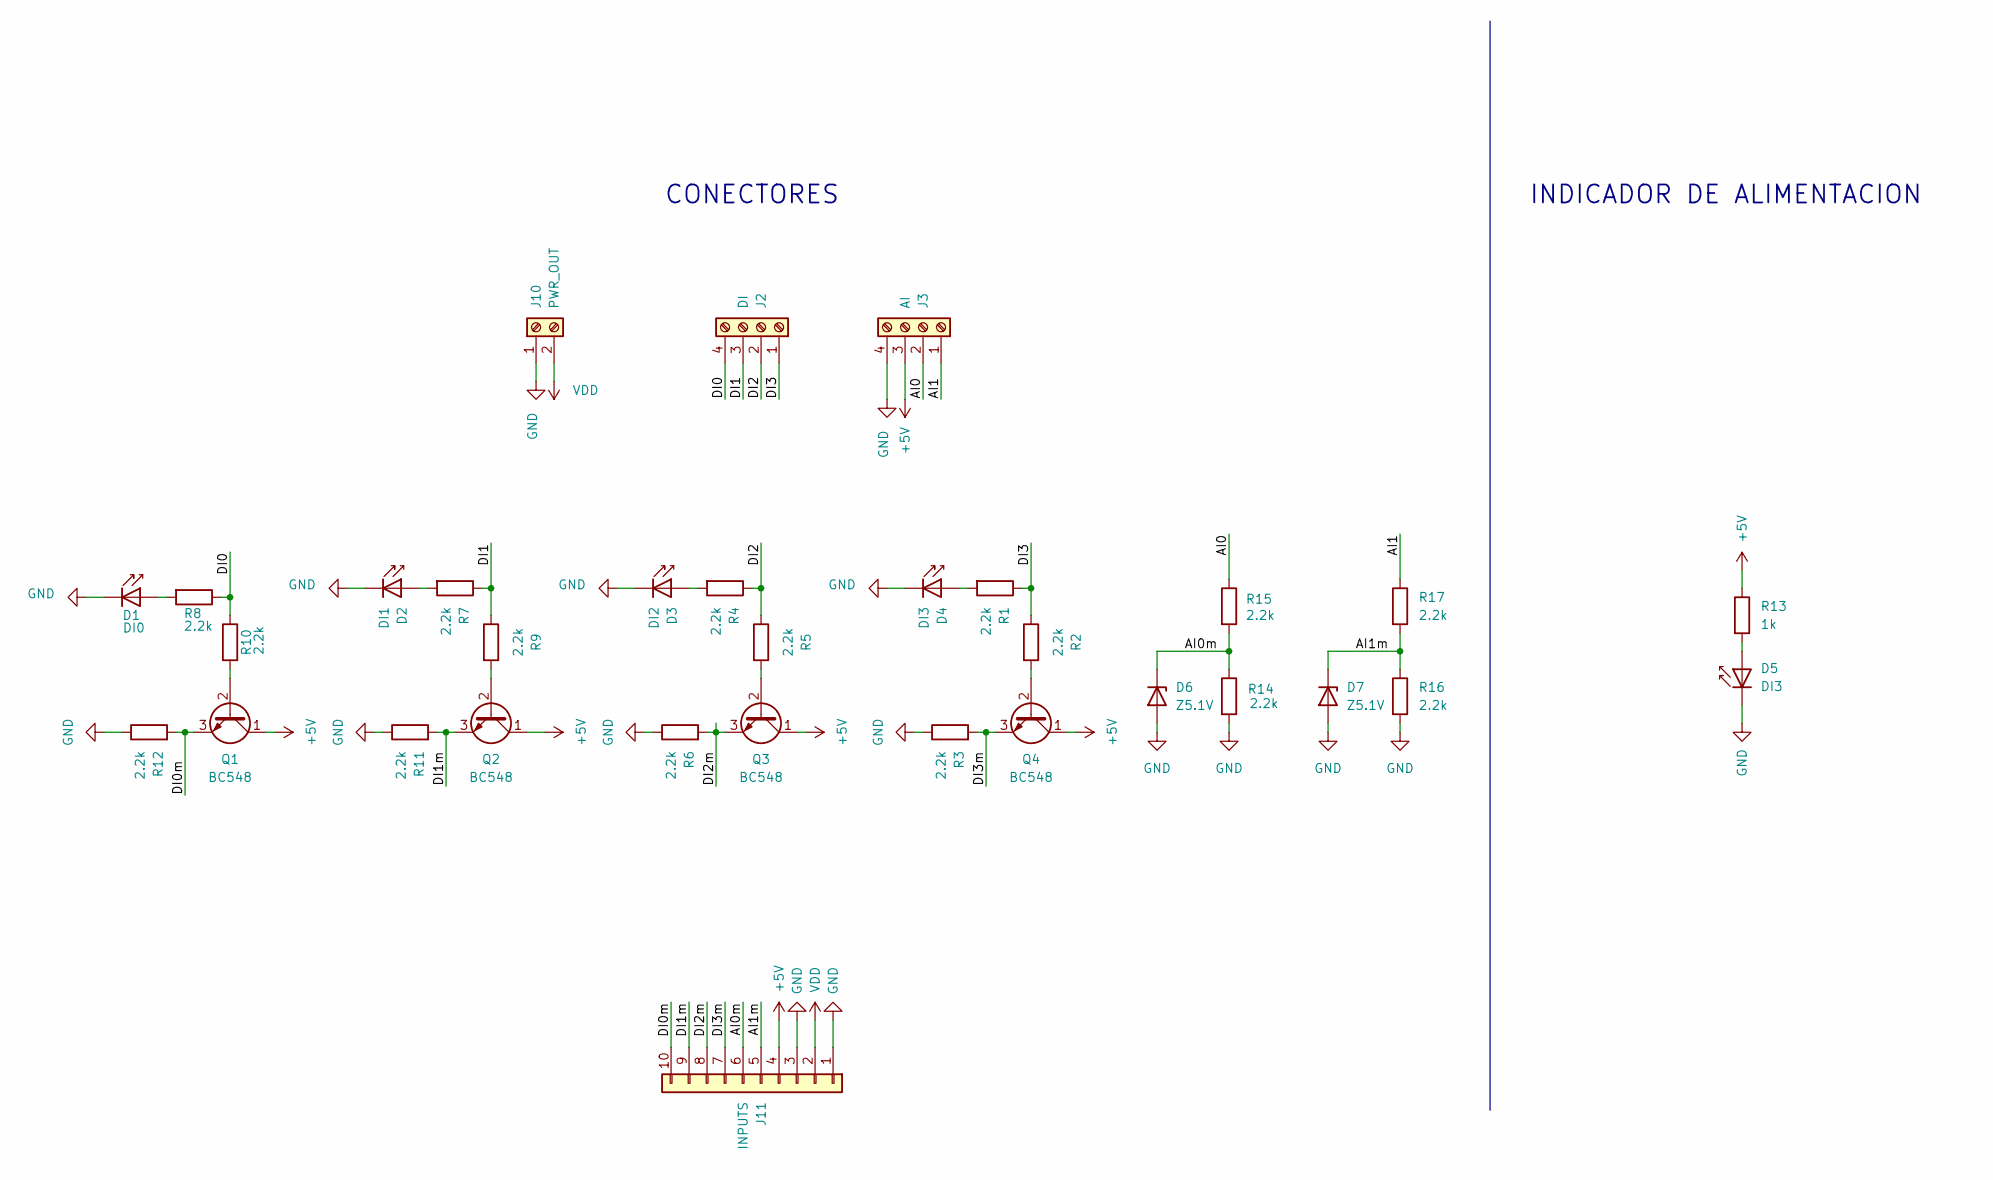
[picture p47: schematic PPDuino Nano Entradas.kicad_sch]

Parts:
D1: DI0; LED_D3.0mm_IRBlack
D2: DI1; LED_D3.0mm_IRBlack
D3: DI2; LED_D3.0mm_IRBlack
D4, D5: DI3; LED_D3.0mm_IRBlack
D6, D7: Z5.1V; D_DO-35_SOD27_P7.62mm_Horizontal
J2: DI; TerminalBlock_Altech_AK300-4_P5.00mm
J3: AI; TerminalBlock_Altech_AK300-4_P5.00mm
J10: PWR_OUT; TerminalBlock_Altech_AK300-2_P5.00mm
J11: INPUTS; PinHeader_1x10_P2.54mm_Vertical
Q1, Q2, Q3, Q4: BC548; TO-92L_Inline_Wide
R1, R2, R3, R4, R5, R6, R7, R8, R9, R10, R11, R12, R14, R15, R16, R17: 2.2k; R_Axial_DIN0207_L6.3mm_D2.5mm_P7.62mm_Horizontal
R13: 1k; R_Axial_DIN0207_L6.3mm_D2.5mm_P7.62mm_Horizontal

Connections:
+5V: J3.3, J11.4, Q1.1 (C), Q2.1 (C), Q3.1 (C), Q4.1 (C), R13.1
/AI0: J3.2, R15.1
/AI0m: D6.1 (K), J11.6, R14.1, R15.2
/AI1: J3.1, R17.1
/AI1m: D7.1 (K), J11.5, R16.1, R17.2
/DI0: J2.4, R8.1, R10.1
/DI0m: J11.10, Q1.3 (E), R12.2
/DI1: J2.3, R7.1, R9.1
/DI1m: J11.9, Q2.3 (E), R11.2
/DI2: J2.2, R4.1, R5.1
/DI2m: J11.8, Q3.3 (E), R6.2
/DI3: J2.1, R1.1, R2.1
/DI3m: J11.7, Q4.3 (E), R3.2
GND: D1.1 (K), D2.1 (K), D3.1 (K), D4.1 (K), D5.1 (K), D6.2 (A), D7.2 (A), J3.4, J10.1, J11.1, J11.3, R3.1, R6.1, R11.1, R12.1, R14.2, R16.2
unnamed: D1.2 (A), R8.2
unnamed: D2.2 (A), R7.2
unnamed: D3.2 (A), R4.2
unnamed: D4.2 (A), R1.2
unnamed: D5.2 (A), R13.2
unnamed: Q1.2 (B), R10.2
unnamed: Q2.2 (B), R9.2
unnamed: Q3.2 (B), R5.2
unnamed: Q4.2 (B), R2.2
VDD: J10.2, J11.2

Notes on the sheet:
INDICADOR DE ALIMENTACION
CONECTORES

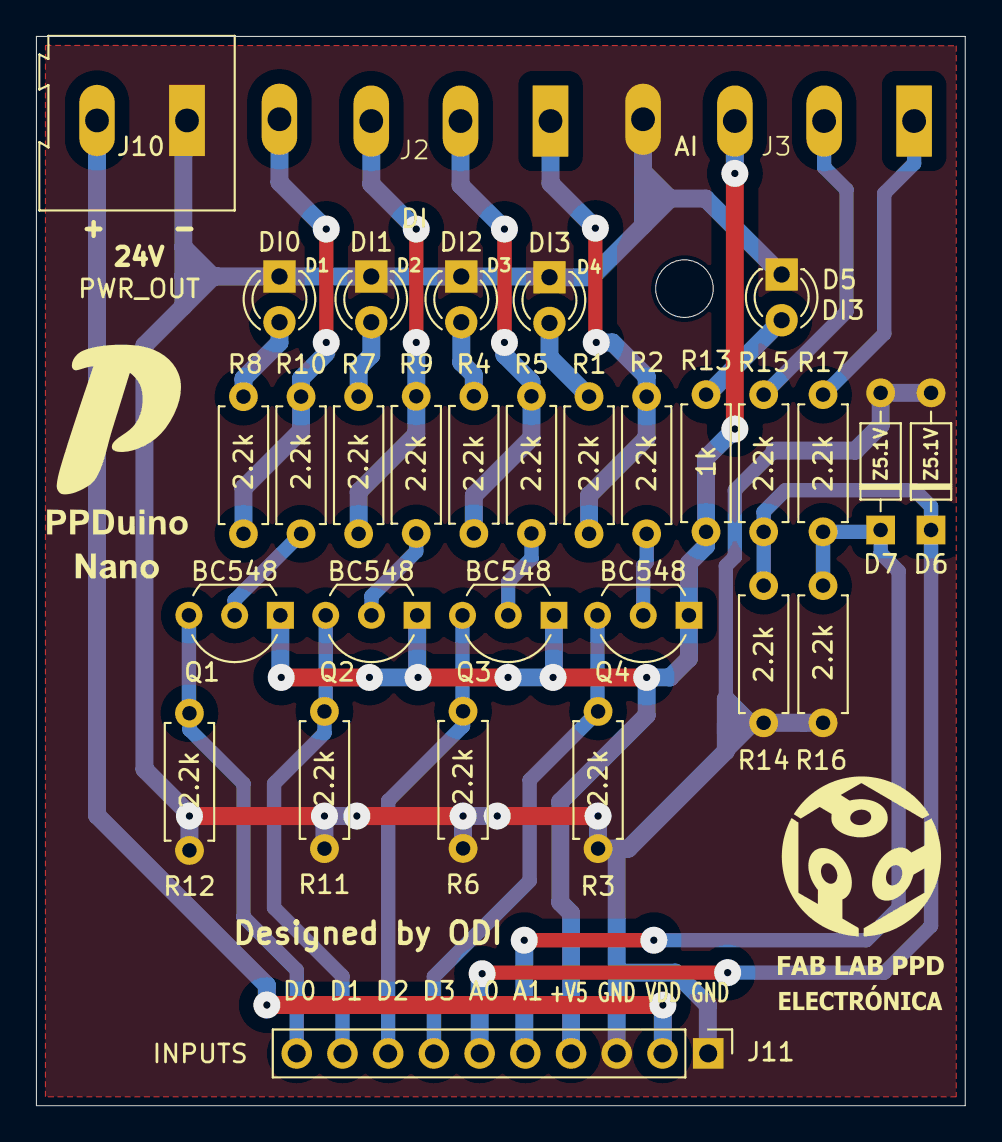
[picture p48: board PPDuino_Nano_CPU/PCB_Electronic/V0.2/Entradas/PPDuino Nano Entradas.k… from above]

Board: 2 copper layers, 51.6 x 59.4 mm, 32 parts (0 on the bottom side), 24 nets.

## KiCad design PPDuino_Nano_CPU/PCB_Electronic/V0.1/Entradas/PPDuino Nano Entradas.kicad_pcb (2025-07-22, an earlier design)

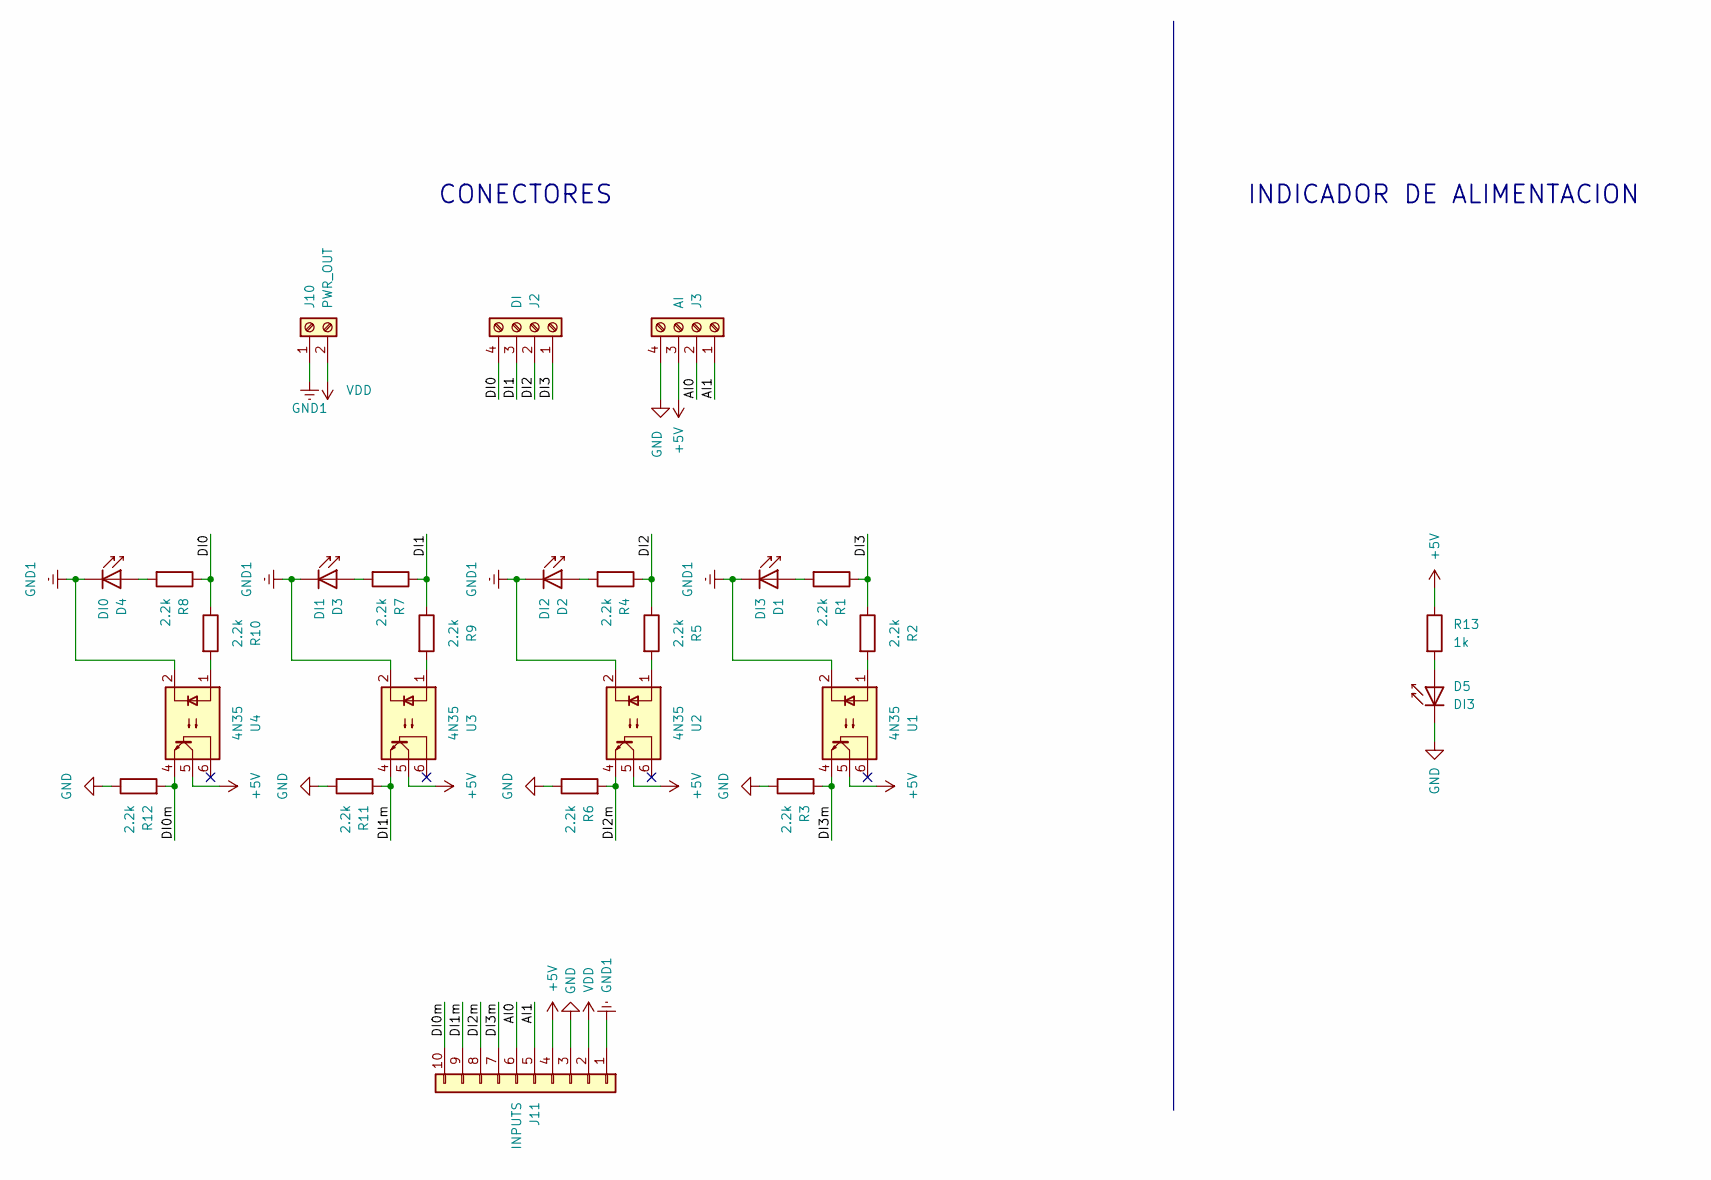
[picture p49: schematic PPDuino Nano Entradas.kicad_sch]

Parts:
D1, D5: DI3; LED_D3.0mm_IRBlack
D2: DI2; LED_D3.0mm_IRBlack
D3: DI1; LED_D3.0mm_IRBlack
D4: DI0; LED_D3.0mm_IRBlack
J2: DI; TerminalBlock_Altech_AK300-4_P5.00mm
J3: AI; TerminalBlock_Altech_AK300-4_P5.00mm
J10: PWR_OUT; TerminalBlock_Altech_AK300-2_P5.00mm
J11: INPUTS; PinHeader_1x10_P2.54mm_Vertical
R1, R2, R3, R4, R5, R6, R7, R8, R9, R10, R11, R12: 2.2k; R_Axial_DIN0207_L6.3mm_D2.5mm_P7.62mm_Horizontal
R13: 1k; R_Axial_DIN0207_L6.3mm_D2.5mm_P7.62mm_Horizontal
U1, U2, U3, U4: 4N35; DIP-6_W7.62mm_LongPads

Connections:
+5V: J3.3, J11.4, R13.1, U1.5, U2.5, U3.5, U4.5
/AI0: J3.2, J11.6
/AI1: J3.1, J11.5
/DI0: J2.4, R8.1, R10.1
/DI0m: J11.10, R12.2, U4.4
/DI1: J2.3, R7.1, R9.1
/DI1m: J11.9, R11.2, U3.4
/DI2: J2.2, R4.1, R5.1
/DI2m: J11.8, R6.2, U2.4
/DI3: J2.1, R1.1, R2.1
/DI3m: J11.7, R3.2, U1.4
GND: D5.1 (K), J3.4, J11.3, R3.1, R6.1, R11.1, R12.1
GND1: D1.1 (K), D2.1 (K), D3.1 (K), D4.1 (K), J10.1, J11.1, U1.2, U2.2, U3.2, U4.2
unnamed: D1.2 (A), R1.2
unnamed: D2.2 (A), R4.2
unnamed: D3.2 (A), R7.2
unnamed: D4.2 (A), R8.2
unnamed: D5.2 (A), R13.2
unnamed: R2.2, U1.1
unnamed: R5.2, U2.1
unnamed: R9.2, U3.1
unnamed: R10.2, U4.1
VDD: J10.2, J11.2

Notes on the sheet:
INDICADOR DE ALIMENTACION
CONECTORES

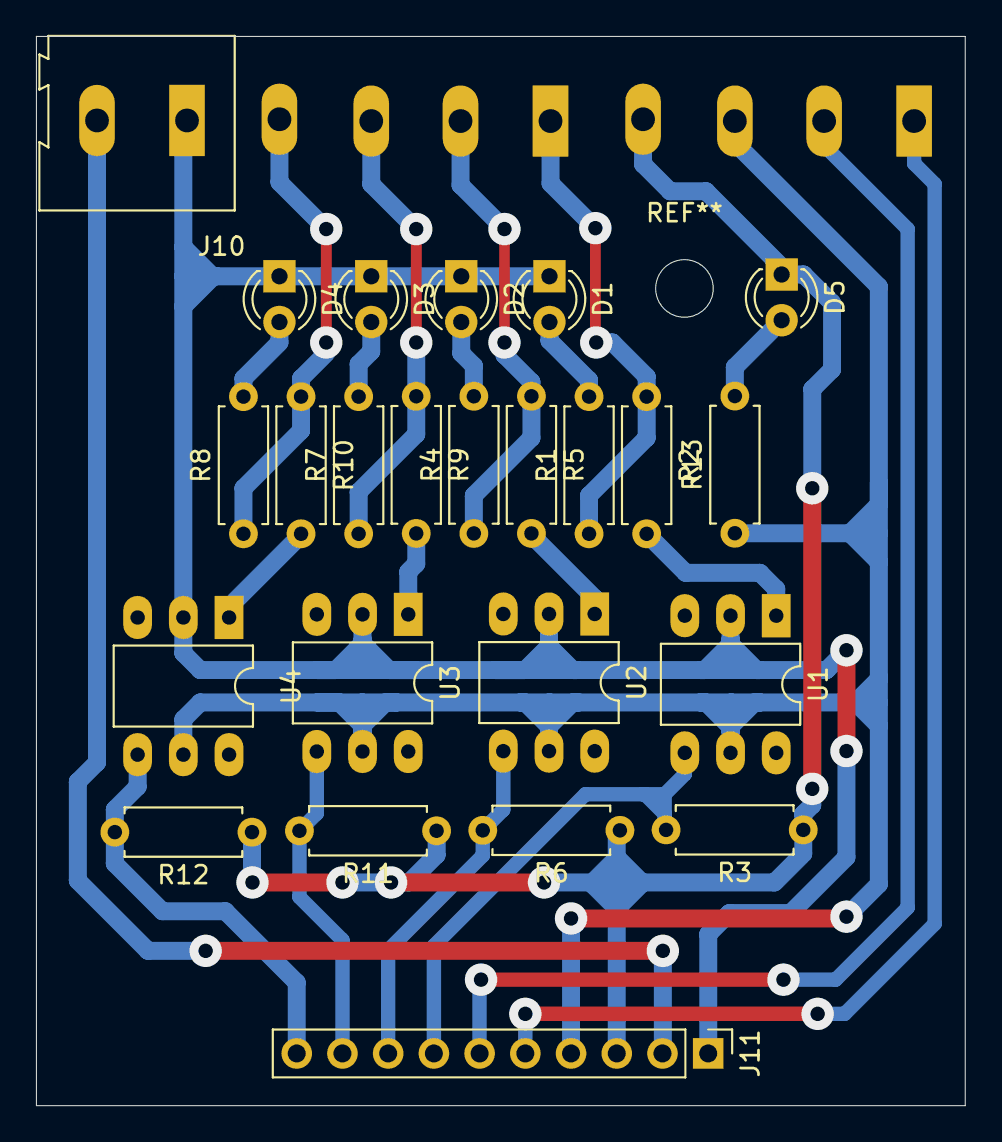
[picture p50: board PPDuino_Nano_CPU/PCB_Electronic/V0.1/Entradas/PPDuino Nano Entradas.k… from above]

Board: 2 copper layers, 51.6 x 59.4 mm, 26 parts (0 on the bottom side), 23 nets.

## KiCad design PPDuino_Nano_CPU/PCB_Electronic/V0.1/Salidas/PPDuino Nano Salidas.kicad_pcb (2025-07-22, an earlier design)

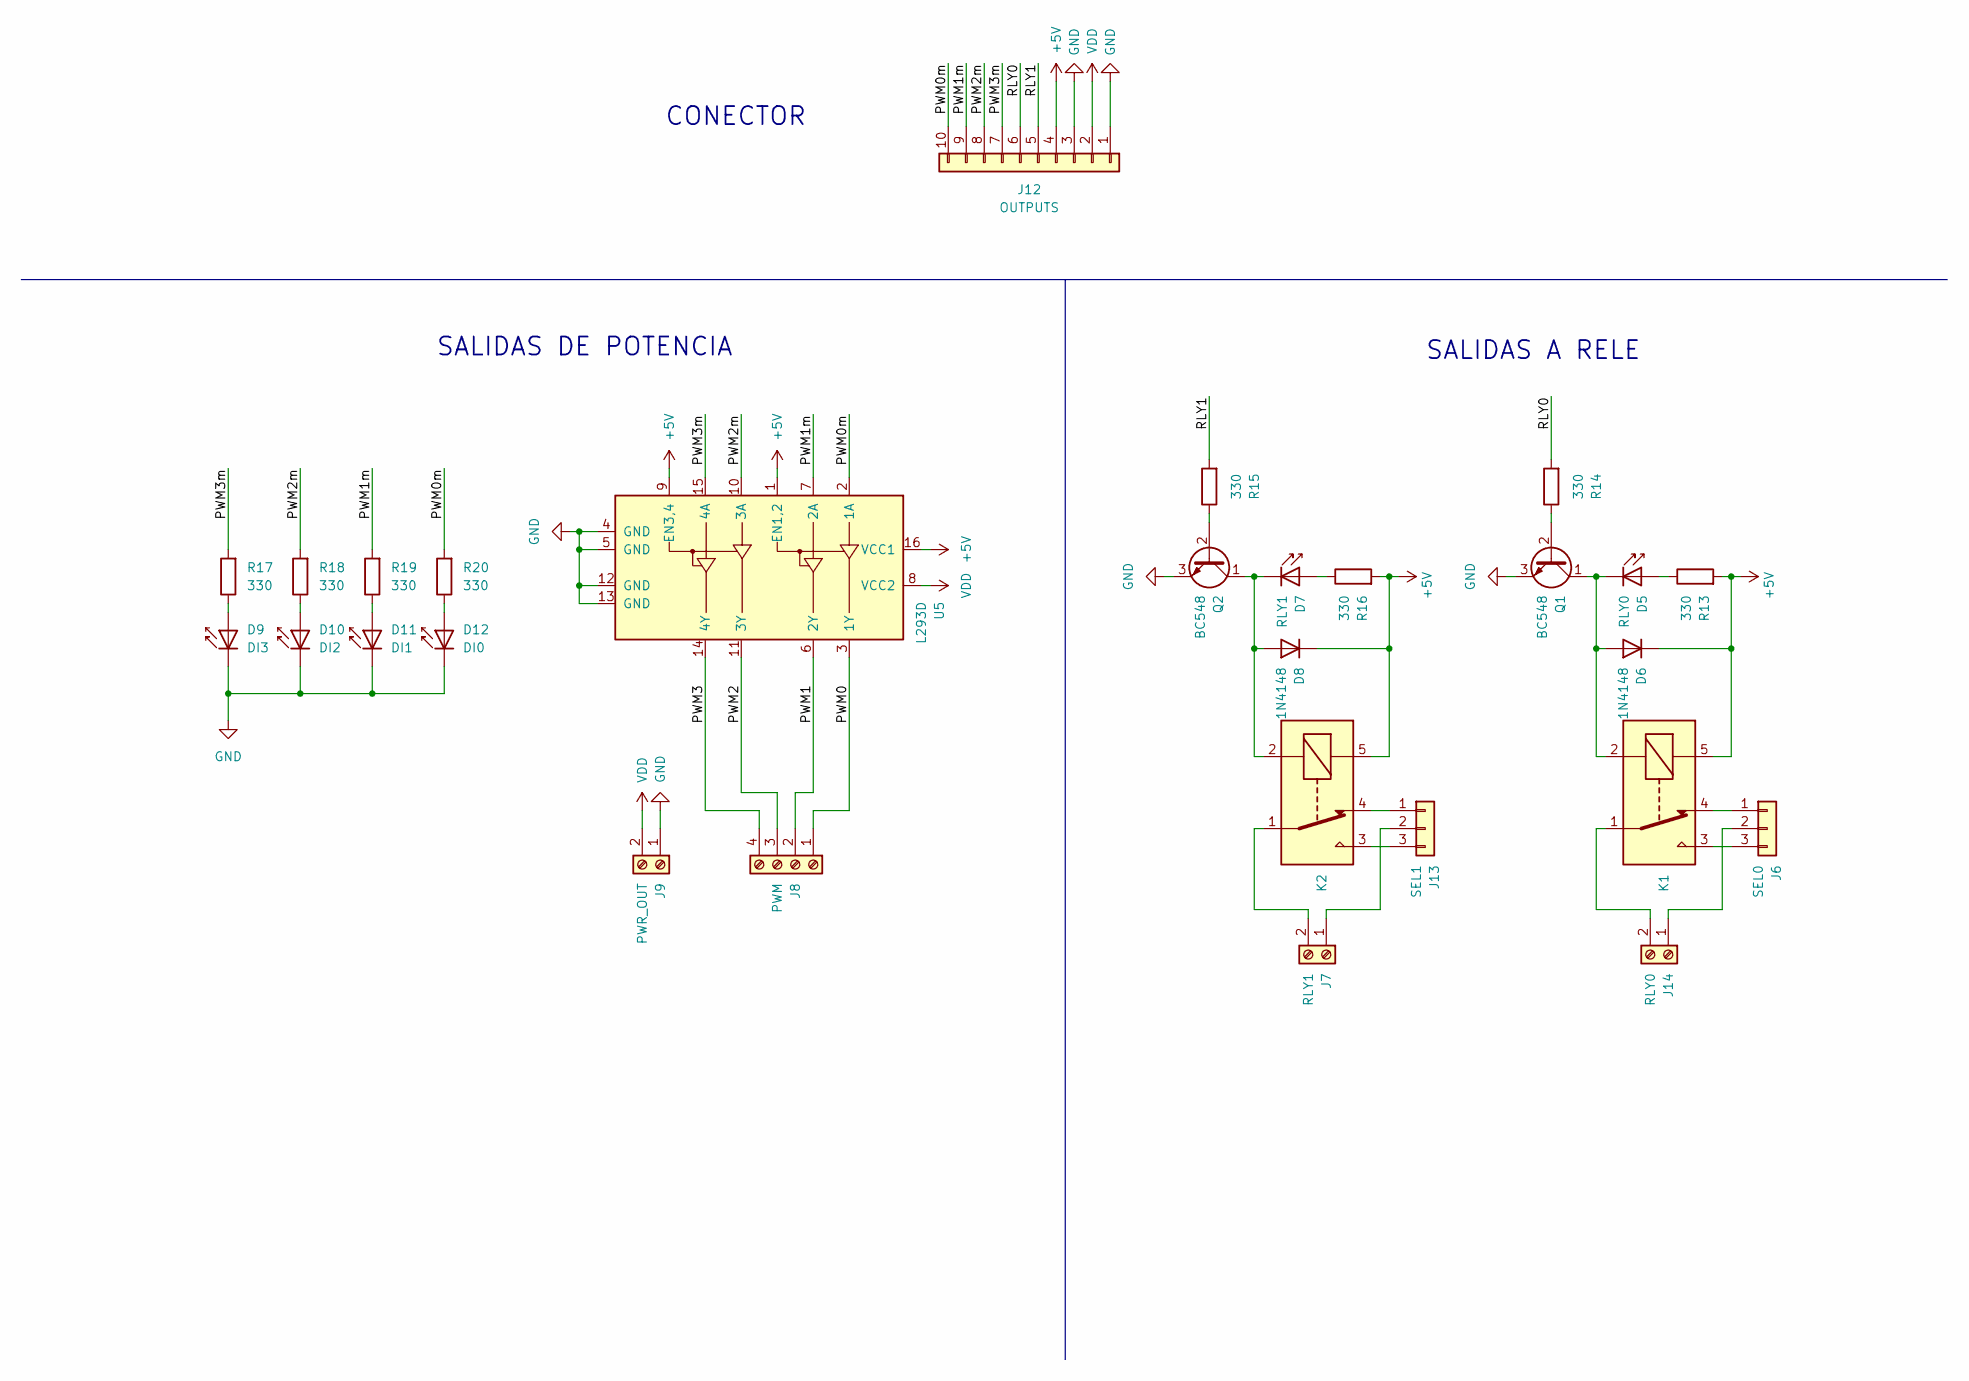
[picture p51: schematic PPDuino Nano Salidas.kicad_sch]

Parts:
D5: RLY0; LED_D3.0mm_IRBlack
D6, D8: 1N4148; D_DO-35_SOD27_P7.62mm_Horizontal
D7: RLY1; LED_D3.0mm_IRBlack
D9: DI3; LED_D3.0mm_IRBlack
D10: DI2; LED_D3.0mm_IRBlack
D11: DI1; LED_D3.0mm_IRBlack
D12: DI0; LED_D3.0mm_IRBlack
J6: SEL0; PinHeader_1x03_P2.54mm_Vertical
J7: RLY1; TerminalBlock_Altech_AK300-2_P5.00mm
J8: PWM; TerminalBlock_Altech_AK300-4_P5.00mm
J9: PWR_OUT; TerminalBlock_Altech_AK300-2_P5.00mm
J12: OUTPUTS; PinHeader_1x10_P2.54mm_Vertical
J13: SEL1; PinHeader_1x03_P2.54mm_Vertical
J14: RLY0; TerminalBlock_Altech_AK300-2_P5.00mm
K1, K2: Relay
Q1, Q2: BC548; TO-92L_Inline_Wide
R13, R14, R15, R16, R17, R18, R19, R20: 330; R_Axial_DIN0207_L6.3mm_D2.5mm_P7.62mm_Horizontal
U5: L293D; DIP-16_W7.62mm_LongPads

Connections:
+5V: D6.1 (K), D8.1 (K), J12.4, K1.5, K2.5, R13.2, R16.2, U5.1 (EN1,2), U5.9 (EN3,4), U5.16 (VCC1)
/PWM0: J8.1, U5.3 (1Y)
/PWM0m: J12.10, R20.2, U5.2 (1A)
/PWM1: J8.2, U5.6 (2Y)
/PWM1m: J12.9, R19.2, U5.7 (2A)
/PWM2: J8.3, U5.11 (3Y)
/PWM2m: J12.8, R18.2, U5.10 (3A)
/PWM3: J8.4, U5.14 (4Y)
/PWM3m: J12.7, R17.2, U5.15 (4A)
/RLY0: J12.6, R14.2
/RLY1: J12.5, R15.2
GND: D9.1 (K), D10.1 (K), D11.1 (K), D12.1 (K), J9.1, J12.1, J12.3, Q1.3 (E), Q2.3 (E), U5.4 (GND), U5.5 (GND), U5.12 (GND), U5.13 (GND)
unnamed: D5.2 (A), R13.1
unnamed: D5.1 (K), D6.2 (A), K1.2, Q1.1 (C)
unnamed: D7.2 (A), R16.1
unnamed: D7.1 (K), D8.2 (A), K2.2, Q2.1 (C)
unnamed: D9.2 (A), R17.1
unnamed: D10.2 (A), R18.1
unnamed: D11.2 (A), R19.1
unnamed: D12.2 (A), R20.1
unnamed: J6.1, K1.4
unnamed: J6.3, K1.3
unnamed: J7.2, K2.1
unnamed: J13.1, K2.4
unnamed: J7.1, J13.2
unnamed: J13.3, K2.3
unnamed: J6.2, J14.1
unnamed: J14.2, K1.1
unnamed: Q1.2 (B), R14.1
unnamed: Q2.2 (B), R15.1
VDD: J9.2, J12.2, U5.8 (VCC2)

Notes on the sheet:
SALIDAS DE POTENCIA
SALIDAS A RELE
CONECTOR

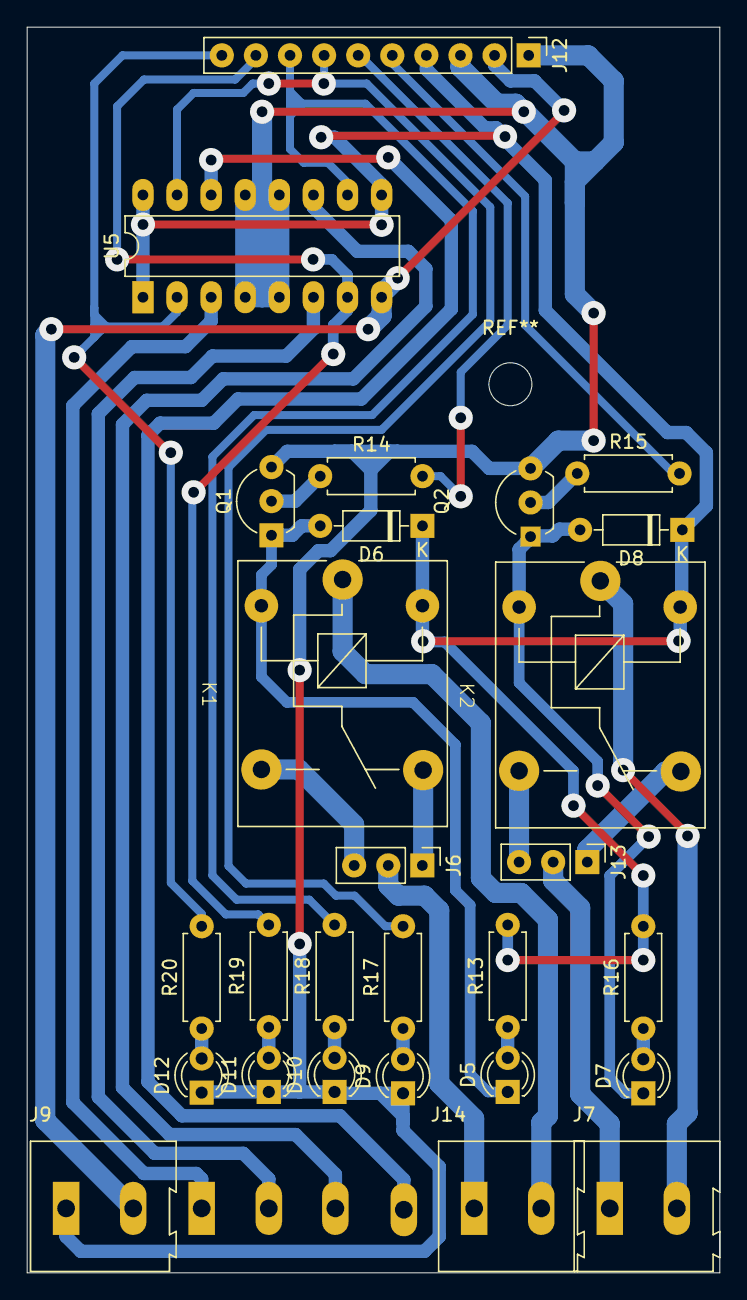
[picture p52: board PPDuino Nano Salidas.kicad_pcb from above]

Board: 2 copper layers, 51.6 x 92.8 mm, 28 parts (0 on the bottom side), 31 nets.

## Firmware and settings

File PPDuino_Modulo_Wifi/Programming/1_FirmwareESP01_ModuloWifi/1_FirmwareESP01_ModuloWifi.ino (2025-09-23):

#include <ESP8266WiFi.h>
#include <PubSubClient.h>

#define ODI
#ifdef ODI
  String wifiSsid = "ODIWAN";
  String wifiPassword = "Fablab@12345";
#endif
#ifdef CODIGO
  String wifiSsid = "SSID";
  String wifiPassword = "password";
#endif

bool wifiConnect = false;
bool stateWifi = false;

WiFiClient espClient;
PubSubClient mqttClient(espClient);
String mqttId = "ESP8266Client-"+ String(random(0xffff), HEX);
String mqttServer = "test.mosquitto.org";
int mqttPort = 1883;
String mqttUser = "ugordillo";
String mqttPassword = "12345678";
bool mqttTls = false;
bool mqttConnect = false;

char mqttServerArray[50];
char messageArray[50];
char topicArray[50];

bool modeMqtt = false;    // Para ejecutar Read o Write por MQTT
bool stateMqtt = false;   // Para habilitar ejecucion de comando con MQTT
char inChar;
String inString = "",inTopic = "",inMessage = "";

// ***************************************
// FUNCIONES DE CONEXION WIFI
// ***************************************
// Funcion para conectar a red Wifi
bool connectWifi() {
  // Iniciar la conexion a red Wifi
  Serial.print("Connecting to " + wifiSsid + " ");
  WiFi.mode(WIFI_STA);
  WiFi.begin(wifiSsid, wifiPassword);
  // Tiempo para establecer conexion  
  delay(500);    
  byte intentos=0;
  while (WiFi.status() != WL_CONNECTED) {
    delay(500);
    Serial.print(".");
    intentos++;
    if (intentos>40){  break;  }
  }
  // Evaluar estado para devolución de conexión
  if (WiFi.status() != WL_CONNECTED) {
    Serial.print(" ");
    Serial.print("NoIP");
    return false;
  }
  else {
    Serial.print(" ");
    Serial.print(WiFi.localIP());
    return true;
  }
}
// ***************************************
// Funcion para desconectar a red Wifi
bool disconnectWifi() {
  // Iniciar la desconexion a red Wifi
  Serial.print("Disconnecting from " + wifiSsid + " ");
  WiFi.disconnect();
  // Tiempo para establecer desconexion
  delay(500);    
  // Evaluar estado para devolución de conexión
  if (WiFi.status() != WL_CONNECTED) {  return true;  } // WiFi desconectado
  else {                                return false; } // WiFi conectado
}
// ***************************************
// Funcion para resetear conexion a red Wifi
bool resetWifi() {
  // Iniciar la desconexion a red Wifi
  if (disconnectWifi()){
    Serial.print(">OK>");
    wifiConnect = false;
    if (connectWifi()){   return true;    }
    else{                 return false;   }
  }
  else{
    Serial.println(">ERROR");
    wifiConnect = true;
    return false;
  }
}
// ***************************************
// Funcion para estado de red Wifi
bool statusWifi() {
  // Evaluar estado para devolución de conexión
  if (WiFi.status() != WL_CONNECTED) {  return false; } // WiFi desconectado
  else {                                return true;  } // WiFi conectado
}

// ***************************************
// FUNCIONES DE COMUNICACION MQTT
// ***************************************
// Funcion para recibir suscripciones
void mqttCallback(char* topic, byte* payload, unsigned int length) {
  String topico = String((char*)topic);
  String mensaje = (String((char*)payload)).substring(0,length);
  Serial.print(topico);
  Serial.print('<');
  Serial.println(mensaje);
}
// ***************************************
// Funcion para configurar MQTT
void mqttSetup(){
  mqttServer.toCharArray( mqttServerArray, 100 );
  mqttClient.setServer(mqttServerArray, mqttPort);
  mqttClient.setCallback(mqttCallback);
}
// ***************************************
// Funcion para conectar a broker MQTT
bool mqttConnectGo() {
  // Loop until we're reconnected
  while (!mqttClient.connected()) {
    Serial.print("Connecting to " + mqttServer + " ...");
    // Attempt to connect
    if (mqttClient.connect(mqttId.c_str())) {
      Serial.print("Connected");
      // Once connected, publish an announcement...
      mqttClient.publish("codigo/cpu", "Hello, I am ESP8266 :)");
    } else {
      Serial.print(".");
      delay(5000);
    }
  }
  return mqttClient.connected();
}
// ***************************************
// Funcion para desconectar de broker MQTT
bool mqttDisconnectGo(){
  mqttClient.disconnect();
  if (mqttClient.connected()){
    return false;
  }
  else {
    return true;
  }
}
// ***************************************
// Funcion para leer estado de MQTT
bool mqttStatus(){
  if (mqttClient.connected()){
    return true;
  }
  else {
    return false;
  }
}
// ***************************************
// Funcion para revision de protocolo MQTT
void mqttLoop(){
  mqttClient.loop();
}

// ***************************************
// FUNCIONES DE SETUP DE ESP8288
// ***************************************
// Funcion configurar el ESP8266
void setup() {
  Serial.begin(9600);
  delay(5000);
}

// ***************************************
// FUNCIONES DE BUCLE DE ESP8288
// ***************************************
// Funcion para el algortimo de ESP8266
void loop() {
  // Revision y ejecucion del protocolo MQTT
  if (wifiConnect){
    if (mqttConnect){
      if (!mqttClient.connected()) {
        mqttConnectGo();
      }
      else{   // Ejecutar siempre para las suscripciones
        mqttLoop();
      }
    }
    else{
      ;
    }
  }
  // No conectado conectado wifi
  else{
    ;
  }
  // -------------------------------------
  // Habilitado comando para comunicacion MQTT
  if (stateMqtt) {
    stateMqtt = false;  // Solo se ejecuta 1 vez
    Serial.print(inTopic);
    // ***********************************
    // -----------------------------------
    // Configurando nombre de Red WIFI
    if (inTopic == "wifi/ssid"){
      // Comando para escritura de nombre de Red Wifi
      if (modeMqtt){  
        // Almacenar nombre de Red Wifi                    
        wifiSsid = inMessage;
        Serial.println(">OK");         
      }
      // Comando para lectura de nombre de Red Wifi
      else{
        if (inMessage == "GET"){
          // Enviar nombre de Red Wifi
          Serial.println("<" + wifiSsid);
        }
        else{
          Serial.println("<ERROR");
        }
      }
    }
    // -----------------------------------
    // Configurando clave de Red WIFI
    else if (inTopic == "wifi/password"){
      // Comando para escritura de clave de Red Wifi
      if (modeMqtt){
        // Almacenar clave de Red Wifi                    
        wifiPassword = inMessage;
        Serial.println(">OK");         
      }
      // Comando para lectura de clave de Red Wifi
      else{
        if (inMessage == "GET"){
          // Enviar clave de Red Wifi
          Serial.print("<" + wifiPassword);
        }
        else{
          Serial.println("<ERROR");
        }
      }
    }
    // -----------------------------------
    // Comando para conexion de Red WIFI      
    else if (inTopic == "wifi/connect"){
      // Comando para control de conexion Red Wifi
      if (modeMqtt){
        // Conectar a Red Wifi configurada
        if (inMessage == "ON"){
          Serial.print(">ON>");
          if (connectWifi()){
            Serial.println(">OK");
            wifiConnect = true;
          }
          else{
            Serial.println(">ERROR");
            wifiConnect = false;
          }
        }
        // Desconectar de Red Wifi actual
        else if (inMessage == "OFF"){
          Serial.print(">OFF>");
          if (disconnectWifi()){
            Serial.println(">OK");
            wifiConnect = false;     
          }
          else{
            Serial.println(">ERROR");
            wifiConnect = true;
          }
        }
        // Resetear conexion de Red Wifi
        else if (inMessage == "RESET"){
          Serial.print(">RESET>");
          wifiConnect = false;
          if (resetWifi()){
            Serial.println(">OK");
            wifiConnect = true;     
          }
          else{
            Serial.println(">ERROR");
            wifiConnect = false;
          }
        }
        else{
          Serial.println(">ERROR");
        } 
      }
      // Comando para lectura de conexion Red Wifi
      else{
        // Leer Red Wifi configurada
        if (inMessage == "GET"){
          if (statusWifi()){
            Serial.println("<Connected to " + wifiSsid);
            wifiConnect = true;     
          }
          else{
            Serial.println("<Disconnected");
            wifiConnect = false;
          }
        }
        else{
          // Comando errado
          Serial.println("<ERROR");
        }
      }        
    }
    // ***********************************
    // -----------------------------------
    // Configurando servidor de connexion MQTT
    else if (inTopic == "mqtt/server"){        // URL o IP del servidor MQTT
      if (modeMqtt){
        mqttServer = inMessage;
        Serial.println(">OK");         
      }
      else{
        if (inMessage == "GET"){
          // Enviar nombre de Red Wifi
          Serial.println("<" + mqttServer);
        }
        else{
          Serial.println("<ERROR");
        }
      }
    }
    // -----------------------------------
    // Configurando puerto de connexion MQTT
    else if (inTopic == "mqtt/port"){     // Puerto de servidor MQTT
      if (modeMqtt){
        mqttPort = inMessage.toInt();
        Serial.println(">OK");         
      }
      else{
        if (inMessage == "GET"){
          // Enviar nombre de Red Wifi
          Serial.println("<" + String(mqttPort));
        }
        else{
          Serial.println("<ERROR");
        }
      }
    }
    // -----------------------------------
    // Configurando identificador de connexion MQTT
    else if (inTopic == "mqtt/id"){       // ID de servidor MQTT
      if (modeMqtt){
        mqttId = inMessage;
        Serial.println(">OK");         
      }
      else{
        if (inMessage == "GET"){
          // Enviar nombre de Red Wifi
          Serial.println("<" + mqttId);
        }
        else{
          Serial.println("<ERROR");
        }
      }        
    }
    // -----------------------------------
    // Configurando usuario de connexion MQTT
    else if (inTopic == "mqtt/user"){     // Usuario para servidor MQTT
      if (modeMqtt){
        mqttUser = inMessage;
        Serial.println(">OK");         
      }
      else{
        if (inMessage == "GET"){
          // Enviar nombre de Red Wifi
          Serial.println("<" + mqttUser);
        }
        else{
          Serial.println("<ERROR");
        }
      }        
    }
    // -----------------------------------
    // Configurando clave de connexion MQTT
    else if (inTopic == "mqtt/password"){ // Clave para servidor MQTT
      if (modeMqtt){
        mqttPassword = inMessage;
        Serial.println(">OK");         
      }
      else{
        if (inMessage == "GET"){
          // Enviar nombre de Red Wifi
          Serial.println("<" + mqttPassword);
        }
        else{
          Serial.println("<ERROR");
        }
      }        
    }
    // -----------------------------------
    // Configurando seguridad de connexion MQTT
    else if (inTopic == "mqtt/tls"){      // Comando para configurar la encriptacion
      if (modeMqtt){
        if (inMessage == "ON"){
          mqttTls = true;
          Serial.println(">OK");
        }
        else if (inMessage == "OFF"){
          mqttTls = false;        
          Serial.println(">OK");
        }
        else{
          Serial.println(">ERROR");
        }   
      }
      else{
        if (inMessage == "GET"){
          // Enviar nombre de Red Wifi
          Serial.print("<");
          if (mqttTls)
            Serial.println("ON");
          else 
            Serial.println("OFF");
        }
        else{
          Serial.println("<ERROR");
        }
      }       
    }
    // -----------------------------------
    // Configurando Identificador de connexion MQTT
    else if (inTopic == "mqtt/connect"){  // Comando para conectar a servidor MQTT
      if (modeMqtt){
        if (inMessage == "ON"){
          Serial.print(">ON>");
          mqttSetup();
          if (mqttConnectGo()){
            Serial.println(">OK");
            mqttConnect = true;
          }
          else{
            Serial.println(">ERROR");
            mqttConnect = false;
          }
        }
        else if (inMessage == "OFF"){
          Serial.print(">OFF>");
          if (mqttDisconnectGo()){
            Serial.println("OK");
            mqttConnect = false;
          }
          else{
            Serial.println("ERROR");
            mqttConnect = true;
          }
        }
        else{
          Serial.println(">ERROR");
        }
      }
      else{
        // Leer conexión MQTT
        if (inMessage == "GET"){
          if (mqttStatus()){
            Serial.println("<Connected to " + mqttServer);
            mqttConnect = true;     
          }
          else{
            Serial.println("<Disconnected");
            mqttConnect = false;
          }
        }
        else{
          // Comando errado
          Serial.println("<ERROR");
        }
      }
    }
    // ***********************************
    // -----------------------------------
    // Realizando acciones de protocolo MQTT
    else{
      if (wifiConnect){
        if (mqttConnect){
          if (modeMqtt){
            inMessage.toCharArray( messageArray, 100 );
            inTopic.toCharArray( topicArray, 100 );
            mqttClient.publish(topicArray, messageArray);
            Serial.print(">");
            Serial.println(inMessage);
          }
          else{
            inTopic.toCharArray( topicArray, 100 );
            mqttClient.subscribe(topicArray);
            Serial.print("<");
            Serial.println(inTopic);
          }
        }
        else{
          Serial.println(">Error, no conectado a broker MQTT");
        }
      }
      else {
        Serial.println(">Error, no conectado a red wifi");
      }
    }
  }
  // No habilitado para comunicación MQTT
  else{
    ;
  }
}
void serialEvent() {
  while (Serial.available()) {
    inChar = (char)Serial.read();
    switch (inChar){
      case '\r':
        inMessage = inString;
      break;
      case '\n':
        inString = "";
        stateMqtt = true;
      break;
      case '>':
        inTopic = inString;
        inString = "";
        modeMqtt = true;
      break;
      case '<':
        inTopic = inString;
        inString = "";
        modeMqtt = false;
      break;
      default:
        inString += inChar;
      break;
    }
  }
}

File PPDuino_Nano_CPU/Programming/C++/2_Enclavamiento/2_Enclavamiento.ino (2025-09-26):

const int pinPulsador = 17; // cambia según tu placa
const int pinSalida   = 9;  // cambia según lo que necesites
// variables anti-rebote
unsigned long lastDebounceTime = 0;
const unsigned long debounceDelay = 50; // ms
int lastButtonState = HIGH; // porque usamos INPUT
int buttonState = HIGH;
bool salidaLatched = false; // estado enclavado (false = apagado)

void setup() {
  pinMode(pinPulsador, INPUT);
  pinMode(pinSalida, OUTPUT);
  digitalWrite(pinSalida, LOW); // estado inicial
}

void loop() {
  int reading = digitalRead(pinPulsador);
  if (reading != lastButtonState) {
    // reiniciar contador de rebote
    lastDebounceTime = millis();
  }
  if ((millis() - lastDebounceTime) > debounceDelay) {
    // si ha pasado el tiempo de debounce y cambió el estado real
    if (reading != buttonState) {
      buttonState = reading;
      // detectar flanco de presionado (HIGH -> LOW con INPUT_PULLUP)
      if (buttonState == LOW) {
        // cambiar (toggle) el estado de la salida
        salidaLatched = !salidaLatched;
        digitalWrite(pinSalida, salidaLatched ? HIGH : LOW);
      }
    }
  }
  lastButtonState = reading;
}

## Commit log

2024-12-06 Organizado los archivo base iniciales
    [Base.FCStd, PPDuino_Nano.kicad_pcb, PPDuino_Nano.kicad_sch]
2025-07-18 Update 1
    [Arduino Nano V3.step, Arduino NanoV3 + Female Headers.step, Borneras DG128-5.0-02.stp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]
2025-07-18 PCB Complete
    [PPDuino Nano Entradas.kicad_pcb, PPDuino Nano Salidas.kicad_pcb, PPDuino Nano Salidas.kicad_sch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]
2025-07-21 Actualizar documentacion 1
    [Base.FCStd, Caja.FCStd, Tapa1_Superior Final.f3d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]
2025-07-22 Actualizar documentacion 2
    [PPDuino Nano Entradas.kicad_pcb, PPDuino Nano Entradas.kicad_sch, PPDuino Nano Salidas.kicad_pcb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]
2025-07-25 Actualizando 5
    [PPDuino Nano Entradas.kicad_pcb, PPDuino Nano Entradas.kicad_sch, PPDuino Nano Salidas V2.step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]
2025-08-04 Actualizando datos
    [PPDuino Nano Entradas.kicad_pcb, PPDuino Nano Entradas.kicad_sch, PPDuino Nano Salidas V2.step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]
2025-08-04 Actualizando datos 3
    [PPDuino Nano Salidas V2.step]
2025-08-05 PCB V0.2
    [PPDuino Nano Entradas-B_Cu.gbr, PPDuino Nano Entradas-B_Mask.gbr, PPDuino Nano Entradas-B_Paste.gbr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]
2025-08-13 Actualizando Arduino IDE
2025-09-18 Tabla Procesador
    [PPDuino_Nano_Procesador.csv, PPDuino_Nano_Procesador.kicad_sch, PPDuino_Nano_Procesador.xlsx]
2025-09-18 Tabla entrada
    [PPDuino Nano Entradas.csv, PPDuino Nano Entradas.kicad_sch, PPDuino Nano Entradas.xlsx]
2025-09-18 Tabla entrada2
    [PPDuino Nano Entradas.xlsx]
2025-09-18 Tabla salida
    [PPDuino Nano Salidas.csv, PPDuino Nano Salidas.kicad_sch, PPDuino Nano Salidas.xlsx]
2025-09-18 Tabla procesador png 3
    [PPDuino Nano Procesador.csv, PPDuino Nano Procesador.kicad_pcb, PPDuino Nano Procesador.kicad_sch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]
2025-09-19 All updated
    [PPDuino Nano Procesador.kicad_pcb]
2025-09-22 All updated 2
    [VARIABLES.csv]
2025-09-22 All updated 3
    [Arduino Nano V3.step, Arduino NanoV3 + Female Headers.step, Borneras DG128-5.0-02.stp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]
2025-09-22 All updated 4
    [PPDuino Nano Entradas-B_Cu.gbr, PPDuino Nano Entradas-B_Mask.gbr, PPDuino Nano Entradas-B_Paste.gbr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]
2025-09-22 All updated 5
    [Arduino Nano V3.step, Arduino NanoV3 + Female Headers.step, Borneras DG128-5.0-02.stp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]
2025-09-22 Update the modulo wifi
    [CE3E3V2_Tapa1_Superior Final.3mf]
